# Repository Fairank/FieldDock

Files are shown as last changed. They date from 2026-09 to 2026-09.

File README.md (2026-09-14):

# FieldDock · Fairank / 年糕

面向 iPhone 17 Pro Max 的模块化无线与硬件实验工具。主板将 Sub-GHz、NFC、125 kHz RFID、红外、iButton、GPIO 和存储接口集中在 **94 × 40 mm** 的板上；手机承担未来的界面和结果处理。

**K 版全板布线与数字制造文件检查已完成。当前发布的是未制作、未上电的工程样板设计，尚未完成整机装配采购放行，也没有 Apple 认证或 Flipper 功能等效实测。**

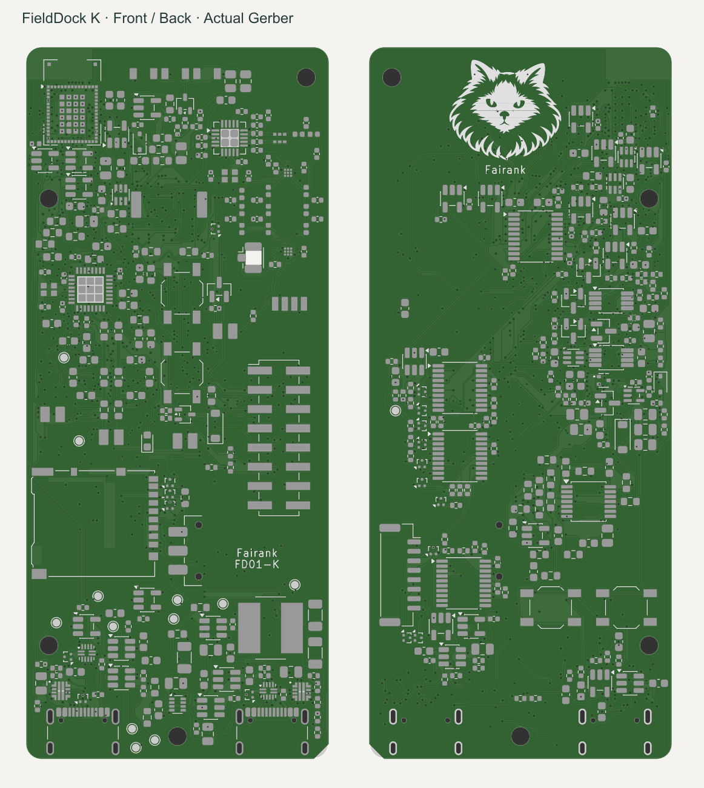
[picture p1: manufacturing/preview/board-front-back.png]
从实际 Gerber 渲染的主板正反面，带 Fairank 与年糕丝印


## 本次交付

| 内容 | 文件 | 当前状态 |
|---|---|---|
| 可编辑电路与 PCB | [KiCad 工程](cad/FD-MAIN-01.kicad_pro)、[主板](cad/FD-MAIN-01.kicad_pcb)、[22 页原理图 PDF](schematic/FieldDock-schematic-K.pdf) | 全板布线；KiCad 10.0.6 ERC/DRC 通过 |
| 制造资料 | [Gerber / 钻孔 ZIP](manufacturing/FieldDock-PCB-K-fabrication.zip)、[加工要求](manufacturing/PROCESS-K.md)、[文件说明](manufacturing/README.md) | 已导出并独立核对几何；供应商 CAM 接单确认待完成 |
| 元件与贴装 | [BOM 复核表](manufacturing/BOM-review.csv)、[395 件贴装坐标](manufacturing/FD-MAIN-01-populated-pos.csv) | 位置已核对；部分采购料号、替代料和底面角度约定待厂家确认 |
| 结构设计 | [STEP / STL 模型包](mechanical/FieldDock-mechanical-K.zip)、[参数与生成脚本](mechanical/) | 16 个零件及组件包络；安装孔对应一致，未做实物公差验证 |
| 基础驱动 | [C 驱动与主机测试](firmware/) | CC1101 识别读取、电源预算策略、GPIO 映射；没有完整可烧录固件 |
| 可审阅证据 | [发布状态](release-status.json)、[检查记录](checks/)、[验证说明](VALIDATION.md) | 对应本次文件哈希 |

## 检查结果

- PCB DRC：**0 未连接、0 错误、0 警告**；原理图 ERC：**0 违规**。启用范围与五项默认忽略规则保留在原始报告中，不表示所有可选规则都已执行。
- 原理图、最终 PCB 和布线模型：**1,260 个已分配引脚连接一致**；57 个明确标记的未使用引脚单独核对。
- 独立 Gerber/Excellon 解析：核对 **11,385 段走线、899 个贯穿过孔、907 个金属化钻孔/槽、10 个非金属化孔**，八层铜、外形和装配坐标一致。
- 机械包络检查：50 对检查对象，无非预期交叠；4 处自攻螺钉与底孔材料交叠为设计预期。它不包含尺寸公差、插拔力和线束弯曲验证。
- 基础驱动通过主机测试与 Cortex-M4 freestanding 对象编译；尚未链接整机镜像或上板测试。

```sh
python tools/verify_artifacts.py
python tools/verify_artifacts.py --release
```

第二条命令核验本版**裸 PCB 工程样板文件**的数字检查条件，不代表供应商已接单、整机可量产或硬件功能已通过。脚本不会自动运行 KiCad。

## 硬件范围

主控为 STM32WB5MMG，射频采用 CC1101 与 ST25R3916，并设 LF RFID、红外、iButton、隔离 GPIO、microSD 及反馈控制电路。Sub-GHz、NFC 和 LF 的完整协议、读写能力与距离需要固件和样板分别验证。

两个 USB-C 分别用于手机数据/低功率输入与 AUX 固定 5 V 辅助输入，包含电源选择、限流和反向电流保护设计。**本版不含电池；两个端口的电流预算不能相加。** USB 为全速 12 Mbit/s，iPhone App 的有线数据通道尚未完成。没有增加所谓“iPhone 芯片”。

CSI、雷达、UWB、宽带 SDR、热成像和镜头检查作为外部探头方向保留；本次主板发布不等于这些探头及其算法已全部实现。Flipper 官方功能是参考目标，并未复制其固件或宣称兼容替代。仓库不包含无线网络干扰功能。

八层、1.6 mm、沉金、所有贯穿过孔树脂填孔盖帽；使用 0.30/0.15 mm 和 0.35/0.20 mm 过孔。**0.15 mm 机械钻孔是非常规加价工艺**，须按 [加工规格](manufacturing/PROCESS-K.md) 单独确认，不能按普通双层板下单。主板下单前须让厂家确认最终 CAM、叠层、填孔和阻抗条件。

## 外壳与安装

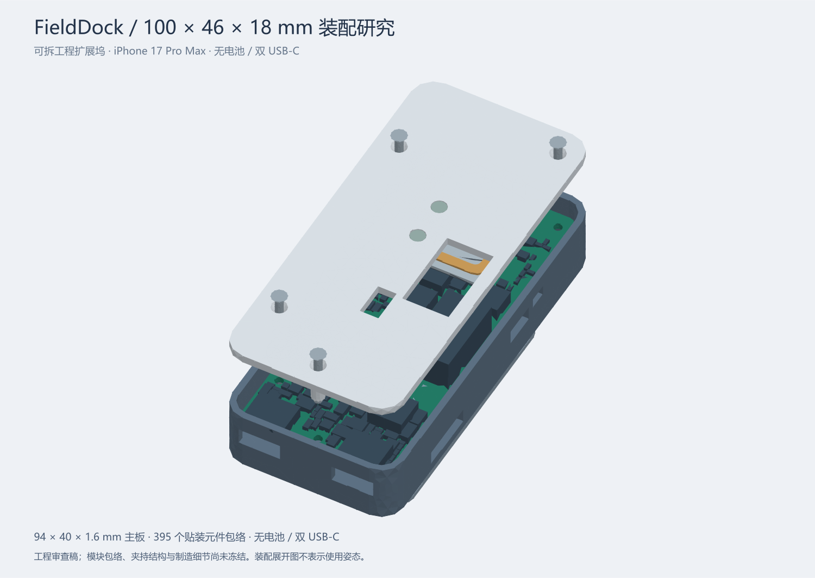
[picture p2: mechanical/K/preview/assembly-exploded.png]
机械组件与内部安装包络


外壳目标 100 × 46 × 18 mm，安装背板另占约 1.6 mm。提供参数化源码、装配 STEP 以及各零件 STEP/STL；内部电子元件使用保守包络，并非全部来自原厂的精确三维模型。接口插拔、手机摄像头避让、固定强度、天线线圈与装壳后的射频表现仍需试装。

## 预算与后续验证

[工程预算](manufacturing/BUDGET-K.md)：单套核心样机约 **¥1,534–3,820**；两套合计约 **¥2,049–4,941**。这些是估算，**均未包含尚未报价的 0.15 mm 钻孔附加费**，也不含手机、外部探头、射频调试和返版，不是最终价格上限。没有下单或取得厂家正式报价。

下一步是供应商 CAM 与料号确认、限流上电、电源切换/倒灌测试、射频与线圈调谐、手机通信以及外壳试装。详见 [验证顺序](VALIDATION.md)。原生图纸保留设计过程的标题栏版本；本次发布以 `release-status.json` 和文件校验清单确定对应关系。

## 署名和使用

Copyright © 2026 fairank，限其依法可保护并有权许可的原创贡献。年糕图标为本项目品牌。

原创贡献以 [FieldDock 非商业许可](LICENSE) 提供源码，个人可委托收费代工制作自用样机；对许可材料的商业使用需另行获得书面许可。这是 **noncommercial source-available** 项目，不使用 OSI 开源标识。KiCad 库及其衍生部分保留上游许可，见 [第三方说明](THIRD_PARTY_NOTICES.md) 和 [逐文件来源清单](licensing/library-inventory.csv)。不主张对通用电路方法、技术事实或独立实现的排他权。

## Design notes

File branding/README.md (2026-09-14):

# 共用年糕标志

唯一母版：niangao-master-v1.png。SHA256: 187738542cc2ea14bfb01165dacbc974479dd0d5b0aa6698a0179235dfb1e737。使用用户在关联设计任务明确选定、并授权两个任务同步的同一版本。

母版由内置 image_gen 参考年糕照片生成；共享 SVG / contours.json 为该母版的等比矢量化，未另画猫脸。本项目的早期小尺寸重绘试稿已停用。

当前 PCB：背面原图宽 14.8 mm，下方 Fairank；正面 Fairank 和 FD01-H。背面保留区域 16×16 mm。为 KiCad 分解的无孔多边形与母版轮廓总面积一致，原生绘图只落在丝印层。

细毛边缘和小空隙受实际丝印能力限制，仍需工艺样张确认；不能把软件几何检查当作印刷精度实测。电路、封装与铜层位置没有改变。

不随公开包提供用户照片或附件绝对路径。品牌资产本身的 AI 辅助来源须保留，不保证所有图像元素均有排他版权。

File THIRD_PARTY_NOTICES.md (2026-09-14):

# 第三方来源与发布范围

2026-09-09。本清单与 licensing/FILE-REVIEW.md、licensing/library-inventory.csv 共同记录本次文件审查范围，不把“网上公开”视为可任意再授权。

| 材料 | 已查明条件 | 本项目处理 |
|---|---|---|
| KiCad 官方符号、封装库及本地库集合 | CC BY-SA 4.0，电子设计适用库例外；重新分发库集合仍须保留其许可 | 保留 cad/licenses/KiCad-libraries-LICENSE.md；库集合不附加禁止商用限制；混合符号库中的两个 MOSFET 派生符号保留上游许可，其余项目自制符号按文件审查表区分 |
| Flipper 官方固件 | GPL-3.0，允许商业使用 | 当前新建基础驱动不复制该固件；未来若引入或构成衍生程序，须按其许可处理，不能统一改成 NC |
| Flipper 官方 3D 模型 | 官方仓库 LICENSE 为 GPL-3.0 | 不将其模型放入我们的 NC 模型包；当前外壳来自本项目参数化构造及元件包络，具体源文件边界见文件审查表 |
| Flipper 官方 iOS App | MIT | 尚未复制；若复用保留版权和许可证，不声称独占第三方实现 |
| Flipper 官方电路图 | 文档页写明 educational purposes only；未从该页面查得全套可再授权条款 | 当前 NFC/LF 电路参考过其拓扑，RF 参考过功能分区；本次逐项记录见 licensing/FILE-REVIEW.md；不分发官方电路图、固件、CAD 坐标或模型，不对参考功能、事实或上游作品附加本项目 NC 限制；不因重绘就宣称清除权利问题 |
| 元件厂商数据手册与参考电路 | 条款随厂商和具体资源不同 | 发布自行撰写的参数/接线解释和来源链接；工作目录中的 PDF、截图不自动打包 |
| KiCad、Freerouting、Java、Python、Zig 等工具 | 各有独立许可证 | 只用于生成和验证，不随项目源码包分发可执行文件和缓存；使用工具不等于复制其程序代码 |

依据：[KiCad 库许可](https://www.kicad.org/libraries/license/)、[Flipper 固件许可](https://github.com/flipperdevices/flipperzero-firmware/blob/dev/LICENSE)、[Flipper 模型许可](https://github.com/flipperdevices/flipperzero-3d-models/blob/master/LICENSE)、[Flipper iOS 许可](https://github.com/flipperdevices/Flipper-iOS-App/blob/dev/LICENSE)、[官方电路图说明](https://docs.flipper.net/zero/development/hardware/schematic)。

目录隔离只是工程整理方法，不能自动使本来构成衍生作品或组合程序的材料摆脱上游许可。

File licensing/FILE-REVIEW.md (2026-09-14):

# 发布文件的来源核查

2026-09-09。核查范围为当前项目源文件、生成方法及拟发布清单；本记录不承诺诉讼结果或排他技术权利。

- **电路描述和生成程序**：`radio_circuit.py`、`nfc_circuit.py`、`lf_circuit.py` 及其余电路文件是本项目编写的引脚表、连接表和生成代码。NFC/LF 的功能拓扑参考过 Flipper 公布的电路资料，RF 的功能分区亦有参考，必须保留这个来源说明。没有将 Flipper 的原 PDF、页面截图、原 CAD、丝印图或图纸坐标文件纳入发布。不能据此主张对相同功能、电气方法或元件数值的排他权；项目许可只覆盖可保护且由 fairank 有权许可的新增代码、文字和设计表达。
- **原生主板和原理图**：本项目的元件位置、线网命名、分页、布线、安装孔和品牌图形由本地设计过程产生。嵌入的 KiCad 符号与封装保持第三方来源，电子设计适用 KiCad 的库例外。禁止把独立库集合统一改成 NC。
- **标准 KiCad 库子集**：`cad/symbols/` 中除下述原创符号外的符号，以及 `cad/footprints/` 中标准库目录，适用 CC BY-SA 4.0 及 KiCad 库例外。作者为 KiCad 库贡献者；本项目执行了子集抽取、部分封装设置整理和引脚号调整。逐文件哈希及分类见 `library-inventory.csv`，原许可在 `cad/licenses/`。
- **混合符号库 `FieldDock.kicad_sym`**：`Q_PMOS_GSD_FD` 和 `Q_NMOS_GSD_FD` 是 KiCad MOSFET 符号的改名和引脚映射修改，继续适用 CC BY-SA 4.0 及库例外。本文件其余以矩形引脚表绘制的器件符号由项目编写，原创表达适用 FieldDock NC；库文件作为集合分发时必须保留两种许可及此逐符号说明，不得用 NC 限制其中的 KiCad 部分。
- **原创封装**：`FieldDock.pretty/` 的九个封装及 `MountingHole.pretty/MountingHole_2.4mm_M2.kicad_mod` 按器件尺寸和安装要求构造。其可保护的原创表达适用 NC；封装尺寸和通用焊盘规则是技术事实。
- **机械模型**：由本项目参数化盒体、孔、柱、盖、支架、线圈和保守器件包络构造。未导入 Flipper STEP/STL 文件。模型的尺寸与可制造性仍由机械检查和实物验证记录分别说明。
- **基础驱动**：CC1101 寄存器识别与电源许可状态逻辑为新写的 C 代码，未复制 Flipper GPL 固件。将来若引入 GPL 程序或构成其衍生实现，需另行按 GPL 处理，不能沿用 NC 覆盖上游代码。
- **品牌**：Fairank 署名及用户选定的 Niangao v1 母版。图形有 AI 辅助过程，不承诺所有部分自动取得著作权；不公开用户提供的猫照片、私人聊天或账号信息。
- **不随项目分发**：KiCad/Java/Freerouting/Zig/Python/Gmsh 可执行文件、插件、依赖缓存、厂商整份 PDF、网页截图、账户凭据和本地故障日志。

功能参考：[Flipper 官方电路资料](https://docs.flipper.net/zero/development/hardware/schematic)。库条件：[KiCad 官方许可说明](https://www.kicad.org/libraries/license/)。这些引用不代表上游授权 FieldDock 使用其商标、原始图纸或整个项目，也不代表任何上游认可本设计。

C712 uses `C_0402_1005Metric_FieldDock_NoSilk`, derived from the KiCad standard footprint with only its outline silk removed. Its land and courtyard geometry is unchanged. This derivative remains CC BY-SA 4.0 with the KiCad library exception, and is listed in the file inventory.

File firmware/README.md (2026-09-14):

# FieldDock 基础 C 驱动

Copyright (c) 2026 fairank。原创文件适用 LicenseRef-FieldDock-NC-1.0。未复制 Flipper 固件或 ST HAL 实现。

当前包含：CC1101 的 SPI PARTNUM/VERSION 读取、共享总线锁定及错误清理；双口供电预算纯函数；从当前原理图资源表生成的 60 个 GPIO 映射。来源是本项目接线表及 [TI CC1101 数据手册](https://www.ti.com/lit/ds/symlink/cc1101.pdf) 的协议事实。状态寄存器必须逐字节读取，每次头字节设置读和 burst 位，不能误用连续自增读取。

`fd_power_evaluate()` 只计算许可输出；实际电压检测、TUSB320LAI 寄存器读取、热点切换处理、上电等待、GPIO 顺序、USB 枚举、RTOS/中断和 STM32WB 启动链接均未实现。它不能独立控制硬件，也不能被称为可烧录整机固件。MCU 复位到主循环前的上拉/下拉和最低启动电流需硬件验证。

对缺失、过期或无效电源报告保持低额度；AUX 有电但额度不足时，不错误借用手机额度。核心电流预算不能把两个端口相加；外部探头只允许 AUX 3 A 广告条件，且仍受板上支路上限限制。预算常量来自当前阻值计算，样板实测后仍需复核。

编译：使用 C99 编译器把 `src/fd_cc1101.c`、`src/fd_power.c`、`tests/test_core.c` 一起编译，头文件路径设为 `include`，然后运行生成的主机测试程序。`tools/verify.py` 接受 Zig 可执行文件路径，将主机测试和 Cortex-M4 freestanding 对象编译结果保存到 build/。对象编译不是完整镜像链接、烧录或上板验证。

NFC、LF RFID、红外、iButton、microSD 和探头协议实现待后续添加；不会用空函数伪装成已支持功能。

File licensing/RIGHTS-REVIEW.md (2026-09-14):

# fairank 的非商业发布安排

目标：原创成果免费供非商业学习、修改和自用，商业使用另行取得书面许可。使用“源码公开 / source available”，不宣传为符合 OSI 定义的开源。OSI 定义不允许禁止商业领域使用。[OSI 定义第 6 条](https://opensource.org/osd)

当前采用项目专用 NC 条款，并为个人样机委托收费代工明确例外。否则“一律禁止盈利”会与我们需要找厂商加工相冲突。该条款只覆盖可由 fairank 许可的原创部分，不能覆盖第三方许可或不受著作权保护的技术思想。

工程图、模型和软件可能属于著作权保护对象，但需满足独创性等条件；署名和公开仓库不是胜诉保证。特别是 AI 辅助生成部分，应保存人的需求选择、设计修改、评审和实测记录，不宣称所有输出自动取得排他版权。[国家版权局公布的著作权法，第 3、11、12 条](https://www.ncac.gov.cn/xxfb/flfg/flfg_532/202103/t20210309_50530.html)

GPL 本身允许商业分发，不能给 GPL 衍生程序附加禁止商业用途的限制。需要独立实现、得到相关权利人的其他授权，或按上游许可发布相应作品；仅拆目录不足以解决衍生关系。[GNU GPL FAQ](https://www.gnu.org/licenses/gpl-faq.en.html)

本次具体文件的来源与许可边界记录在 FILE-REVIEW.md、library-inventory.csv 和 provenance.csv；任何后续引入的第三方材料均需更新此记录。项目专用授权是工程草案，不是诉讼结果保证；若商业排他和维权是关键目的，正式公开前适合由熟悉软件/硬件许可的律师审阅。不要上传完整聊天、账号邮箱、缓存、访问令牌或不必要的本机路径。

版权保护作品表达，并不当然垄断功能和技术方案；硬件制造、外观及技术方案还可能涉及专利、外观设计等不同权利。公开前需要决定是否另行评估这些权利，不能把 NC 文本当作已有专利。

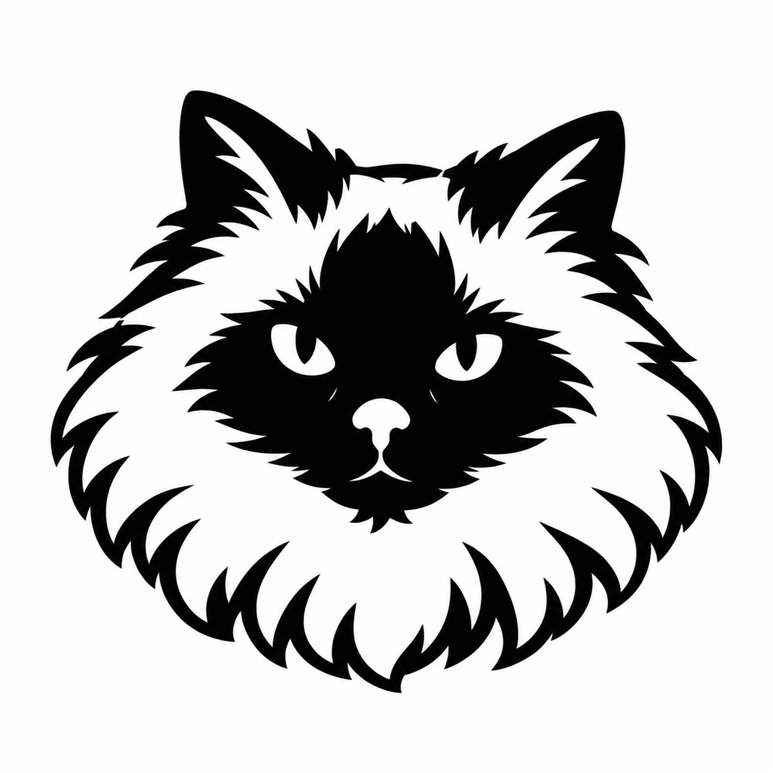
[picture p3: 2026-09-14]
branding/niangao-master-v1.png

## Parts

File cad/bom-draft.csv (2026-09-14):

Reference | Value | Footprint | Section | Status
U1 | STM32WB5MMGH6TR | RF_Module:ST-SiP-LGA-86-11x7.3mm | mcu | Engineering revision C
U2 | SN74LVC1G08DBVR | Package_TO_SOT_SMD:SOT-23-5 | controls | Engineering revision C
R1 | 0R analog feed | Resistor_SMD:R_0603_1608Metric | mcu | Engineering revision C
R2 | 10k BOOT pulldown | Resistor_SMD:R_0603_1608Metric | mcu | Engineering revision C
R3 | 10k | Resistor_SMD:R_0603_1608Metric | controls | Engineering revision C
R4 | 10k | Resistor_SMD:R_0603_1608Metric | controls | Engineering revision C
R5 | 100k | Resistor_SMD:R_0603_1608Metric | controls | Engineering revision C
R6 | 100k | Resistor_SMD:R_0603_1608Metric | controls | Engineering revision C
R7 | 100k | Resistor_SMD:R_0603_1608Metric | controls | Engineering revision C
R8 | 4.7k | Resistor_SMD:R_0603_1608Metric | mcu | Engineering revision C
R9 | 4.7k | Resistor_SMD:R_0603_1608Metric | mcu | Engineering revision C
R10 | 47k | Resistor_SMD:R_0603_1608Metric | mcu | Engineering revision C
R11 | 47k | Resistor_SMD:R_0603_1608Metric | mcu | Engineering revision C
R12 | 47k | Resistor_SMD:R_0603_1608Metric | mcu | Engineering revision C
R13 | 47k | Resistor_SMD:R_0603_1608Metric | mcu | Engineering revision C
R14 | 10k | Resistor_SMD:R_0603_1608Metric | mcu | Engineering revision C
R15 | 1k BOOT series | Resistor_SMD:R_0603_1608Metric | controls | Engineering revision C
R16 | 1k LED | Resistor_SMD:R_0603_1608Metric | controls | Engineering revision C
C1 | 4.7u 10V X7R | Capacitor_SMD:C_0805_2012Metric | mcu | Engineering revision C
C2 | 100n 10V X7R | Capacitor_SMD:C_0603_1608Metric | mcu | Engineering revision C
C3 | 1u 10V X7R | Capacitor_SMD:C_0603_1608Metric | mcu | Engineering revision C
C4 | 10n 10V X7R | Capacitor_SMD:C_0603_1608Metric | mcu | Engineering revision C
C5 | 100n RESET | Capacitor_SMD:C_0603_1608Metric | mcu | Engineering revision C
C6 | 100n USB supply | Capacitor_SMD:C_0603_1608Metric | mcu | Engineering revision C
C7 | 100n gate supply | Capacitor_SMD:C_0603_1608Metric | controls | Engineering revision C
C8 | 10u 10V X7R | Capacitor_SMD:C_0805_2012Metric | mcu | Engineering revision C
SW1 | RESET | Button_Switch_SMD:SW_SPST_TL3342 | controls | Engineering revision C
SW2 | CONFIRM | Button_Switch_SMD:SW_SPST_TL3342 | controls | Engineering revision C
SW3 | STOP_REQUEST | Button_Switch_SMD:SW_SPST_TL3342 | controls | Engineering revision C
SW4 | HARD_DISABLE / ALLOW | Button_Switch_SMD:SW_SPDT_CK_JS102011SAQN | controls | Engineering revision C
SW5 | BOOT_HOLD | Button_Switch_SMD:SW_SPST_TL3342 | controls | Engineering revision C
D1 | STATUS_LED | LED_SMD:LED_0603_1608Metric | controls | Engineering revision C
U201 | TPS2116DRLR | Package_TO_SOT_SMD:SOT-583-8 | core_power | Engineering revision C
R201 | 330k 1% | Resistor_SMD:R_0603_1608Metric | core_power | Engineering revision C
R202 | 100k 1% | Resistor_SMD:R_0603_1608Metric | core_power | Engineering revision C
R203 | 10k 1% | Resistor_SMD:R_0603_1608Metric | core_power | Engineering revision C
C201 | 4.7u 10V X7R | Capacitor_SMD:C_0805_2012Metric | core_power | Engineering revision C
C202 | 4.7u 10V X7R | Capacitor_SMD:C_0805_2012Metric | core_power | Engineering revision C
C203 | 22u 10V X7R | Capacitor_SMD:C_1206_3216Metric | core_power | Engineering revision C
U202 | AP63203WU-7 | Package_TO_SOT_SMD:TSOT-23-6 | core_power | Engineering revision C
L201 | 4.7uH SRN8040TA-4R7M | Inductor_SMD:L_Bourns_SRN8040TA | core_power | Engineering revision C
C204 | 100n 25V X7R | Capacitor_SMD:C_0402_1005Metric | core_power | Engineering revision C
C205 | 10u 10V X7R | Capacitor_SMD:C_0805_2012Metric | core_power | Engineering revision C
C206 | 22u 10V X7R | Capacitor_SMD:C_1206_3216Metric | core_power | Engineering revision C
C207 | 22u 10V X7R | Capacitor_SMD:C_1206_3216Metric | core_power | Engineering revision C
R204 | 0R FB sense | Resistor_SMD:R_0603_1608Metric | core_power | Engineering revision C
J101 | GCT USB4105-GF-A / PHONE USB2 FS + 5V | Connector_USB:USB_C_Receptacle_GCT_USB4105-xx-A_16P_TopMnt_Horizontal | phone_input | Engineering revision C
J102 | GCT USB4105-GF-A / AUX 5V input only | Connector_USB:USB_C_Receptacle_GCT_USB4105-xx-A_16P_TopMnt_Horizontal | aux_input | Engineering revision C
D101 | TPD2EUSB30DRTR | Package_TO_SOT_SMD:Texas_DRT-3 | phone_input | Engineering revision C
U301 | TPS22919DCKR | Package_TO_SOT_SMD:SOT-363_SC-70-6 | storage | Engineering revision C
U302 | 74LVC125APW,118 Nexperia | Package_SO:TSSOP-14_4.4x5mm_P0.65mm | storage | Engineering revision C
U303 | SN74LVC1G32DBVR | Package_TO_SOT_SMD:SOT-23-5 | storage | Engineering revision C
J301 | DM3AT-SF-PEJM5 | Connector_Card:microSD_HC_Hirose_DM3AT-SF-PEJM5 | storage | Engineering revision C
D301 | TPD2EUSB30DRTR | Package_TO_SOT_SMD:Texas_DRT-3 | storage | Engineering revision C
D302 | TPD2EUSB30DRTR | Package_TO_SOT_SMD:Texas_DRT-3 | storage | Engineering revision C
D303 | TPD2EUSB30DRTR | Package_TO_SOT_SMD:Texas_DRT-3 | storage | Engineering revision C
R301 | 100R QOD | Resistor_SMD:R_0603_1608Metric | storage | Engineering revision C
R302 | 100k | Resistor_SMD:R_0603_1608Metric | storage | Engineering revision C
R303 | 22R clock damping | Resistor_SMD:R_0603_1608Metric | storage | Engineering revision C
R304 | 22R command damping | Resistor_SMD:R_0603_1608Metric | storage | Engineering revision C
R305 | 22R MISO damping | Resistor_SMD:R_0603_1608Metric | storage | Engineering revision C
R306 | 10k default isolated | Resistor_SMD:R_0603_1608Metric | storage | Engineering revision C
R307 | 47k | Resistor_SMD:R_0603_1608Metric | storage | Engineering revision C
R308 | 47k | Resistor_SMD:R_0603_1608Metric | storage | Engineering revision C
R309 | 47k | Resistor_SMD:R_0603_1608Metric | storage | Engineering revision C
R310 | 47k | Resistor_SMD:R_0603_1608Metric | storage | Engineering revision C
R311 | 47k | Resistor_SMD:R_0603_1608Metric | storage | Engineering revision C
R312 | 47k | Resistor_SMD:R_0603_1608Metric | storage | Engineering revision C
R313 | 1k detect series | Resistor_SMD:R_0603_1608Metric | storage | Engineering revision C
R314 | 100k | Resistor_SMD:R_0603_1608Metric | storage | Engineering revision C
R315 | 100k | Resistor_SMD:R_0603_1608Metric | storage | Engineering revision C
R316 | 10k | Resistor_SMD:R_0603_1608Metric | storage | Engineering revision C
C301 | 1u 10V X7R | Capacitor_SMD:C_0603_1608Metric | storage | Engineering revision C
C302 | 10u 10V X7R | Capacitor_SMD:C_0805_2012Metric | storage | Engineering revision C
C303 | 100n 10V X7R | Capacitor_SMD:C_0603_1608Metric | storage | Engineering revision C
C304 | 100n 10V X7R | Capacitor_SMD:C_0603_1608Metric | storage | Engineering revision C
C305 | 100n 10V X7R | Capacitor_SMD:C_0603_1608Metric | storage | Engineering revision C
C306 | 10n detect filter | Capacitor_SMD:C_0603_1608Metric | storage | Engineering revision C
U110 | TUSB320LAIRWBR | Package_DFN_QFN:Texas_X2QFN-12_1.6x1.6mm_P0.4mm | phone_input | Engineering revision C
R110 | 887k 1% | Resistor_SMD:R_0402_1005Metric | phone_input | Engineering revision C
C110 | 100n 10V X7R | Capacitor_SMD:C_0603_1608Metric | phone_input | Engineering revision C
D110 | TPD2EUSB30DRTR | Package_TO_SOT_SMD:Texas_DRT-3 | phone_input | Engineering revision C
U111 | TPS259470LRPWR | FieldDock:Texas_RPW0010A | phone_input | Engineering revision C
R112 | 470k 1% | Resistor_SMD:R_0402_1005Metric | phone_input | Engineering revision C
R113 | 34.8k 0.1% | Resistor_SMD:R_0402_1005Metric | phone_input | Engineering revision C
R114 | 10.0k 0.1% | Resistor_SMD:R_0402_1005Metric | phone_input | Engineering revision C
R115 | 6.65k 1% | Resistor_SMD:R_0402_1005Metric | phone_input | Engineering revision C
C111 | 1u 50V X7R | Capacitor_SMD:C_0805_2012Metric | phone_input | Engineering revision C
C112 | 10n 50V X7R | Capacitor_SMD:C_0603_1608Metric | phone_input | Engineering revision C
C113 | 1u 10V X7R | Capacitor_SMD:C_0603_1608Metric | phone_input | Engineering revision C
U112 | TPS2553DBVR | Package_TO_SOT_SMD:SOT-23-6 | phone_input | Engineering revision C
U113 | TS5A3159ADBVR | Package_TO_SOT_SMD:SOT-23-6 | phone_input | Engineering revision C
R116 | 64.9k 1% | Resistor_SMD:R_0402_1005Metric | phone_input | Engineering revision C
U114 | SN74LVC1G08DBVR | Package_TO_SOT_SMD:SOT-23-5 | phone_input | Engineering revision C
R117 | 100k 1% | Resistor_SMD:R_0402_1005Metric | phone_input | Engineering revision C
R118 | 100k 1% | Resistor_SMD:R_0402_1005Metric | phone_input | Engineering revision C
C114 | 100n 10V X7R | Capacitor_SMD:C_0603_1608Metric | phone_input | Engineering revision C
C115 | 100n 10V X7R | Capacitor_SMD:C_0603_1608Metric | phone_input | Engineering revision C
R119 | 100k 1% | Resistor_SMD:R_0402_1005Metric | phone_input | Engineering revision C
R120 | 100k 1% | Resistor_SMD:R_0402_1005Metric | phone_input | Engineering revision C
U150 | TUSB320LAIRWBR | Package_DFN_QFN:Texas_X2QFN-12_1.6x1.6mm_P0.4mm | aux_input | Engineering revision C
R150 | 887k 1% | Resistor_SMD:R_0402_1005Metric | aux_input | Engineering revision C
C150 | 100n 10V X7R | Capacitor_SMD:C_0603_1608Metric | aux_input | Engineering revision C
R151 | 4.7k 1% | Resistor_SMD:R_0402_1005Metric | aux_input | Engineering revision C
D150 | TPD2EUSB30DRTR | Package_TO_SOT_SMD:Texas_DRT-3 | aux_input | Engineering revision C
U151 | TPS259470LRPWR | FieldDock:Texas_RPW0010A | aux_input | Engineering revision C
R152 | 470k 1% | Resistor_SMD:R_0402_1005Metric | aux_input | Engineering revision C
R153 | 34.8k 0.1% | Resistor_SMD:R_0402_1005Metric | aux_input | Engineering revision C
R154 | 10.0k 0.1% | Resistor_SMD:R_0402_1005Metric | aux_input | Engineering revision C
R155 | 1.65k 1% | Resistor_SMD:R_0402_1005Metric | aux_input | Engineering revision C
C151 | 1u 50V X7R | Capacitor_SMD:C_0805_2012Metric | aux_input | Engineering revision C
C152 | 10n 50V X7R | Capacitor_SMD:C_0603_1608Metric | aux_input | Engineering revision C
C153 | 1u 10V X7R | Capacitor_SMD:C_0603_1608Metric | aux_input | Engineering revision C
U152 | TPS2553DBVR | Package_TO_SOT_SMD:SOT-23-6 | aux_input | Engineering revision C
U153 | TS5A3159ADBVR | Package_TO_SOT_SMD:SOT-23-6 | aux_input | Engineering revision C
R156 | 34.0k 1% | Resistor_SMD:R_0402_1005Metric | aux_input | Engineering revision C
U154 | SN74LVC1G08DBVR | Package_TO_SOT_SMD:SOT-23-5 | aux_input | Engineering revision C
R157 | 100k 1% | Resistor_SMD:R_0402_1005Metric | aux_input | Engineering revision C
R158 | 100k 1% | Resistor_SMD:R_0402_1005Metric | aux_input | Engineering revision C
C154 | 100n 10V X7R | Capacitor_SMD:C_0603_1608Metric | aux_input | Engineering revision C
C155 | 100n 10V X7R | Capacitor_SMD:C_0603_1608Metric | aux_input | Engineering revision C
R159 | 100k 1% | Resistor_SMD:R_0402_1005Metric | aux_input | Engineering revision C
R160 | 100k 1% | Resistor_SMD:R_0402_1005Metric | aux_input | Engineering revision C
U190 | TPS3700DDCR | Package_TO_SOT_SMD:SOT-23-6 | power_control | Engineering revision C
R190 | 324k 1% | Resistor_SMD:R_0402_1005Metric | power_control | Engineering revision C
R191 | 33.2k 1% | Resistor_SMD:R_0402_1005Metric | power_control | Engineering revision C
C190 | 1n 50V C0G | Capacitor_SMD:C_0603_1608Metric | power_control | Engineering revision C
R194 | 324k 1% | Resistor_SMD:R_0402_1005Metric | power_control | Engineering revision C
R195 | 33.2k 1% | Resistor_SMD:R_0402_1005Metric | power_control | Engineering revision C
C194 | 1n 50V C0G | Capacitor_SMD:C_0603_1608Metric | power_control | Engineering revision C
R192 | 10k 1% | Resistor_SMD:R_0402_1005Metric | power_control | Engineering revision C
R193 | 10k 1% | Resistor_SMD:R_0402_1005Metric | power_control | Engineering revision C
U191 | SN74LVC1G04DBVR | Package_TO_SOT_SMD:SOT-23-5 | power_control | Engineering revision C
C191 | 100n 10V X7R | Capacitor_SMD:C_0603_1608Metric | power_control | Engineering revision C
C192 | 100n 10V X7R | Capacitor_SMD:C_0603_1608Metric | power_control | Engineering revision C
R196 | 10k 1% | Resistor_SMD:R_0402_1005Metric | power_control | Engineering revision C
U192 | SN74LVC1G08DBVR | Package_TO_SOT_SMD:SOT-23-5 | power_control | Engineering revision C
U193 | SN74LVC1G08DBVR | Package_TO_SOT_SMD:SOT-23-5 | power_control | Engineering revision C
U194 | SN74LVC1G08DBVR | Package_TO_SOT_SMD:SOT-23-5 | power_control | Engineering revision C
R197 | 100k 1% | Resistor_SMD:R_0402_1005Metric | power_control | Engineering revision C
R198 | 100k 1% | Resistor_SMD:R_0402_1005Metric | power_control | Engineering revision C
R199 | 100k 1% | Resistor_SMD:R_0402_1005Metric | power_control | Engineering revision C
C195 | 100n 10V X7R | Capacitor_SMD:C_0603_1608Metric | power_control | Engineering revision C
C196 | 100n 10V X7R | Capacitor_SMD:C_0603_1608Metric | power_control | Engineering revision C
C197 | 100n 10V X7R | Capacitor_SMD:C_0603_1608Metric | power_control | Engineering revision C
U195 | TPS2553DBVR | Package_TO_SOT_SMD:SOT-23-6 | power_control | Engineering revision C
R180 | 34.0k 1% | Resistor_SMD:R_0402_1005Metric | power_control | Engineering revision C
R181 | 100k 1% | Resistor_SMD:R_0402_1005Metric | power_control | Engineering revision C
C180 | 1u 10V X7R | Capacitor_SMD:C_0603_1608Metric | power_control | Engineering revision C
C181 | 10u 10V X7R | Capacitor_SMD:C_0805_2012Metric | power_control | Engineering revision C
R182 | 1k 1% | Resistor_SMD:R_0402_1005Metric | power_control | Engineering revision C
U400 | TPS22919DCKR | Package_TO_SOT_SMD:SOT-363_SC-70-6 | rf_power_isolation | Engineering revision C
R400 | 100R | Resistor_SMD:R_0402_1005Metric | rf_power_isolation | Engineering revision C
C400 | 1u 10V X7R | Capacitor_SMD:C_0603_1608Metric | rf_power_isolation | Engineering revision C
C401 | 4.7u 10V X7R | Capacitor_SMD:C_0603_1608Metric | rf_power_isolation | Engineering revision C
U401 | SN74LVC1G08DBVR | Package_TO_SOT_SMD:SOT-23-5 | rf_power_isolation | Engineering revision C
U402 | SN74LVC1G04DBVR | Package_TO_SOT_SMD:SOT-23-5 | rf_power_isolation | Engineering revision C
R401 | 100k | Resistor_SMD:R_0402_1005Metric | rf_power_isolation | Engineering revision C
R402 | 10k | Resistor_SMD:R_0402_1005Metric | rf_power_isolation | Engineering revision C
R403 | 100k | Resistor_SMD:R_0402_1005Metric | rf_power_isolation | Engineering revision C
C402 | 100n 10V X7R | Capacitor_SMD:C_0402_1005Metric | rf_power_isolation | Engineering revision C
C403 | 100n 10V X7R | Capacitor_SMD:C_0402_1005Metric | rf_power_isolation | Engineering revision C
C404 | 100n 10V X7R | Capacitor_SMD:C_0402_1005Metric | rf_power_isolation | Engineering revision C
U403 | SN74CB3T3245PWR | Package_SO:TSSOP-20_4.4x6.5mm_P0.65mm | rf_power_isolation | Engineering revision C
R404 | 47k | Resistor_SMD:R_0402_1005Metric | rf_power_isolation | Engineering revision C
R405 | 47k | Resistor_SMD:R_0402_1005Metric | rf_power_isolation | Engineering revision C
R406 | 100k | Resistor_SMD:R_0402_1005Metric | rf_power_isolation | Engineering revision C
R407 | 100k | Resistor_SMD:R_0402_1005Metric | rf_power_isolation | Engineering revision C
R408 | 100k | Resistor_SMD:R_0402_1005Metric | rf_power_isolation | Engineering revision C
R409 | 100k | Resistor_SMD:R_0402_1005Metric | rf_power_isolation | Engineering revision C
R410 | 100k | Resistor_SMD:R_0402_1005Metric | rf_power_isolation | Engineering revision C
U430 | CC1101RGPT | Package_DFN_QFN:Texas_RGP0020H_VQFN-20-1EP_4x4mm_P0.5mm_EP2.4x2.4mm | subghz | Engineering revision C
Y430 | XRCGB26M000F3M00R0 26MHz CL6pF | FieldDock:Murata_XRCGB_2016 | subghz | Engineering revision C
C430 | 9p C0G 50V initial CL trim | Capacitor_SMD:C_0402_1005Metric | subghz | Engineering revision C
C431 | 9p C0G 50V initial CL trim | Capacitor_SMD:C_0402_1005Metric | subghz | Engineering revision C
R430 | 56k 1% | Resistor_SMD:R_0402_1005Metric | subghz | Engineering revision C
C432 | 100n 10V X7R | Capacitor_SMD:C_0402_1005Metric | subghz | Engineering revision C
C433 | 100n 10V X7R | Capacitor_SMD:C_0402_1005Metric | subghz | Engineering revision C
C434 | 100n 10V X7R | Capacitor_SMD:C_0402_1005Metric | subghz | Engineering revision C
C435 | 100n 10V X7R | Capacitor_SMD:C_0402_1005Metric | subghz | Engineering revision C
C436 | 100n 10V X7R | Capacitor_SMD:C_0402_1005Metric | subghz | Engineering revision C
C437 | 100n 10V X7R | Capacitor_SMD:C_0402_1005Metric | subghz | Engineering revision C
C438 | 100n 10V X7R | Capacitor_SMD:C_0402_1005Metric | subghz | Engineering revision C
C439 | 2.2u 10V X7R | Capacitor_SMD:C_0603_1608Metric | subghz | Engineering revision C
C440 | 100p C0G 50V | Capacitor_SMD:C_0402_1005Metric | subghz | Engineering revision C
C441 | 100p C0G 50V | Capacitor_SMD:C_0402_1005Metric | subghz | Engineering revision C
T430 | B0310J50100AHF | FieldDock:TTM_B0310J50100AHF | subghz | Engineering revision C
L430 | 3.3nH 0.2nH RF | Inductor_SMD:L_0402_1005Metric | subghz | Engineering revision C
L431 | 6.8nH 0.2nH RF | Inductor_SMD:L_0402_1005Metric | subghz | Engineering revision C
C442 | 1.2p C0G 0.1p 50V | Capacitor_SMD:C_0402_1005Metric | subghz | Engineering revision C
C443 | DNP C0G matching trim | Capacitor_SMD:C_0402_1005Metric | subghz | Engineering revision C
C444 | DNP C0G matching trim | Capacitor_SMD:C_0402_1005Metric | subghz | Engineering revision C
C445 | DNP C0G matching trim | Capacitor_SMD:C_0402_1005Metric | subghz | Engineering revision C
U431 | BGS13S4N9E6327XTSA1 | FieldDock:Infineon_TSNP9_1.1x1.1_P0.4 | subghz | Engineering revision C
U432 | BGS13S4N9E6327XTSA1 | FieldDock:Infineon_TSNP9_1.1x1.1_P0.4 | subghz | Engineering revision C
C446 | 10n 10V X7R | Capacitor_SMD:C_0402_1005Metric | subghz | Engineering revision C
C447 | 10n 10V X7R | Capacitor_SMD:C_0402_1005Metric | subghz | Engineering revision C
R431 | 100k | Resistor_SMD:R_0402_1005Metric | subghz | Engineering revision C
L440 | 12nH 5% RF | Inductor_SMD:L_0402_1005Metric | subghz | Engineering revision C
L441 | 39nH 5% RF | Inductor_SMD:L_0402_1005Metric | subghz | Engineering revision C
L442 | 12nH 5% RF | Inductor_SMD:L_0402_1005Metric | subghz | Engineering revision C
C450 | 12p C0G 2% 50V | Capacitor_SMD:C_0402_1005Metric | subghz | Engineering revision C
C451 | 12p C0G 2% 50V | Capacitor_SMD:C_0402_1005Metric | subghz | Engineering revision C
L443 | 8.2nH 5% RF | Inductor_SMD:L_0402_1005Metric | subghz | Engineering revision C
L444 | 27nH 5% RF | Inductor_SMD:L_0402_1005Metric | subghz | Engineering revision C
L445 | 8.2nH 5% RF | Inductor_SMD:L_0402_1005Metric | subghz | Engineering revision C
C452 | 8.2p C0G 2% 50V | Capacitor_SMD:C_0402_1005Metric | subghz | Engineering revision C
C453 | 8.2p C0G 2% 50V | Capacitor_SMD:C_0402_1005Metric | subghz | Engineering revision C
L446 | 4.3nH 5% RF | Inductor_SMD:L_0402_1005Metric | subghz | Engineering revision C
L447 | 13nH 5% RF | Inductor_SMD:L_0402_1005Metric | subghz | Engineering revision C
L448 | 4.3nH 5% RF | Inductor_SMD:L_0402_1005Metric | subghz | Engineering revision C
C454 | 4.3p C0G 2% 50V | Capacitor_SMD:C_0402_1005Metric | subghz | Engineering revision C
C455 | 4.3p C0G 2% 50V | Capacitor_SMD:C_0402_1005Metric | subghz | Engineering revision C
R432 | 0R antenna matching link | Resistor_SMD:R_0402_1005Metric | subghz | Engineering revision C
J430 | U.FL-R-SMT-1(10) / 50R antenna | Connector_Coaxial:U.FL_Hirose_U.FL-R-SMT-1_Vertical | subghz | Engineering revision C
U500 | ST25R3916-AQWT | FieldDock:ST_VFQFPN32_5x5_EP3.5 | nfc | Engineering revision C
Y500 | XRCGB27M120F3M00R0 27.12MHz CL6pF | FieldDock:Murata_XRCGB_2016 | nfc | Engineering revision C
C500 | 6p C0G 50V | Capacitor_SMD:C_0402_1005Metric | nfc | Engineering revision C
C501 | 6p C0G 50V | Capacitor_SMD:C_0402_1005Metric | nfc | Engineering revision C
C502 | 10n 10V X7R | Capacitor_SMD:C_0402_1005Metric | nfc | Engineering revision C
C503 | 2.2u 10V X7R | Capacitor_SMD:C_0603_1608Metric | nfc | Engineering revision C
C504 | 10n 10V X7R | Capacitor_SMD:C_0402_1005Metric | nfc | Engineering revision C
C505 | 2.2u 10V X7R | Capacitor_SMD:C_0603_1608Metric | nfc | Engineering revision C
C506 | 10n 10V X7R | Capacitor_SMD:C_0402_1005Metric | nfc | Engineering revision C
C507 | 2.2u 10V X7R | Capacitor_SMD:C_0603_1608Metric | nfc | Engineering revision C
C508 | 10n 10V X7R | Capacitor_SMD:C_0402_1005Metric | nfc | Engineering revision C
C509 | 2.2u 10V X7R | Capacitor_SMD:C_0603_1608Metric | nfc | Engineering revision C
C510 | 10n 10V X7R | Capacitor_SMD:C_0402_1005Metric | nfc | Engineering revision C
C511 | 2.2u 10V X7R | Capacitor_SMD:C_0603_1608Metric | nfc | Engineering revision C
C512 | 1u 10V X7R | Capacitor_SMD:C_0603_1608Metric | nfc | Engineering revision C
C513 | 10n 10V X7R | Capacitor_SMD:C_0402_1005Metric | nfc | Engineering revision C
L500 | 270nH 5% RF wirewound | Inductor_SMD:L_0603_1608Metric | nfc | Engineering revision C
C520 | 680p C0G 50V | Capacitor_SMD:C_0603_1608Metric | nfc | Engineering revision C
C521 | 100p C0G 100V | Capacitor_SMD:C_0603_1608Metric | nfc | Engineering revision C
C522 | 62p C0G 100V | Capacitor_SMD:C_0603_1608Metric | nfc | Engineering revision C
C523 | 10p C0G 100V | Capacitor_SMD:C_0603_1608Metric | nfc | Engineering revision C
C524 | 100p C0G 50V | Capacitor_SMD:C_0603_1608Metric | nfc | Engineering revision C
R500 | 0R antenna tuning link | Resistor_SMD:R_0603_1608Metric | nfc | Engineering revision C
C530 | DNP C0G trim | Capacitor_SMD:C_0603_1608Metric | nfc | Engineering revision C
L501 | 270nH 5% RF wirewound | Inductor_SMD:L_0603_1608Metric | nfc | Engineering revision C
C525 | 680p C0G 50V | Capacitor_SMD:C_0603_1608Metric | nfc | Engineering revision C
C526 | 100p C0G 100V | Capacitor_SMD:C_0603_1608Metric | nfc | Engineering revision C
C527 | 62p C0G 100V | Capacitor_SMD:C_0603_1608Metric | nfc | Engineering revision C
C528 | 10p C0G 100V | Capacitor_SMD:C_0603_1608Metric | nfc | Engineering revision C
C529 | 100p C0G 50V | Capacitor_SMD:C_0603_1608Metric | nfc | Engineering revision C
R501 | 0R antenna tuning link | Resistor_SMD:R_0603_1608Metric | nfc | Engineering revision C
C531 | DNP C0G trim | Capacitor_SMD:C_0603_1608Metric | nfc | Engineering revision C
J500 | NFC antenna 1.37uH nominal / soldered twisted pair | FieldDock:Antenna_2Pad_2mm | nfc | Engineering revision C
U600 | SN74LVC1G08DBVR | Package_TO_SOT_SMD:SOT-23-5 | lf_rfid | Engineering revision C
U601 | SN74LVC1G08DBVR | Package_TO_SOT_SMD:SOT-23-5 | lf_rfid | Engineering revision C
U602 | TPS22919DCKR | Package_TO_SOT_SMD:SOT-363_SC-70-6 | lf_rfid | Engineering revision C
R600 | 100R | Resistor_SMD:R_0402_1005Metric | lf_rfid | Engineering revision C
C600 | 1u 10V X7R | Capacitor_SMD:C_0603_1608Metric | lf_rfid | Engineering revision C
C601 | 4.7u 10V X7R | Capacitor_SMD:C_0603_1608Metric | lf_rfid | Engineering revision C
C602 | 100n 10V X7R | Capacitor_SMD:C_0402_1005Metric | lf_rfid | Engineering revision C
C603 | 100n 10V X7R | Capacitor_SMD:C_0402_1005Metric | lf_rfid | Engineering revision C
R601 | 100k | Resistor_SMD:R_0402_1005Metric | lf_rfid | Engineering revision C
R602 | 100k | Resistor_SMD:R_0402_1005Metric | lf_rfid | Engineering revision C
Q600 | DMP2004K-7 | Package_TO_SOT_SMD:SOT-23 | lf_rfid | Engineering revision C
Q601 | DMN2004K-7 | Package_TO_SOT_SMD:SOT-23 | lf_rfid | Engineering revision C
Q602 | DMN2004K-7 | Package_TO_SOT_SMD:SOT-23 | lf_rfid | Engineering revision C
R603 | 4.7R 1% 0.25W | Resistor_SMD:R_0805_2012Metric | lf_rfid | Engineering revision C
R604 | 4.7R 1% 0.25W | Resistor_SMD:R_0805_2012Metric | lf_rfid | Engineering revision C
R605 | 510R 1% | Resistor_SMD:R_0402_1005Metric | lf_rfid | Engineering revision C
R606 | 51R | Resistor_SMD:R_0402_1005Metric | lf_rfid | Engineering revision C
R607 | 10k | Resistor_SMD:R_0402_1005Metric | lf_rfid | Engineering revision C
C604 | 3.3n C0G 100V | Capacitor_SMD:C_0805_2012Metric | lf_rfid | Engineering revision C
C605 | DNP C0G 100V trim | Capacitor_SMD:C_0805_2012Metric | lf_rfid | Engineering revision C
J600 | LF coil ~500uH / soldered twisted pair | FieldDock:Antenna_2Pad_2mm | lf_rfid | Engineering revision C
D600 | 1N4148W-7-F | Diode_SMD:D_SOD-123 | lf_rfid | Engineering revision C
D601 | MM3Z33VT1G 33V | Diode_SMD:D_SOD-323 | lf_rfid | Engineering revision C
R608 | 330k 1% | Resistor_SMD:R_0402_1005Metric | lf_rfid | Engineering revision C
C606 | 10n X7R 100V | Capacitor_SMD:C_0603_1608Metric | lf_rfid | Engineering revision C
R609 | 5.1k | Resistor_SMD:R_0402_1005Metric | lf_rfid | Engineering revision C
C607 | 1n C0G 100V | Capacitor_SMD:C_0603_1608Metric | lf_rfid | Engineering revision C
C608 | 220n X7R 100V | Capacitor_SMD:C_0805_2012Metric | lf_rfid | Engineering revision C
U603 | SN74LVC1G08DBVR | Package_TO_SOT_SMD:SOT-23-5 | lf_rfid | Engineering revision C
C609 | 100n 10V X7R | Capacitor_SMD:C_0402_1005Metric | lf_rfid | Engineering revision C
Q603 | DMN5L06TK-7 | Package_TO_SOT_SMD:SOT-523 | lf_rfid | Engineering revision C
R610 | 440R | Resistor_SMD:R_0402_1005Metric | lf_rfid | Engineering revision C
R611 | 100k | Resistor_SMD:R_0402_1005Metric | lf_rfid | Engineering revision C
R612 | 330R 0.25W | Resistor_SMD:R_0805_2012Metric | lf_rfid | Engineering revision C
R613 | 10R | Resistor_SMD:R_0402_1005Metric | lf_rfid | Engineering revision C
C610 | 1u 10V X7R | Capacitor_SMD:C_0603_1608Metric | lf_rfid | Engineering revision C
U604 | LMV358AIDGKR | Package_SO:VSSOP-8_3x3mm_P0.65mm | lf_rfid | Engineering revision C
R614 | 33k 1% | Resistor_SMD:R_0402_1005Metric | lf_rfid | Engineering revision C
R615 | 33k 1% | Resistor_SMD:R_0402_1005Metric | lf_rfid | Engineering revision C
C611 | 1u 10V X7R | Capacitor_SMD:C_0603_1608Metric | lf_rfid | Engineering revision C
R616 | 1M 1% | Resistor_SMD:R_0402_1005Metric | lf_rfid | Engineering revision C
R617 | 1k 1% | Resistor_SMD:R_0402_1005Metric | lf_rfid | Engineering revision C
R618 | 4.7k 1% | Resistor_SMD:R_0402_1005Metric | lf_rfid | Engineering revision C
C612 | 100n 10V X7R | Capacitor_SMD:C_0402_1005Metric | lf_rfid | Engineering revision C
U605 | LMV358AIDGKR | Package_SO:VSSOP-8_3x3mm_P0.65mm | lf_rfid | Engineering revision C
C613 | 100n 10V X7R | Capacitor_SMD:C_0402_1005Metric | lf_rfid | Engineering revision C
R620 | 1k 1% | Resistor_SMD:R_0402_1005Metric | lf_rfid | Engineering revision C
R621 | 1k 1% | Resistor_SMD:R_0402_1005Metric | lf_rfid | Engineering revision C
R622 | 10k 1% | Resistor_SMD:R_0402_1005Metric | lf_rfid | Engineering revision C
C620 | 4.7n C0G 50V | Capacitor_SMD:C_0402_1005Metric | lf_rfid | Engineering revision C
C621 | 100p C0G 50V | Capacitor_SMD:C_0402_1005Metric | lf_rfid | Engineering revision C
R623 | 1k 1% | Resistor_SMD:R_0402_1005Metric | lf_rfid | Engineering revision C
R624 | 1k 1% | Resistor_SMD:R_0402_1005Metric | lf_rfid | Engineering revision C
R625 | 10k 1% | Resistor_SMD:R_0402_1005Metric | lf_rfid | Engineering revision C
C622 | 4.7n C0G 50V | Capacitor_SMD:C_0402_1005Metric | lf_rfid | Engineering revision C
C623 | 100p C0G 50V | Capacitor_SMD:C_0402_1005Metric | lf_rfid | Engineering revision C
R626 | 33k 1% | Resistor_SMD:R_0402_1005Metric | lf_rfid | Engineering revision C
R627 | 20k 1% | Resistor_SMD:R_0402_1005Metric | lf_rfid | Engineering revision C
C624 | 100p C0G 50V | Capacitor_SMD:C_0402_1005Metric | lf_rfid | Engineering revision C
U606 | LMV331IDCKR | Package_TO_SOT_SMD:SOT-353_SC-70-5 | lf_rfid | Engineering revision C
R628 | 330k 1% | Resistor_SMD:R_0402_1005Metric | lf_rfid | Engineering revision C
R629 | 10k | Resistor_SMD:R_0402_1005Metric | lf_rfid | Engineering revision C
C625 | 100n 10V X7R | Capacitor_SMD:C_0402_1005Metric | lf_rfid | Engineering revision C
D602 | BAT54S,215 | Package_TO_SOT_SMD:SOT-23 | lf_rfid | Engineering revision C
D603 | BAT54S,215 | Package_TO_SOT_SMD:SOT-23 | lf_rfid | Engineering revision C
U700 | SN74CB3T3245PWR | Package_SO:TSSOP-20_4.4x6.5mm_P0.65mm | gpio_tools | Engineering revision C
C700 | 100n 10V X7R | Capacitor_SMD:C_0402_1005Metric | gpio_tools | Engineering revision C
U701 | SN74CB3T3245PWR | Package_SO:TSSOP-20_4.4x6.5mm_P0.65mm | gpio_tools | Engineering revision C
C701 | 100n 10V X7R | Capacitor_SMD:C_0402_1005Metric | gpio_tools | Engineering revision C
R700 | 51R | Resistor_SMD:R_0402_1005Metric | gpio_tools | Engineering revision C
R701 | 51R | Resistor_SMD:R_0402_1005Metric | gpio_tools | Engineering revision C
R702 | 51R | Resistor_SMD:R_0402_1005Metric | gpio_tools | Engineering revision C
R703 | 51R | Resistor_SMD:R_0402_1005Metric | gpio_tools | Engineering revision C
R704 | 51R | Resistor_SMD:R_0402_1005Metric | gpio_tools | Engineering revision C
R705 | 51R | Resistor_SMD:R_0402_1005Metric | gpio_tools | Engineering revision C
R706 | 51R | Resistor_SMD:R_0402_1005Metric | gpio_tools | Engineering revision C
R707 | 51R | Resistor_SMD:R_0402_1005Metric | gpio_tools | Engineering revision C
R708 | 51R | Resistor_SMD:R_0402_1005Metric | gpio_tools | Engineering revision C
R709 | 51R | Resistor_SMD:R_0402_1005Metric | gpio_tools | Engineering revision C
R710 | 51R | Resistor_SMD:R_0402_1005Metric | gpio_tools | Engineering revision C
R711 | 51R | Resistor_SMD:R_0402_1005Metric | gpio_tools | Engineering revision C
R712 | 51R | Resistor_SMD:R_0402_1005Metric | gpio_tools | Engineering revision C
D700 | TPD2EUSB30DRTR | Package_TO_SOT_SMD:Texas_DRT-3 | gpio_tools | Engineering revision C
D701 | TPD2EUSB30DRTR | Package_TO_SOT_SMD:Texas_DRT-3 | gpio_tools | Engineering revision C
D702 | TPD2EUSB30DRTR | Package_TO_SOT_SMD:Texas_DRT-3 | gpio_tools | Engineering revision C
D703 | TPD2EUSB30DRTR | Package_TO_SOT_SMD:Texas_DRT-3 | gpio_tools | Engineering revision C
D704 | TPD2EUSB30DRTR | Package_TO_SOT_SMD:Texas_DRT-3 | gpio_tools | Engineering revision C
D705 | TPD2EUSB30DRTR | Package_TO_SOT_SMD:Texas_DRT-3 | gpio_tools | Engineering revision C
D706 | TPD2EUSB30DRTR | Package_TO_SOT_SMD:Texas_DRT-3 | gpio_tools | Engineering revision C
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

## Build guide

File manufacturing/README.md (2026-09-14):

# K 版制造文件说明

本目录包含经过数字检查的**裸 PCB 工程样板文件**，不是已通过实物验证的整机量产包。完整装配仍需采购料号冻结、厂商 CAM 和贴装方向复核。

- `fabrication-K/`：八层铜、双面阻焊/钢网/丝印、Edge.Cuts、Gerber Job、分开的 PTH/NPTH Excellon 钻孔，以及钻孔图和报告。只选择一份 PTH 和一份 NPTH 钻孔文件；钻孔图不是额外钻孔程序。
- `FD-MAIN-01-populated-pos.csv`：395 个 POPULATE 器件的 KiCad 原生贴装坐标。`FD-MAIN-01-all-pos.csv` 保留原生全部导出记录，不能把其中 DNP/辅助项全部焊上。
- `BOM-review.csv`：420 个设计位号，395 装配、8 DNP、17 PCB_ONLY。四个额外光学定位标记不计为采购器件。
- `PROCESS-K.md`：叠层、填孔、阻抗、加工和装配要求；`BUDGET-K.md` 为未报价项明确列出的预算。
- `preview/`：实际制造 Gerber 的正反面和八层铜预览，并非概念效果图。

## 实际导出核对

`checks/manufacturing-export-K.json` 使用 Gerbonara 1.6.3 独立解析导出结果，核对了 11,385 段走线、全部 899 个过孔在八层上的环形焊盘、外层贴片焊盘中心、钻孔/槽以及 395 个装配坐标。

PTH 为 907 项：722 个 0.20 mm 过孔、177 个 0.15 mm 过孔、8 个金属化槽。NPTH 为 10 项，其中四个安装孔为 2.40 mm，与机械模型一致。所有贯穿过孔要求树脂填孔、盖帽及整平；不能按普通阻焊盖油替代。

板边中心线外形为 **40 × 94 mm、R2 圆角**。Gerber Job 显示的 40.05 × 94.05 mm 包围盒包含 0.05 mm 外形绘图笔宽，不能按该包围盒扩大实物外形。

Gerber 坐标分辨率 0.000001 mm；Excellon 钻孔输出为 0.001 mm。核对按其导出舍入精度分别使用 0.000002 mm 和单轴 0.00051 mm 比较阈值，不是放宽制造间距规则。解析器识别出 KiCad 的头后 G90 写法，并在圆角矩形绘图宏渲染时提示多余未使用参数；文件正常解析并完成上述核对。这些语法提示与 PCB DRC 违规不是同一回事。

## 厂家交接

使用文件中的绝对板坐标；坐标表 X 为板 X，Y 为板 Y 的负值，单位 mm。`Side` 为 top/bottom，`Rot` 保留 KiCad 原生角度。双面贴装旋转和零件中心约定由贴片厂核对，不能直接套用另一厂商的底面旋转规则。零件体积包络不代替焊盘 1、极性和贴装方向复核。

先确认同时支持八层指定叠层、0.15 mm 机械钻孔、填孔盖帽、最小环宽及阻抗条件，再由厂商检查 CAM 并报价。原始工程和数字检查结果都随包提供；任何叠层、孔径、封装、布线或采购替代改变后，需要重新检查并更新文件哈希。

当前 DRC 包含 error 和 warning，结果为零；报告保留 missing_courtyard、track_not_centered_on_via、tuning_profile_track_geometries、footprint_filters_mismatch、footprint_type_mismatch 五项默认忽略检查。不要把本报告当作独立贴装可达性、全部封装采购正确性、阻抗测量、射频/电源性能或供应商接单证明。

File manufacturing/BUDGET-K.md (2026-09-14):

# K 版打样预算

八层主板，395 个装配器件/板，双面贴装，填孔盖帽、沉金。币种人民币。**工程估算，不是厂家报价，也未下单。下表尚未包含 0.15 mm 非常规机械钻孔附加费，不能视为最终总价上限。**

| 数量与范围 | 预算 |
|---|---:|
| 每板电子元件 | ¥342–740 |
| 两块装配主板合计 | ¥1729–4221 |
| 两套核心样机，含线圈线束、打印外壳及装配 | ¥2049–4941 |
| 只做一套核心样机的估算 | ¥1534–3820 |

少量打样的开机、钢网、上料和检验费用不能按数量简单均摊。一套价格不是两套合计的一半。八层相对之前六层，暂增加每批 ¥100–400 工艺预算；以最终 BOM、库存和制板方工程报价为准。

未包含 iPhone、外部 CSI/雷达/UWB/SDR/热成像探头、充电器、调试器、RF 测量与调谐、返版和税费调整。没有内置电池。本项目适合作品集和研发；现阶段不作为比成品 Flipper 更便宜的采购方案。

逐项计算见 ../cost/estimate-eight-layer-K.json。通用无源件仍须确认采购规格，射频件不能按同数值任意替换。

本轮布线增加了 0.30/0.15 mm 贯穿过孔，以解决局部密集引出；厂家公开能力表将 0.15 mm 钻孔列为高费用非常规工艺，公开资料没有给出本项目可用的确切附加价。该费用以最终 Gerber、钻孔表和填孔要求询价后补入，现阶段不编造厂家报价。

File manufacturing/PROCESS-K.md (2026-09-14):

# K 版八层主板工艺要求

以同一提交内 release-status.json 和 checks/ 为放行依据。本文是加工规格，不是通过检查的证明。

单板 94 × 40 mm，名义厚度 1.6 mm，双面贴装，八层；层序 F.Cu / In1.Cu（地）/ In2.Cu（信号）/ In3.Cu（信号）/ In4.Cu（信号）/ In5.Cu（信号）/ In6.Cu（地）/ B.Cu。

采用嘉立创 JLC08161H-3313。铜厚由上至下 0.035 / 0.0152 / 0.0152 / 0.0152 / 0.0152 / 0.0152 / 0.0152 / 0.035 mm；层间介质依次 0.0994 / 0.1000 / 0.3568 / 0.3000 / 0.3568 / 0.1000 / 0.0994 mm。铜和介质总厚 1.5736 mm；厂家显示成品约 1.57 mm、厚度公差 ±10%。不可擅自换叠层。

沉金、绿油、白字。所有贯穿过孔树脂填孔、电镀盖帽并整平；包含盘中孔，不能替换成开孔或仅阻焊盖油。本版没有盲孔、埋孔或激光微孔。0.15 mm 机械钻孔属于厂家标注的非常规加价工艺；询价必须明确同时满足八层、盘中孔填孔盖帽及最小钻径，不可直接套用普通板价格。内层钻孔到异网铜距离须由厂家 CAM 对最终文件确认。

最小线宽/间距 0.10/0.10 mm；贯穿过孔最小外径/钻径 0.30/0.15 mm（名义环宽 0.075 mm），普通位置保留 0.35/0.20 mm；孔边间距至少 0.25 mm。铜到板边至少 0.20 mm。制板时保留文件中的独立射频和天线禁布区。

USB 主干位于第三层 In2.Cu，参考第二层和第七层地。目标差分阻抗 90 Ω，订单控制公差目标 ±10%；主干线宽 0.142 mm、边缘间距 0.260 mm。此尺寸来自厂家对应八层叠层计算器；焊盘引出、过孔和连接器过渡仍须连同实板验证。需随板阻抗测试报告，不能用计算器数值代替实测。

射频匹配和谐振网络保留设计值与调试位置；线圈、机壳和手机会影响匹配。打样后测量才可确定量产值。射频走线不能随意换层、拉长或并入普通等宽信号线。

普通外形尺寸公差按 ±0.2 mm 预算。厂家可增设工艺边、定位孔与拼板 fiducial，须保持单板外形、安装孔和接口位置。拼板后的重心、贴装旋转与钢网应重新核对，不可直接套用其他厂家的底面角度习惯。

双面回流；LGA、QFN 与盘中孔焊接区域需要 X 光检查。连接器固定脚、线圈、外接天线、马达和线束按装配图处理。物料替代，尤其 RF L/C、晶振、保护器件及功率器件，需要先核对电气与封装。

依据：[嘉立创 PCB 工艺能力](https://www.jlc.com/portal/vtechnology.html)、[官方叠层选择](https://tools.jlc.com/jlcTools/index.html#/impedanceDefaultTemplate)、[官方阻抗计算器](https://tools.jlc.com/jlcTools/index.html#/impedanceCalculateNew)，2026-09-09 查阅。没有提交采购订单。

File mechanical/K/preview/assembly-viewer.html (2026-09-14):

# FieldDock · 紧凑装配 K

实际板框 + 元件包络 · 单位 mm · iPhone 17 Pro Max

工程审查稿 / 未发布制造

立体俯视侧视复位

拖拽旋转 · 滚轮缩放 · 右侧可隐藏外壳、展开装配

装配层次展开程度 55% 显示上下壳与窗口 显示参考几何 显示预留板和装配包络 显示探头预留（本模型无） 显示简化避让提示区域

板框、孔位和元件 XY 已与当前 PCB 对齐。元件高度为保守包络；线圈为绕线空间。外壳公差、光学窗口、按键保持与手机固定仍须验证。

## 可见零件

## 审查范围

可检查装配层次、体积和接口方向。尺寸请以 STEP 和二维图为准。预览不构成天线、载荷、散热、线缆弯折或 Apple 兼容性验证。

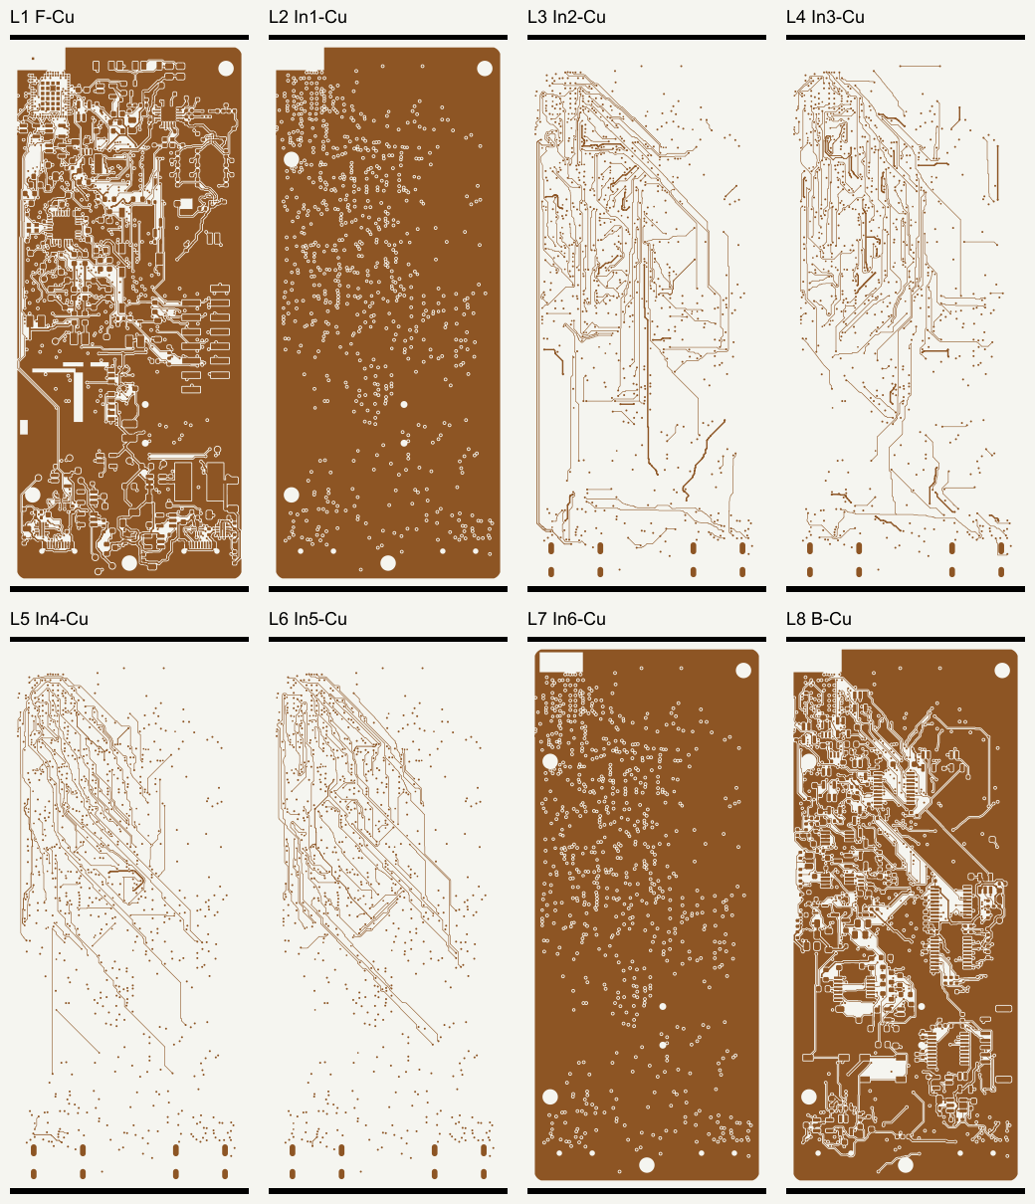
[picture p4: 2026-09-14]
manufacturing/preview/eight-copper-layers.png

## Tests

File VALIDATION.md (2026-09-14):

# 验证与打样顺序

先运行 `python tools/verify_artifacts.py`。它核对发布文件的哈希、检查报告中的数量、最终 PCB 对应关系及库文件来源，不启动 KiCad。K 版已有随包保存的原生检查结果；这个脚本负责检查证据一致性。

`python tools/verify_artifacts.py --release` 还要求 PCB 无未连接项、无 DRC 违规、原理图 ERC 通过，以及经过几何核对的制造文件存在。此处 release 仅指裸 PCB 工程样板的数字制造文件；未满足条件时必须失败。请同时阅读 `release-status.json`，不要把下载到工程文件等同于生产放行。

原生工程位于 `cad/FD-MAIN-01.kicad_pro`。建议使用对应报告记录的 KiCad 版本。重新填写地铜后做 DRC，再核对网络表、钻孔、阻焊、钢网、BOM 和贴装方向。当前电脑曾发生 KiCad CLI 访问冲突，保存的报告由单次隔离诊断产生；仓库验证脚本不会自动启动该程序。

基础驱动可按 `firmware/README.md` 编译并运行主机测试。已有 Cortex-M4 目标文件编译证据，不含完整可烧录镜像。完成 SDK、启动文件、链接脚本和外设初始化之后才可做上板调试。

实物顺序：

1. 装配前核对电源端口、保护器件方向、LGA/QFN 焊接和电源对地电阻。
2. 用限流台式电源从 AUX 口上电，确认保护阈值、各电压轨和默认关闭状态；逐个使能负载，记录电流与温升。
3. 验证两口同时接入、插拔和掉电时的电源切换及反向电流，再接 iPhone。手机和 AUX 的可用预算不能相加。
4. 完成调试器与基础固件通信后，分别验证 USB/BLE、microSD、GPIO 隔离、红外和 iButton。
5. 单独调谐 Sub-GHz、NFC 和 LF 天线/线圈，最后装壳并贴近手机复测。匹配网络的初始值不是已测得的最终值。
6. 手机端数据通道、App、RF 功能、EMC/ESD、外壳公差与固定方式须各自留实测记录。未验证项不能在作品说明中写为已实现或已认证。

整机用例须在本人设备或获得授权的测试环境中验证。仓库不包含网络干扰电路。

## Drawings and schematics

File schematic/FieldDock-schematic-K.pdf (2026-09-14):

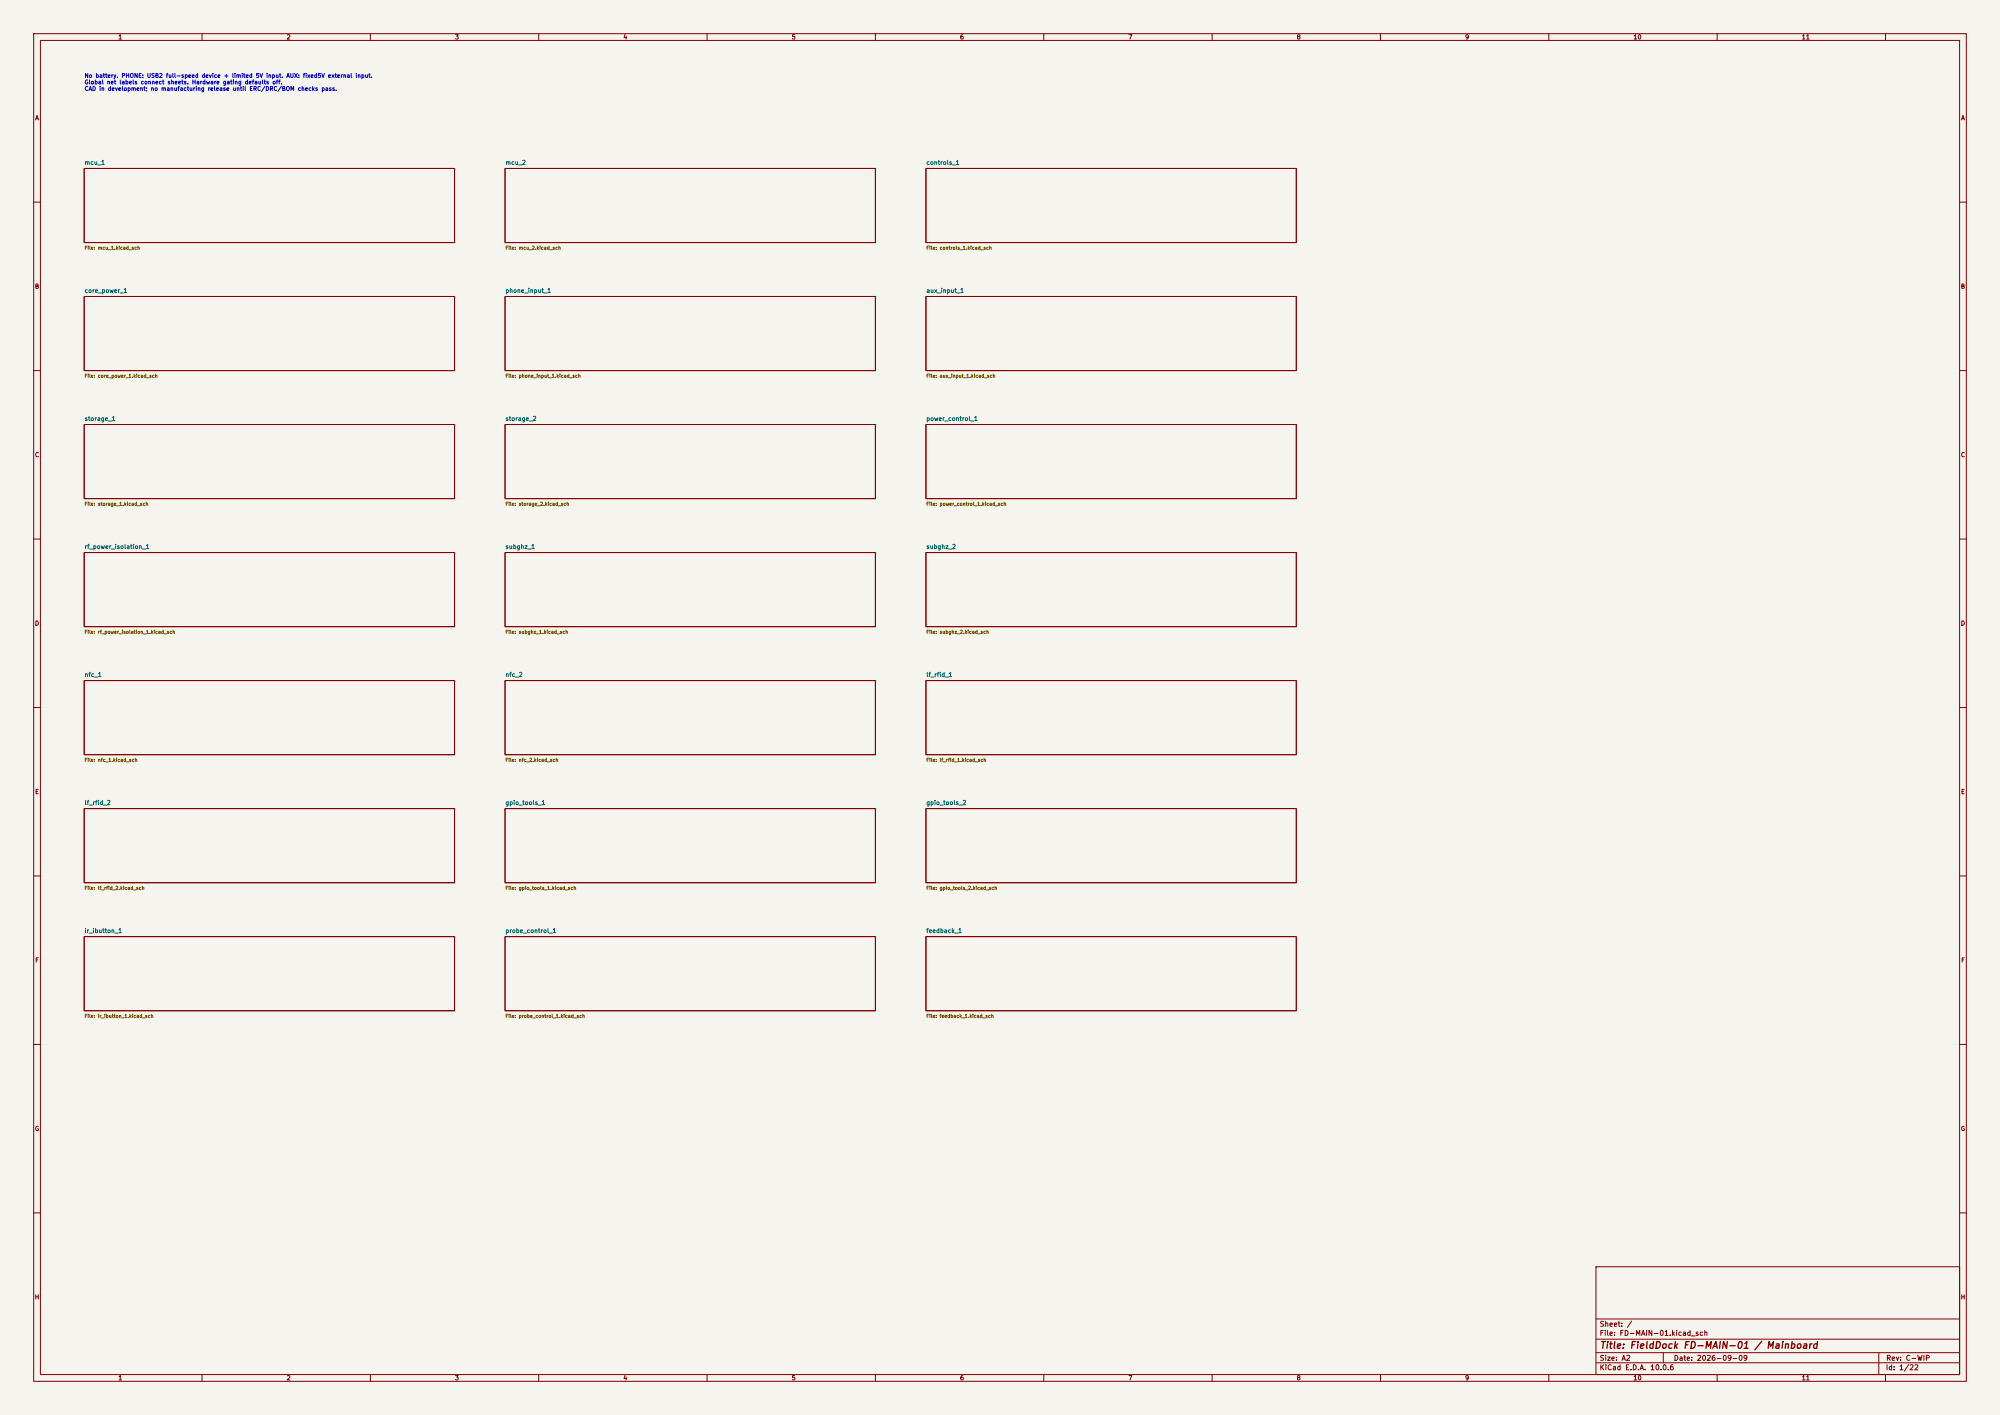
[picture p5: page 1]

No battery. PHONE: USB2 full-speed device + limited 5V input. AUX: fixed5V external input. Global net labels connect sheets. Hardware gating defaults off. CAD in development; no manufacturing release until ERC/DRC/BOM checks pass.

Sheet: /
File: FD-MAIN-01.kicad_sch
Title: FieldDock FD-MAIN-01 / Mainboard

Size: A2 | Rev: C-WIP
KiCad E.D.A. 10.0.6 | Id: 1/22

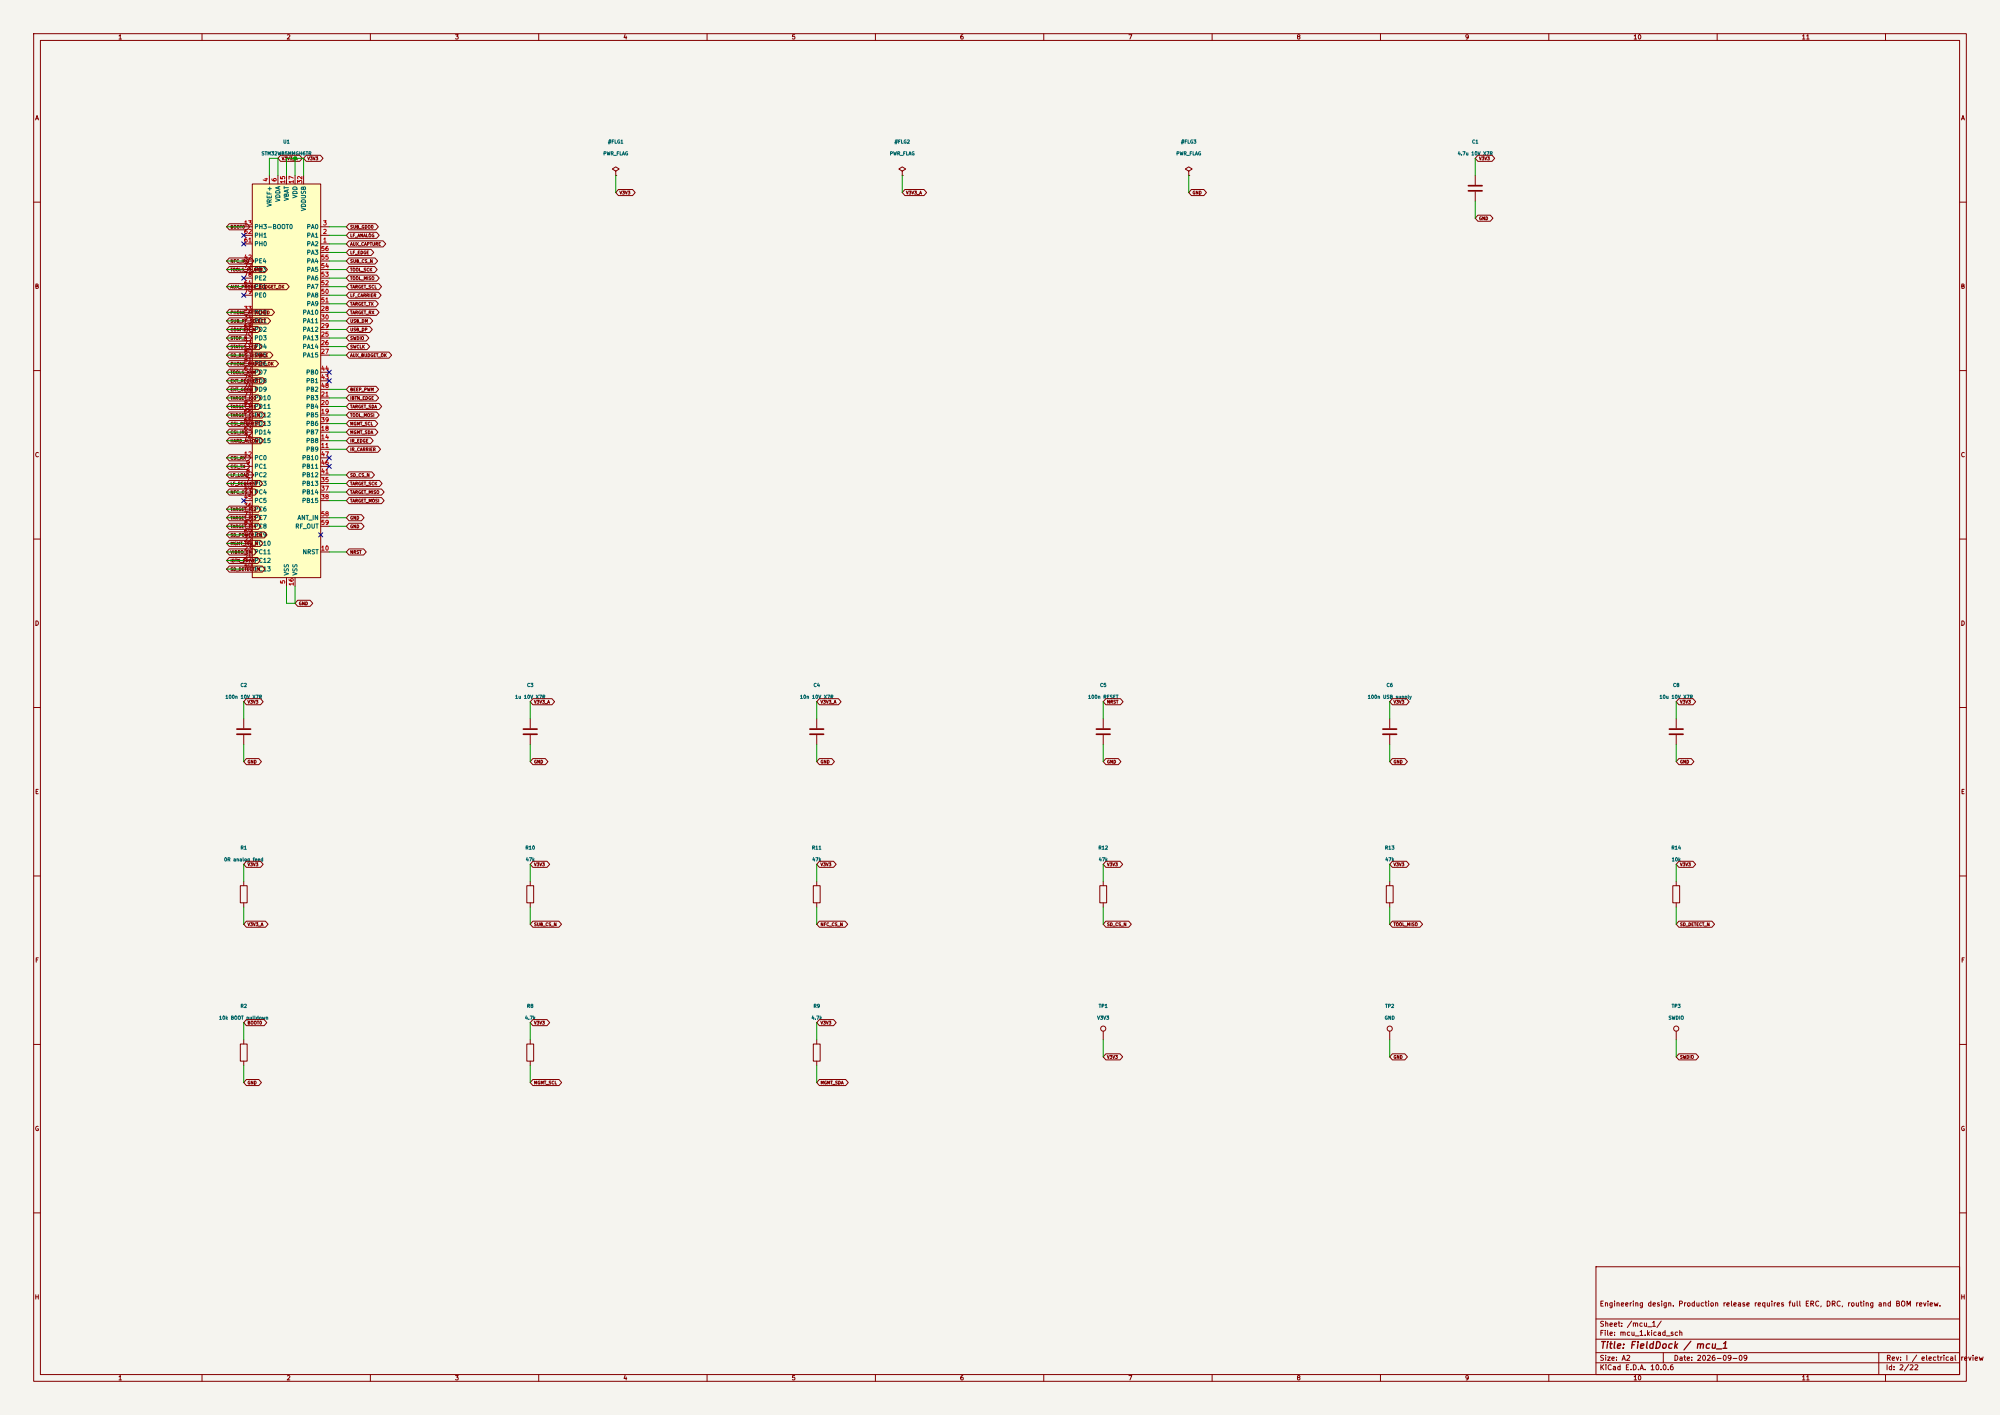
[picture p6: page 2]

5 VDDA 6 PC3 7 PC2 8 PC1 9 NRST 10 PB9 11 PC0 12 PH3-BOOT0 13 PB8 14 VBAT 15 VSS 16 VDD 17 PB7 18 PB5 19 PB4 20 PB3 21 PC10 22 PC11 23 PC12 24 PA13 25 PA14 26 PA15 27 PA10 28 PA12 29 PA11 30 VDDUSB 32 PD0 33 PD1 34 PB13 35 PC6 36 PB14 37 PB15 38 PB6 39 PC13 40 PB12 41 PE4 42 PB1 43 PB0 44 PC5 45 PB11 46 PB10 47 PB2 48 PC4 49 PA8 50 PA9 51 PA7 52 PA6 53 PA5 54 PA4 55 PA3 56

Engineering design. Production release requires full ERC, DRC, routing and BOM review.

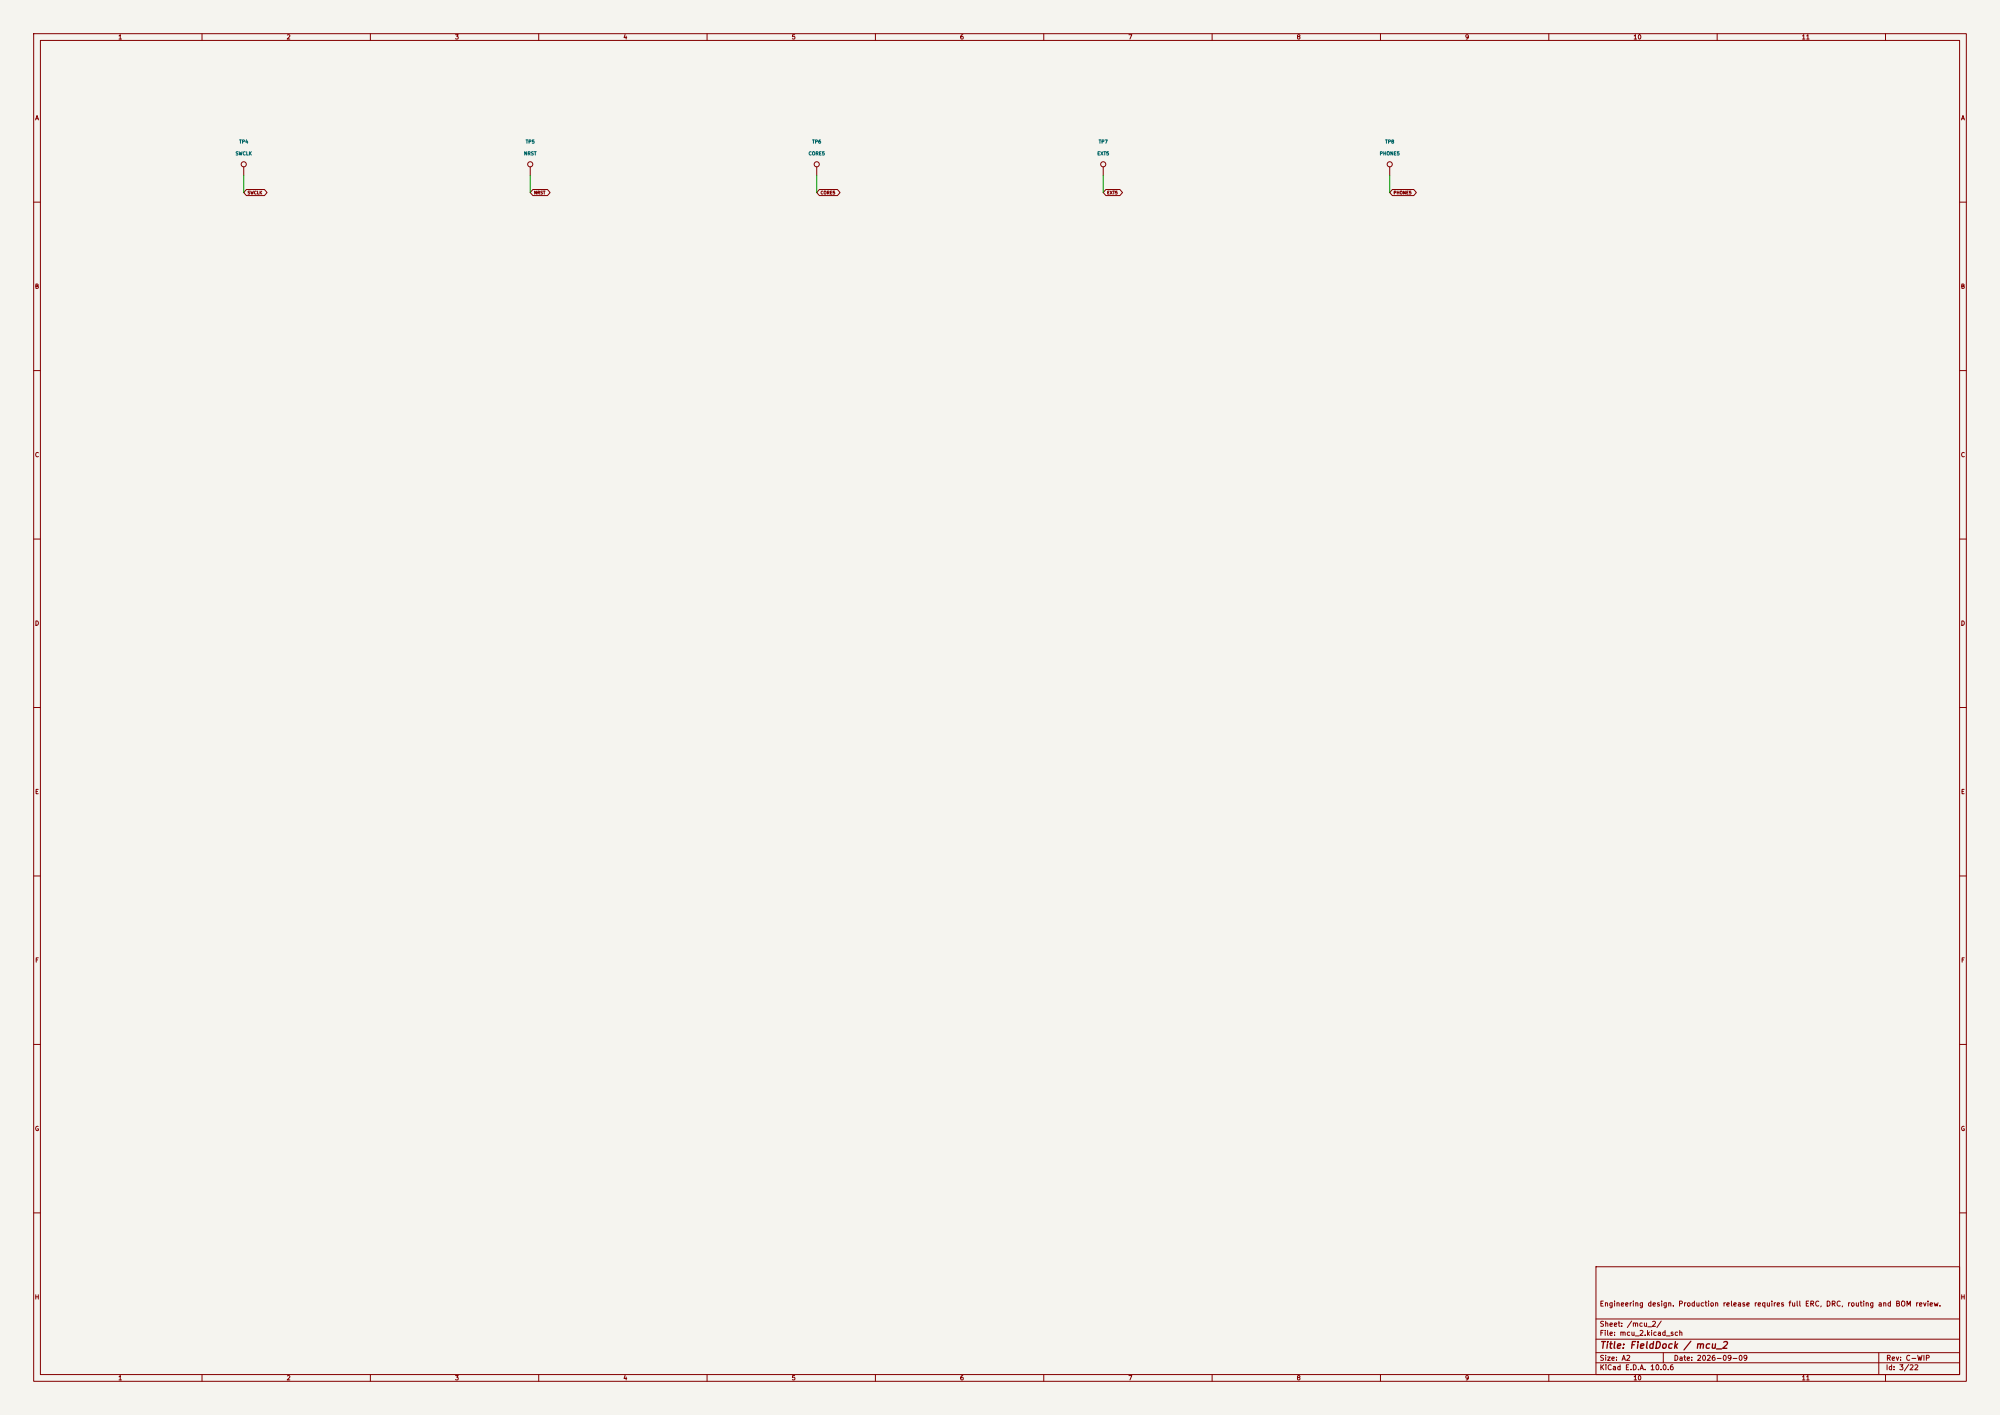
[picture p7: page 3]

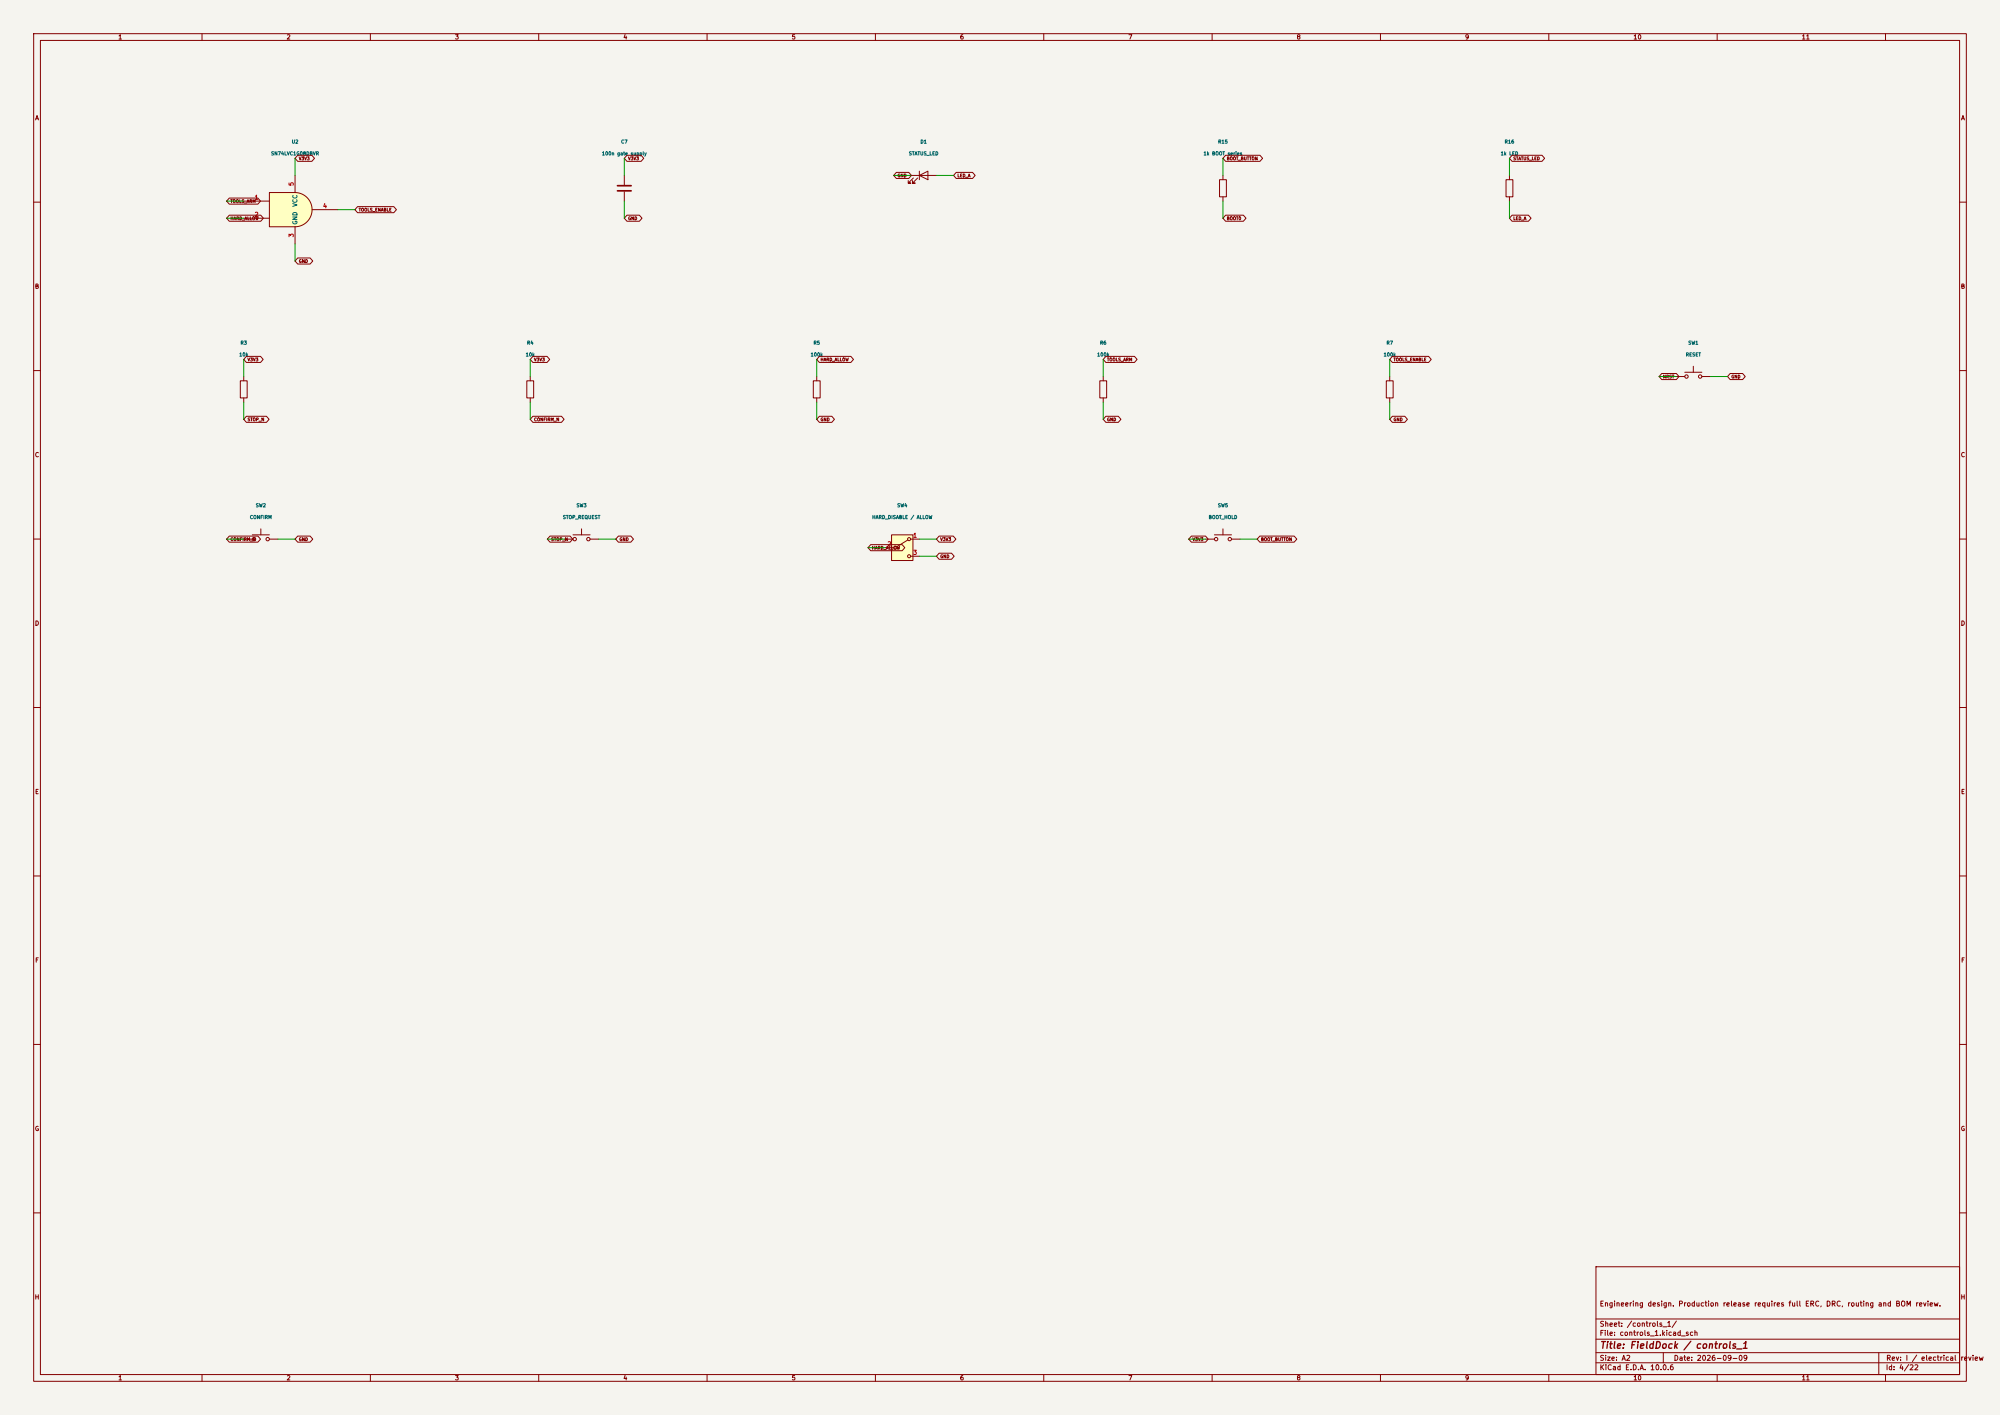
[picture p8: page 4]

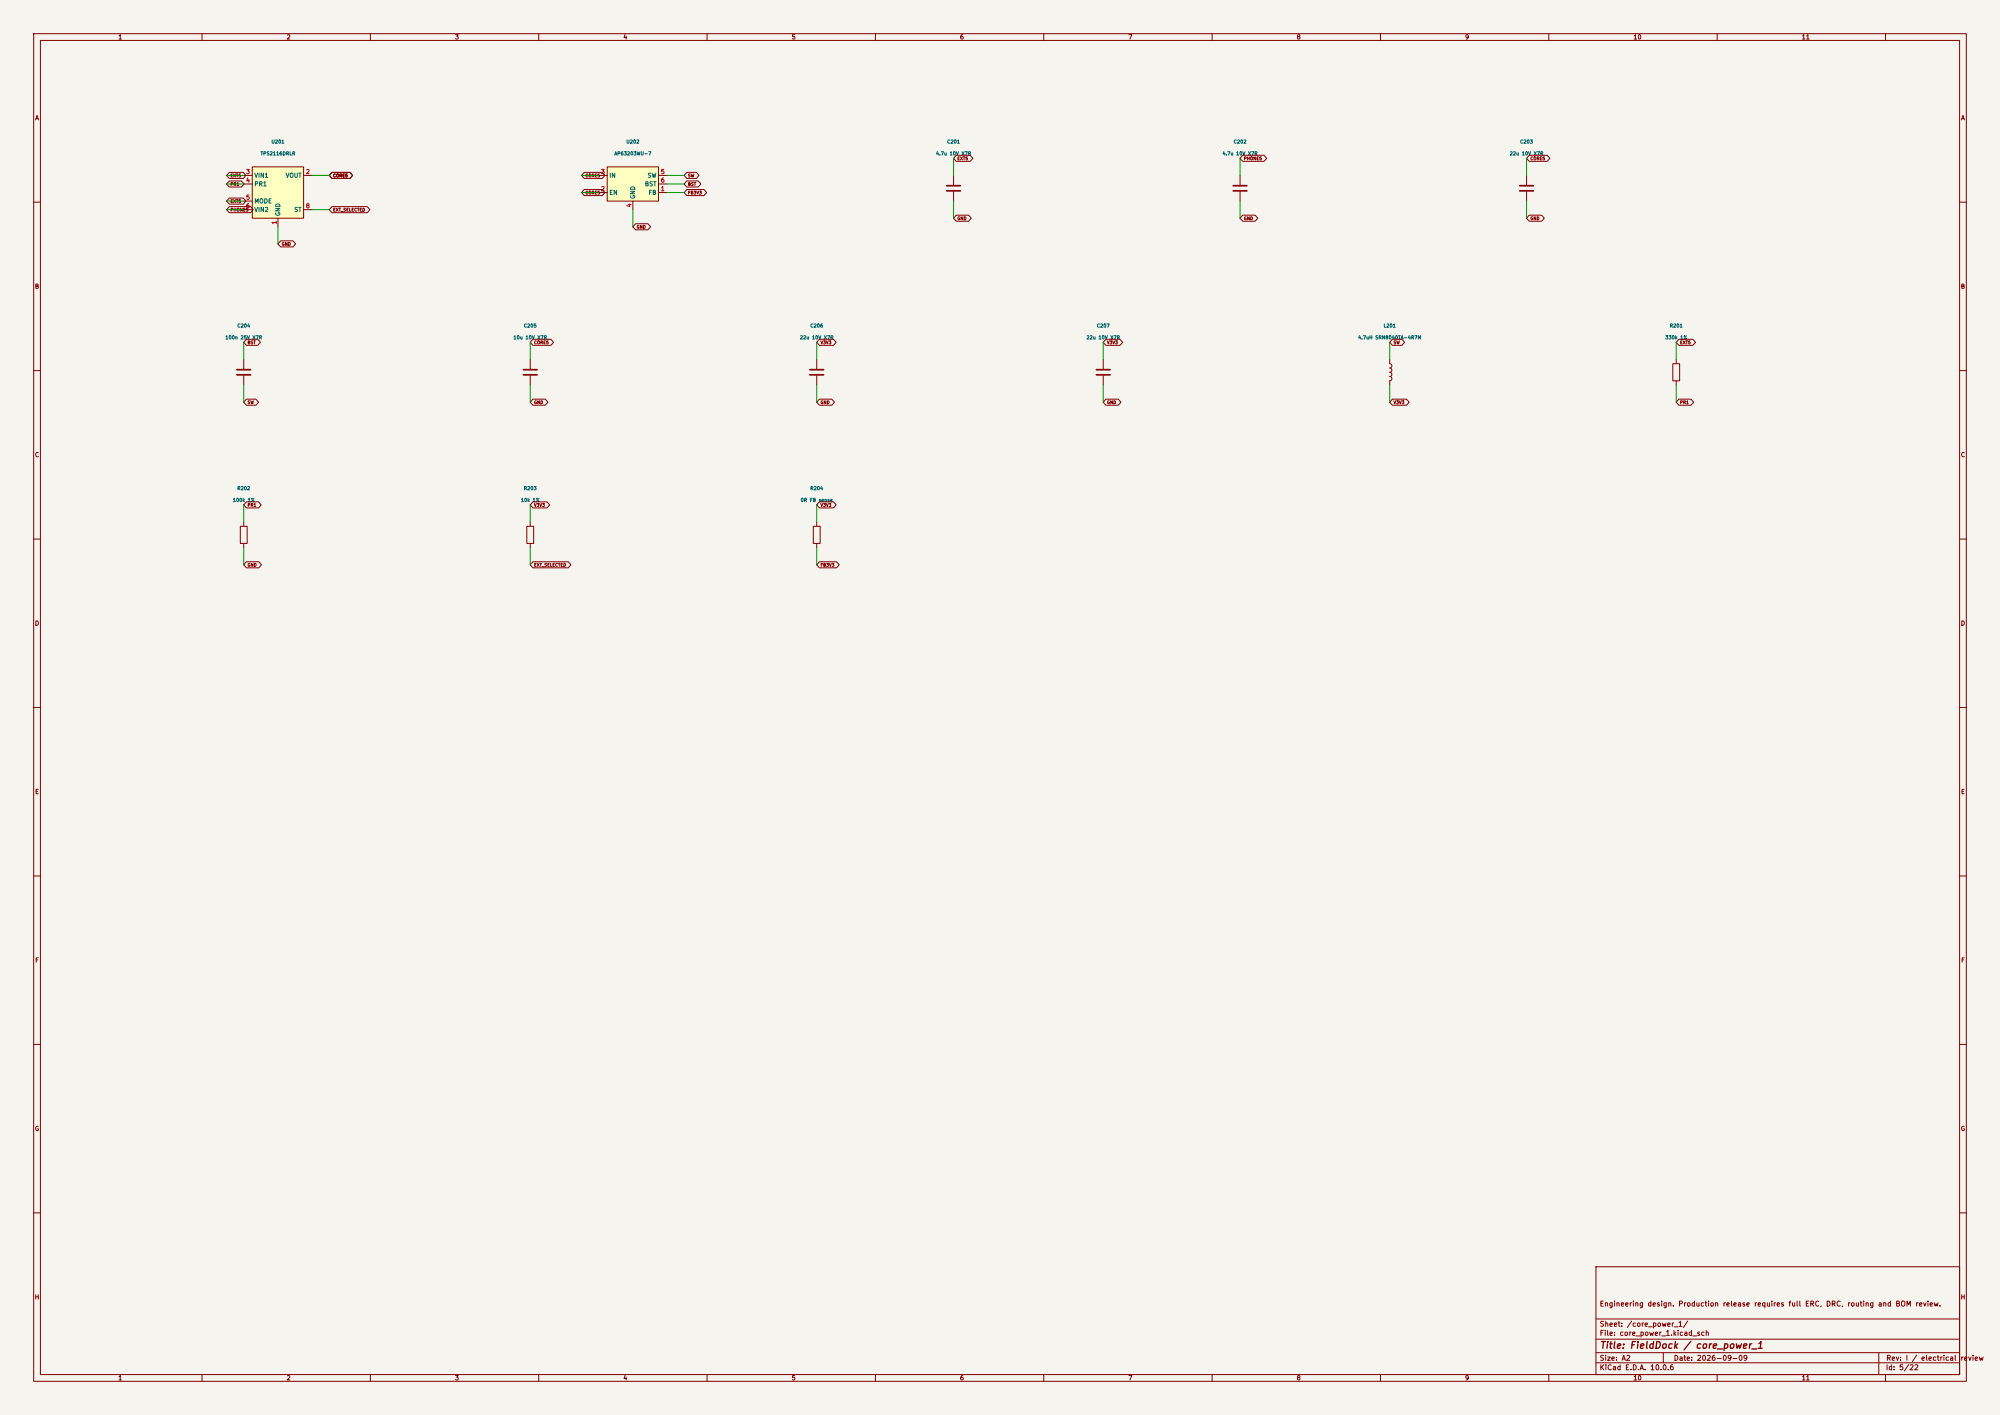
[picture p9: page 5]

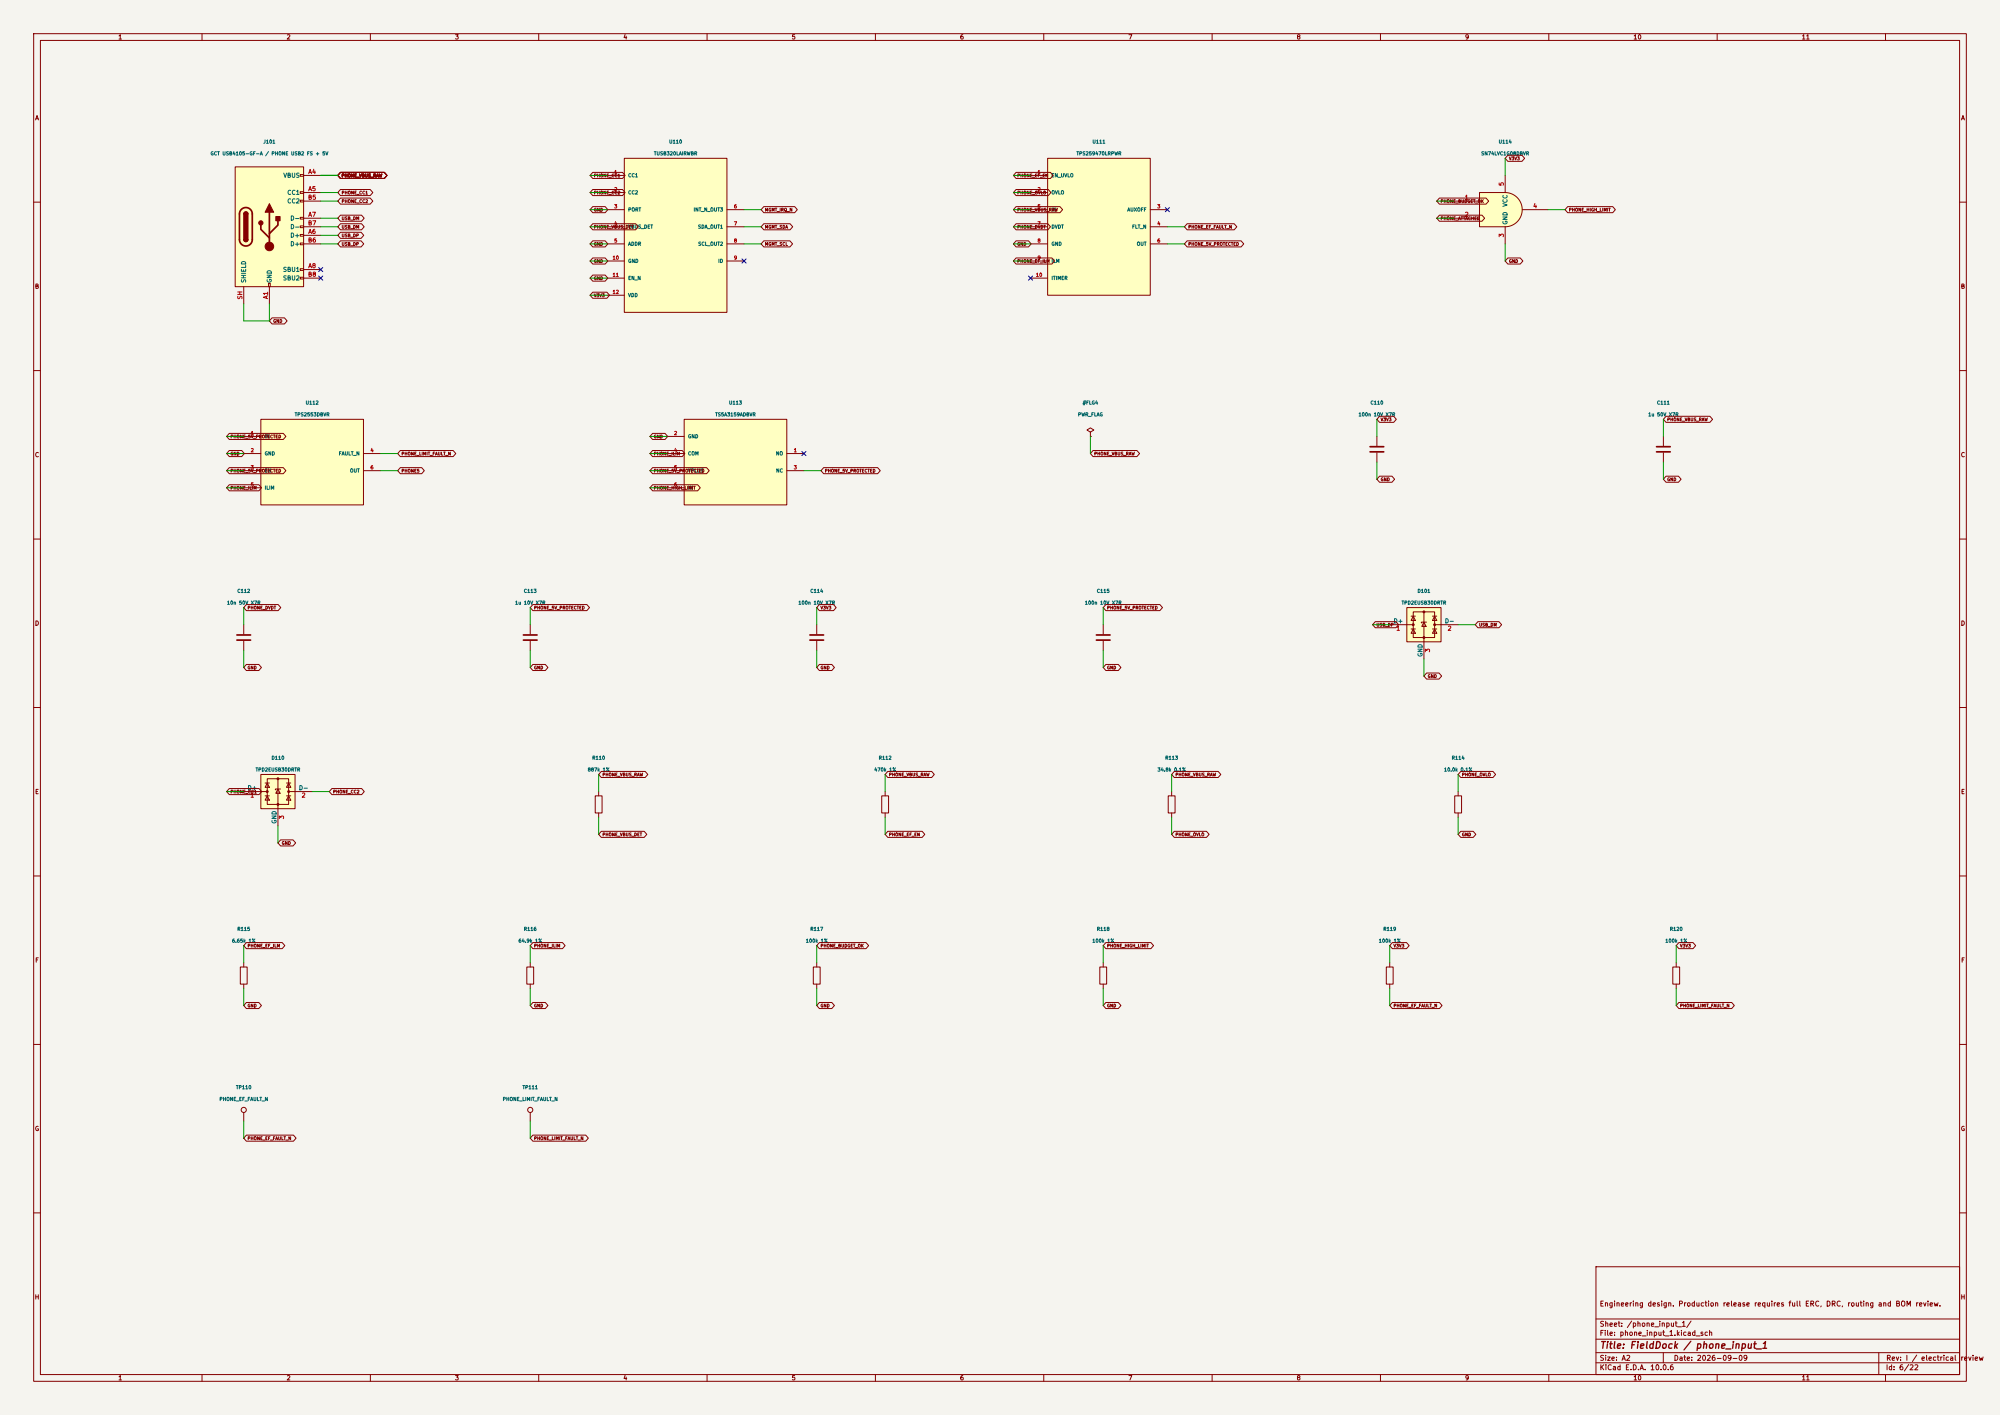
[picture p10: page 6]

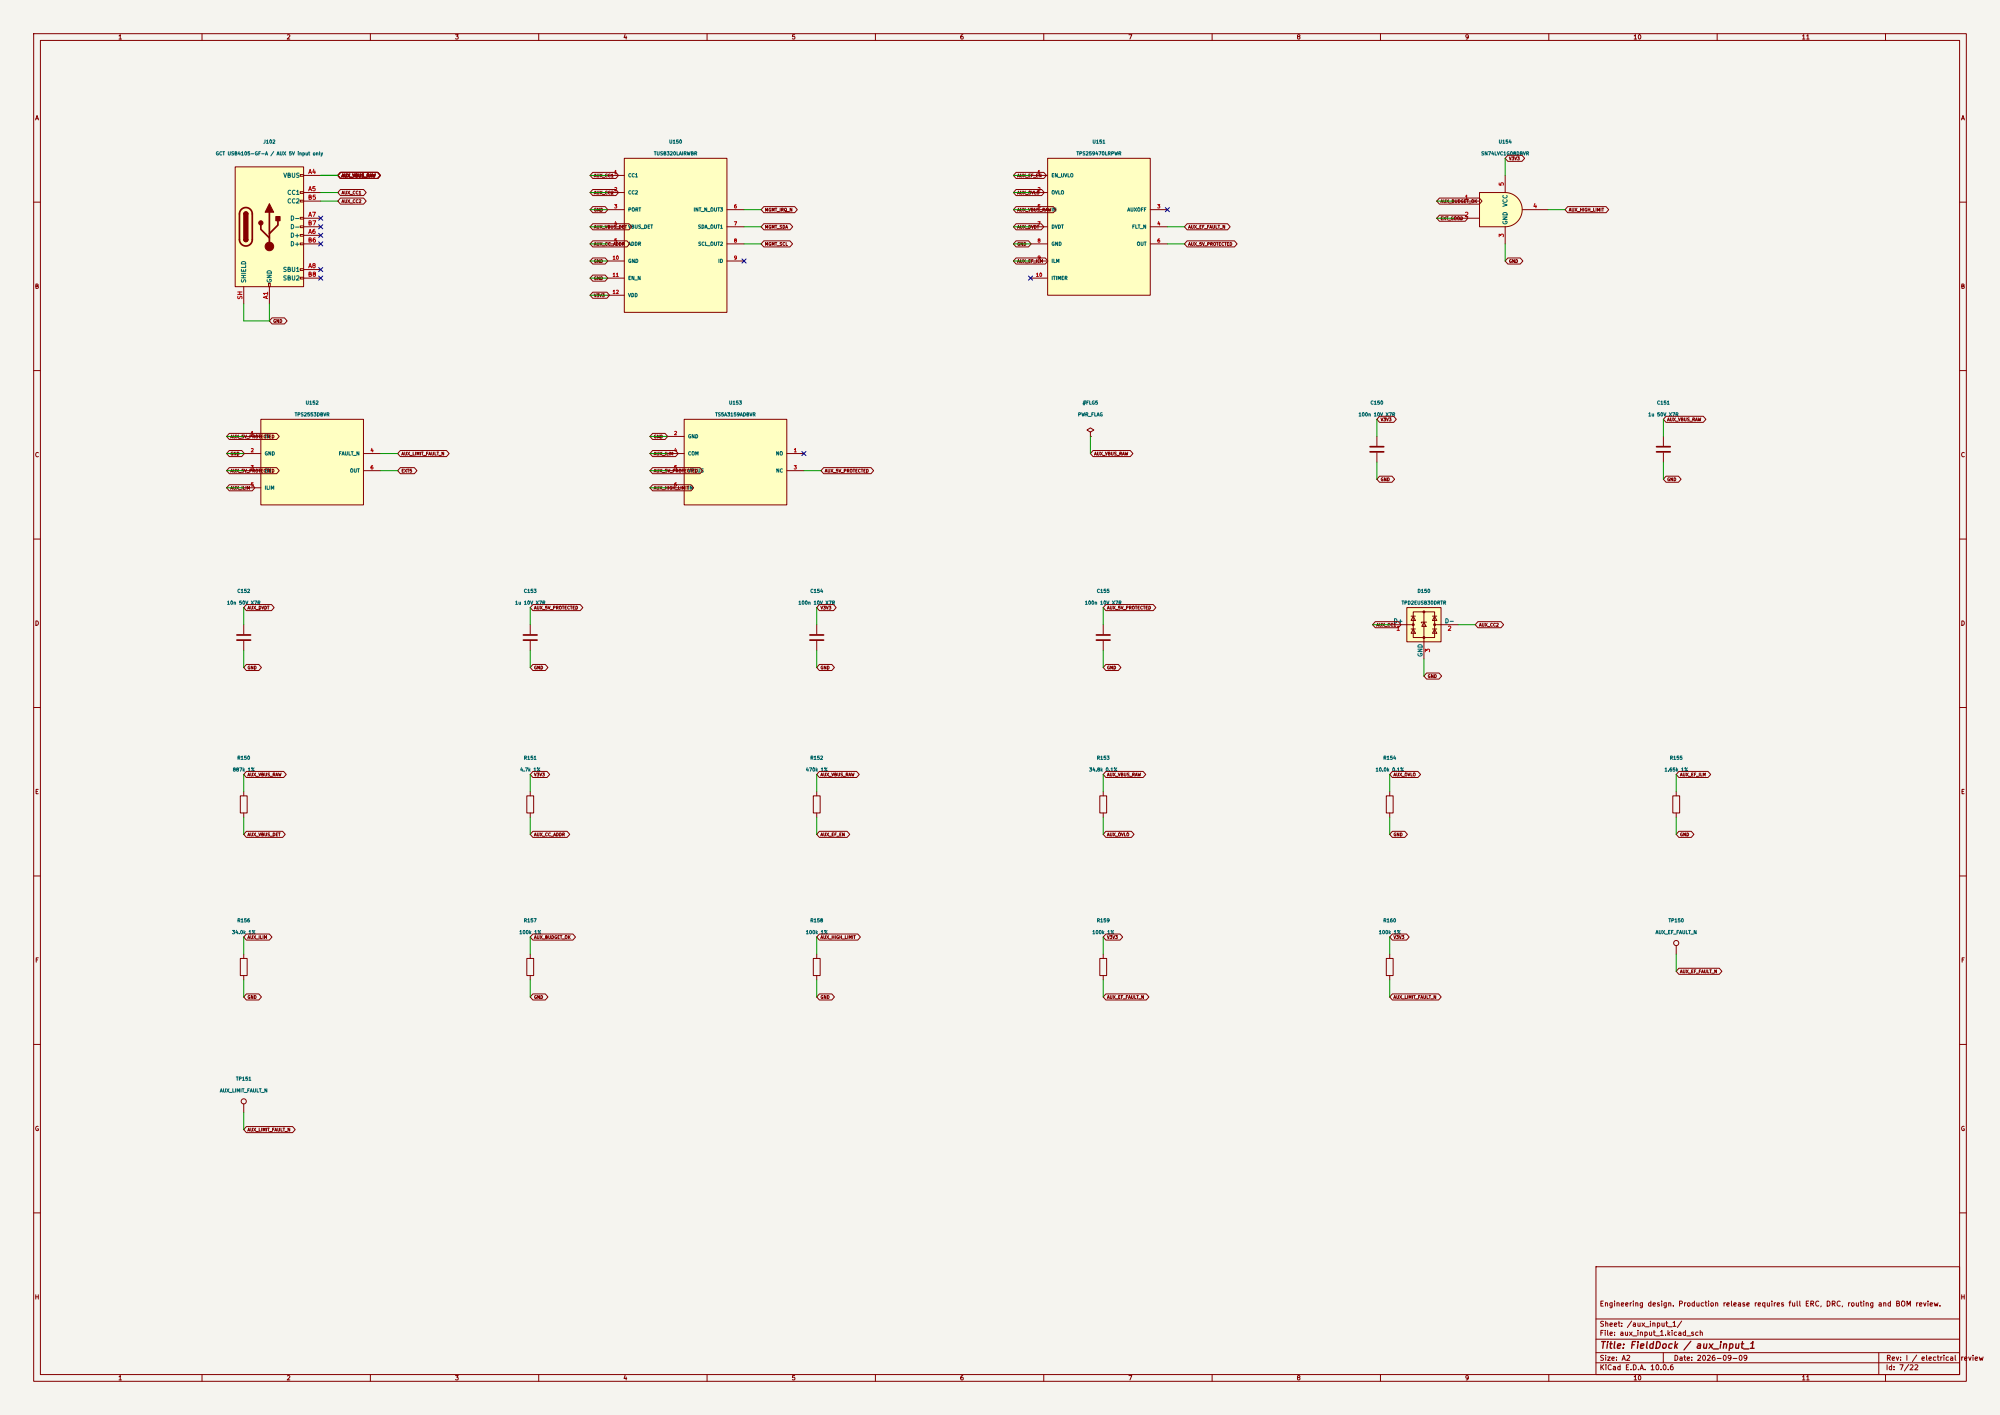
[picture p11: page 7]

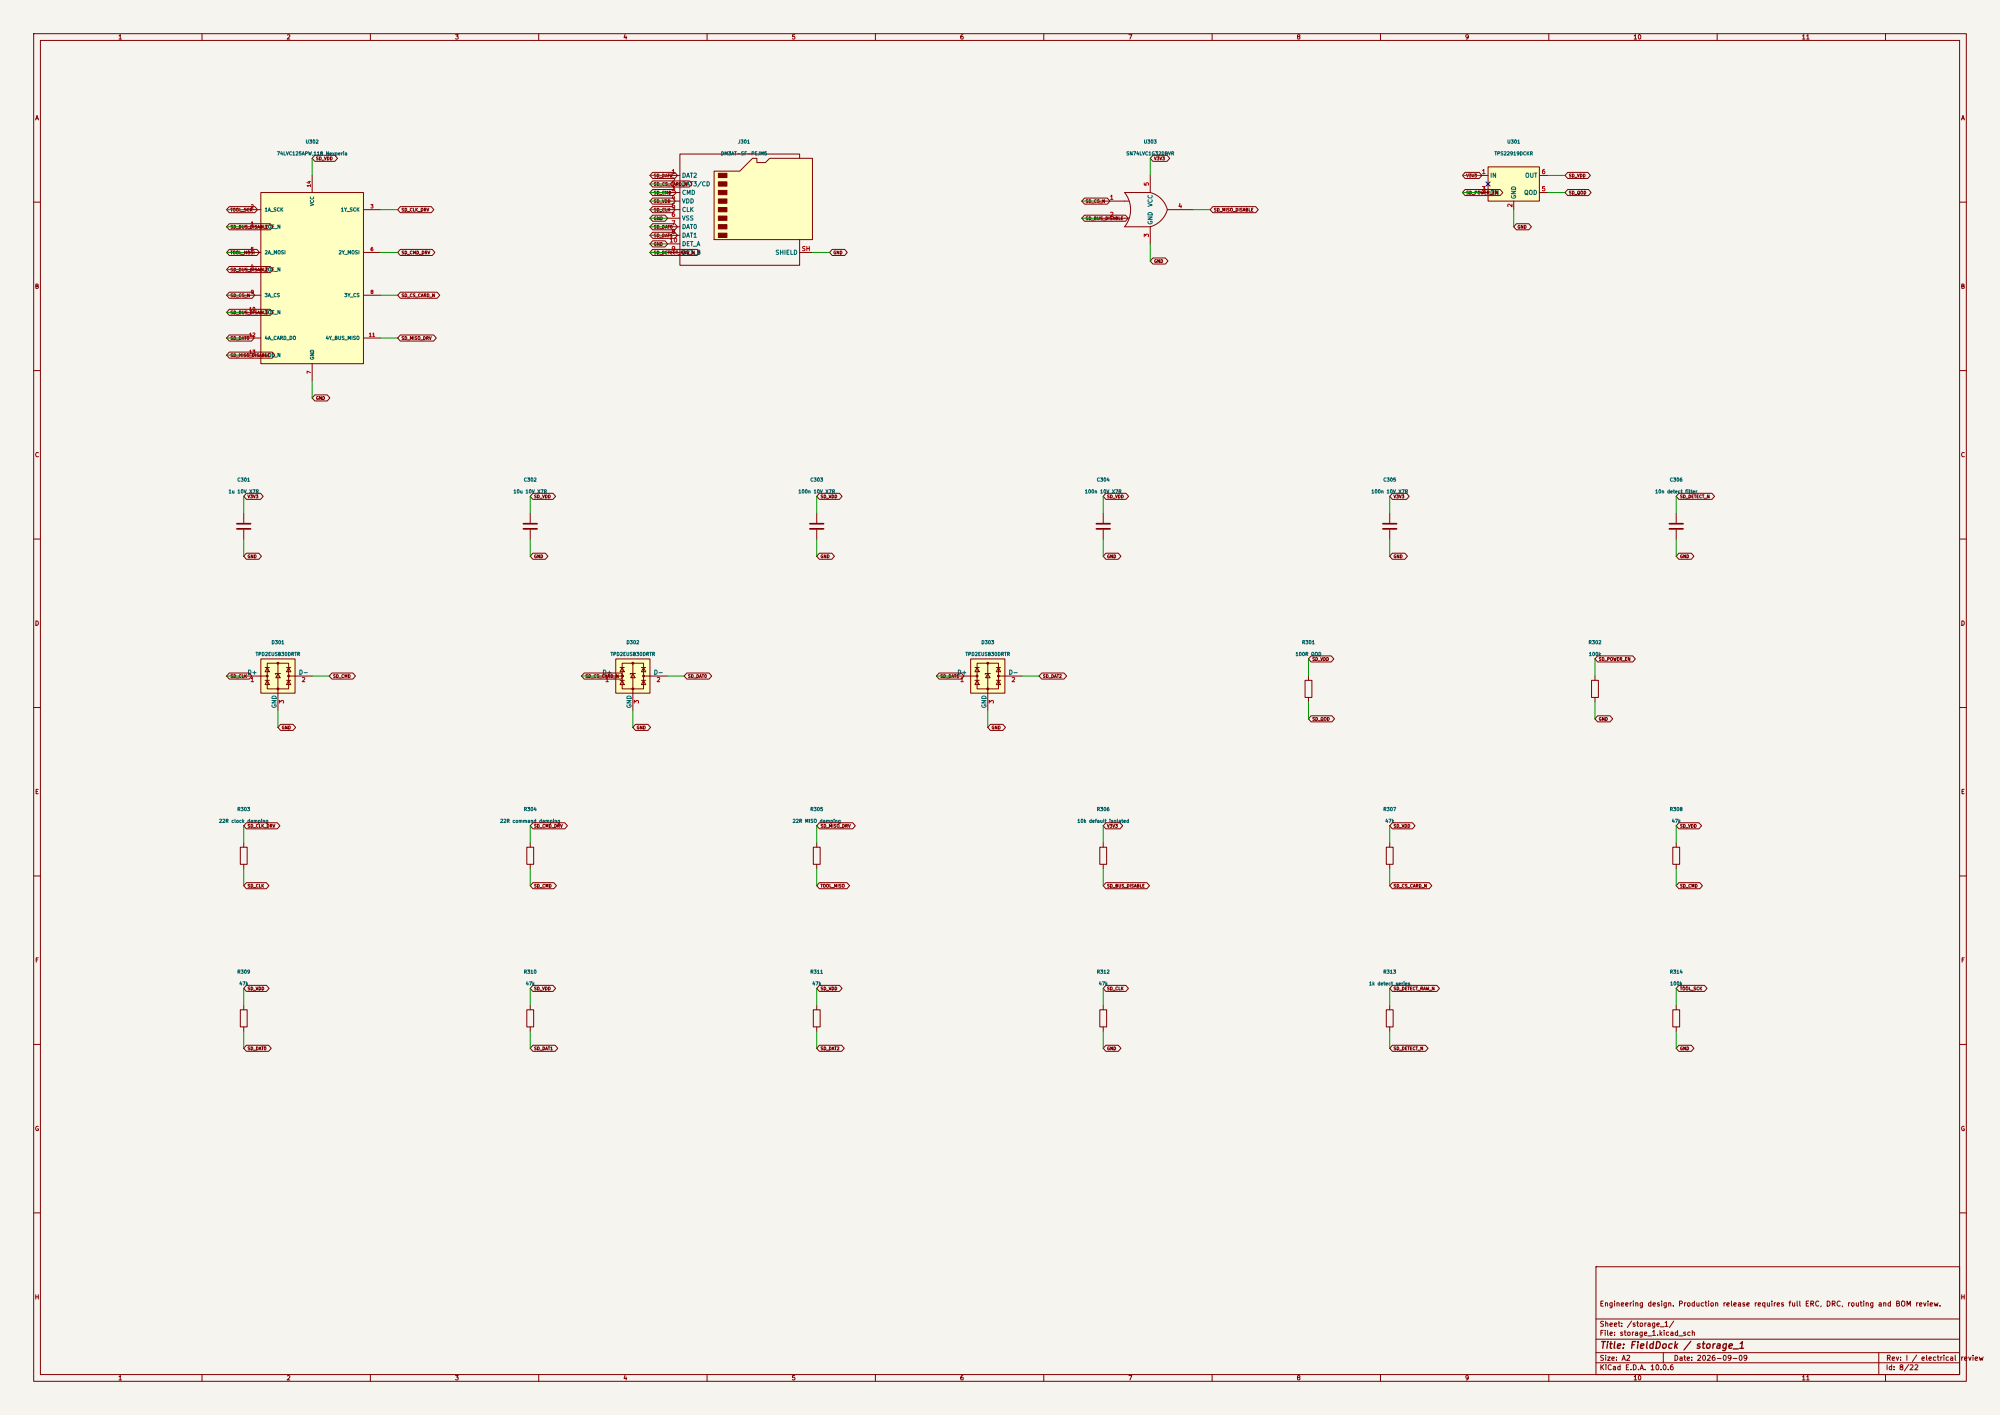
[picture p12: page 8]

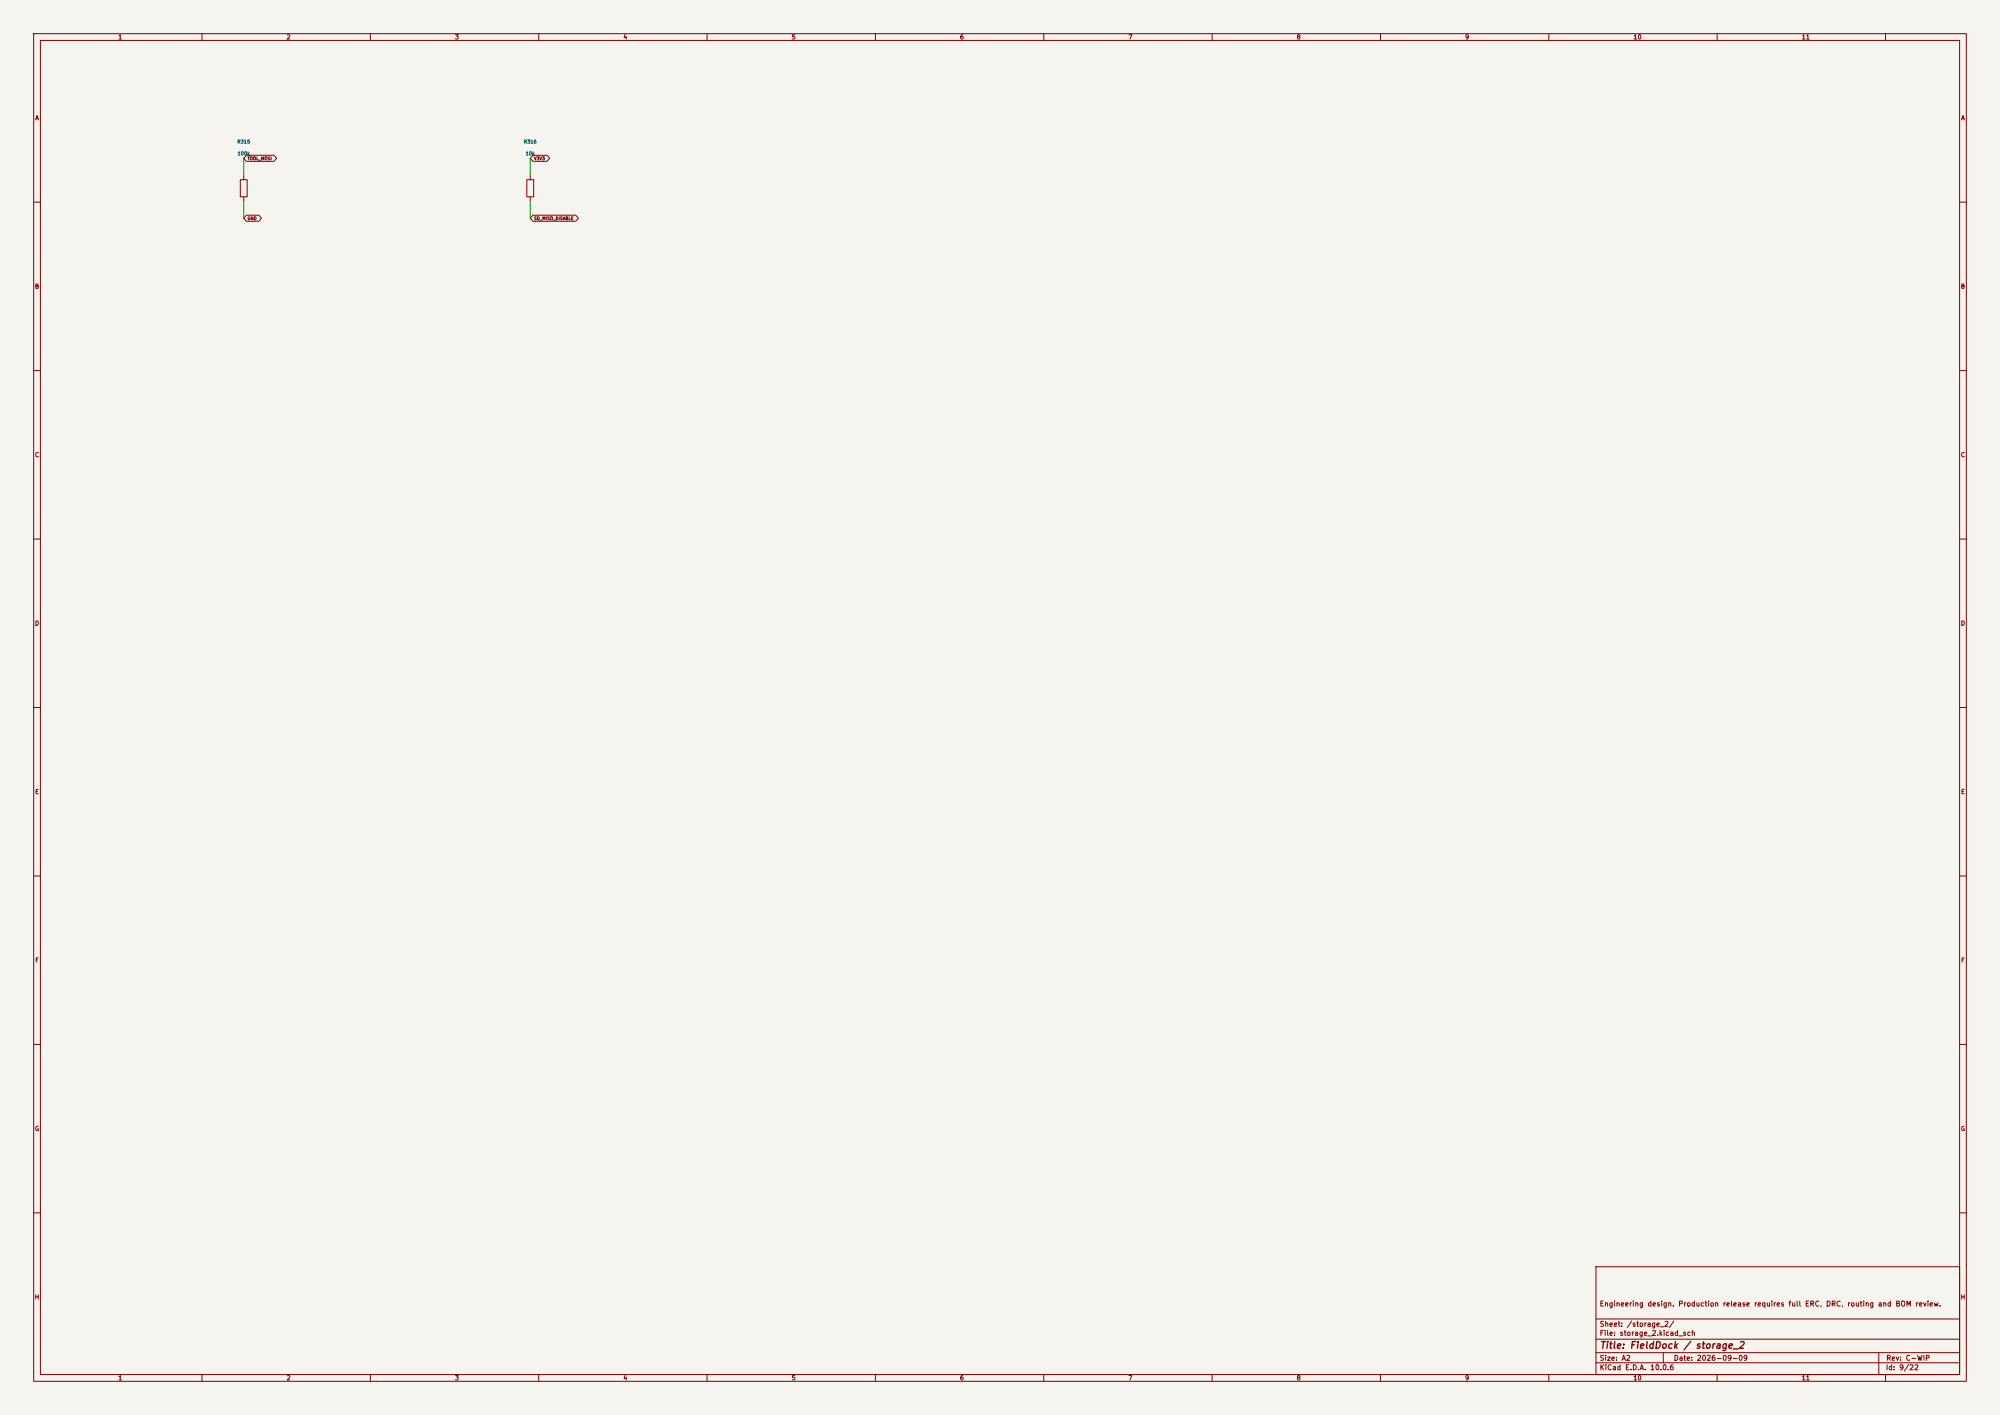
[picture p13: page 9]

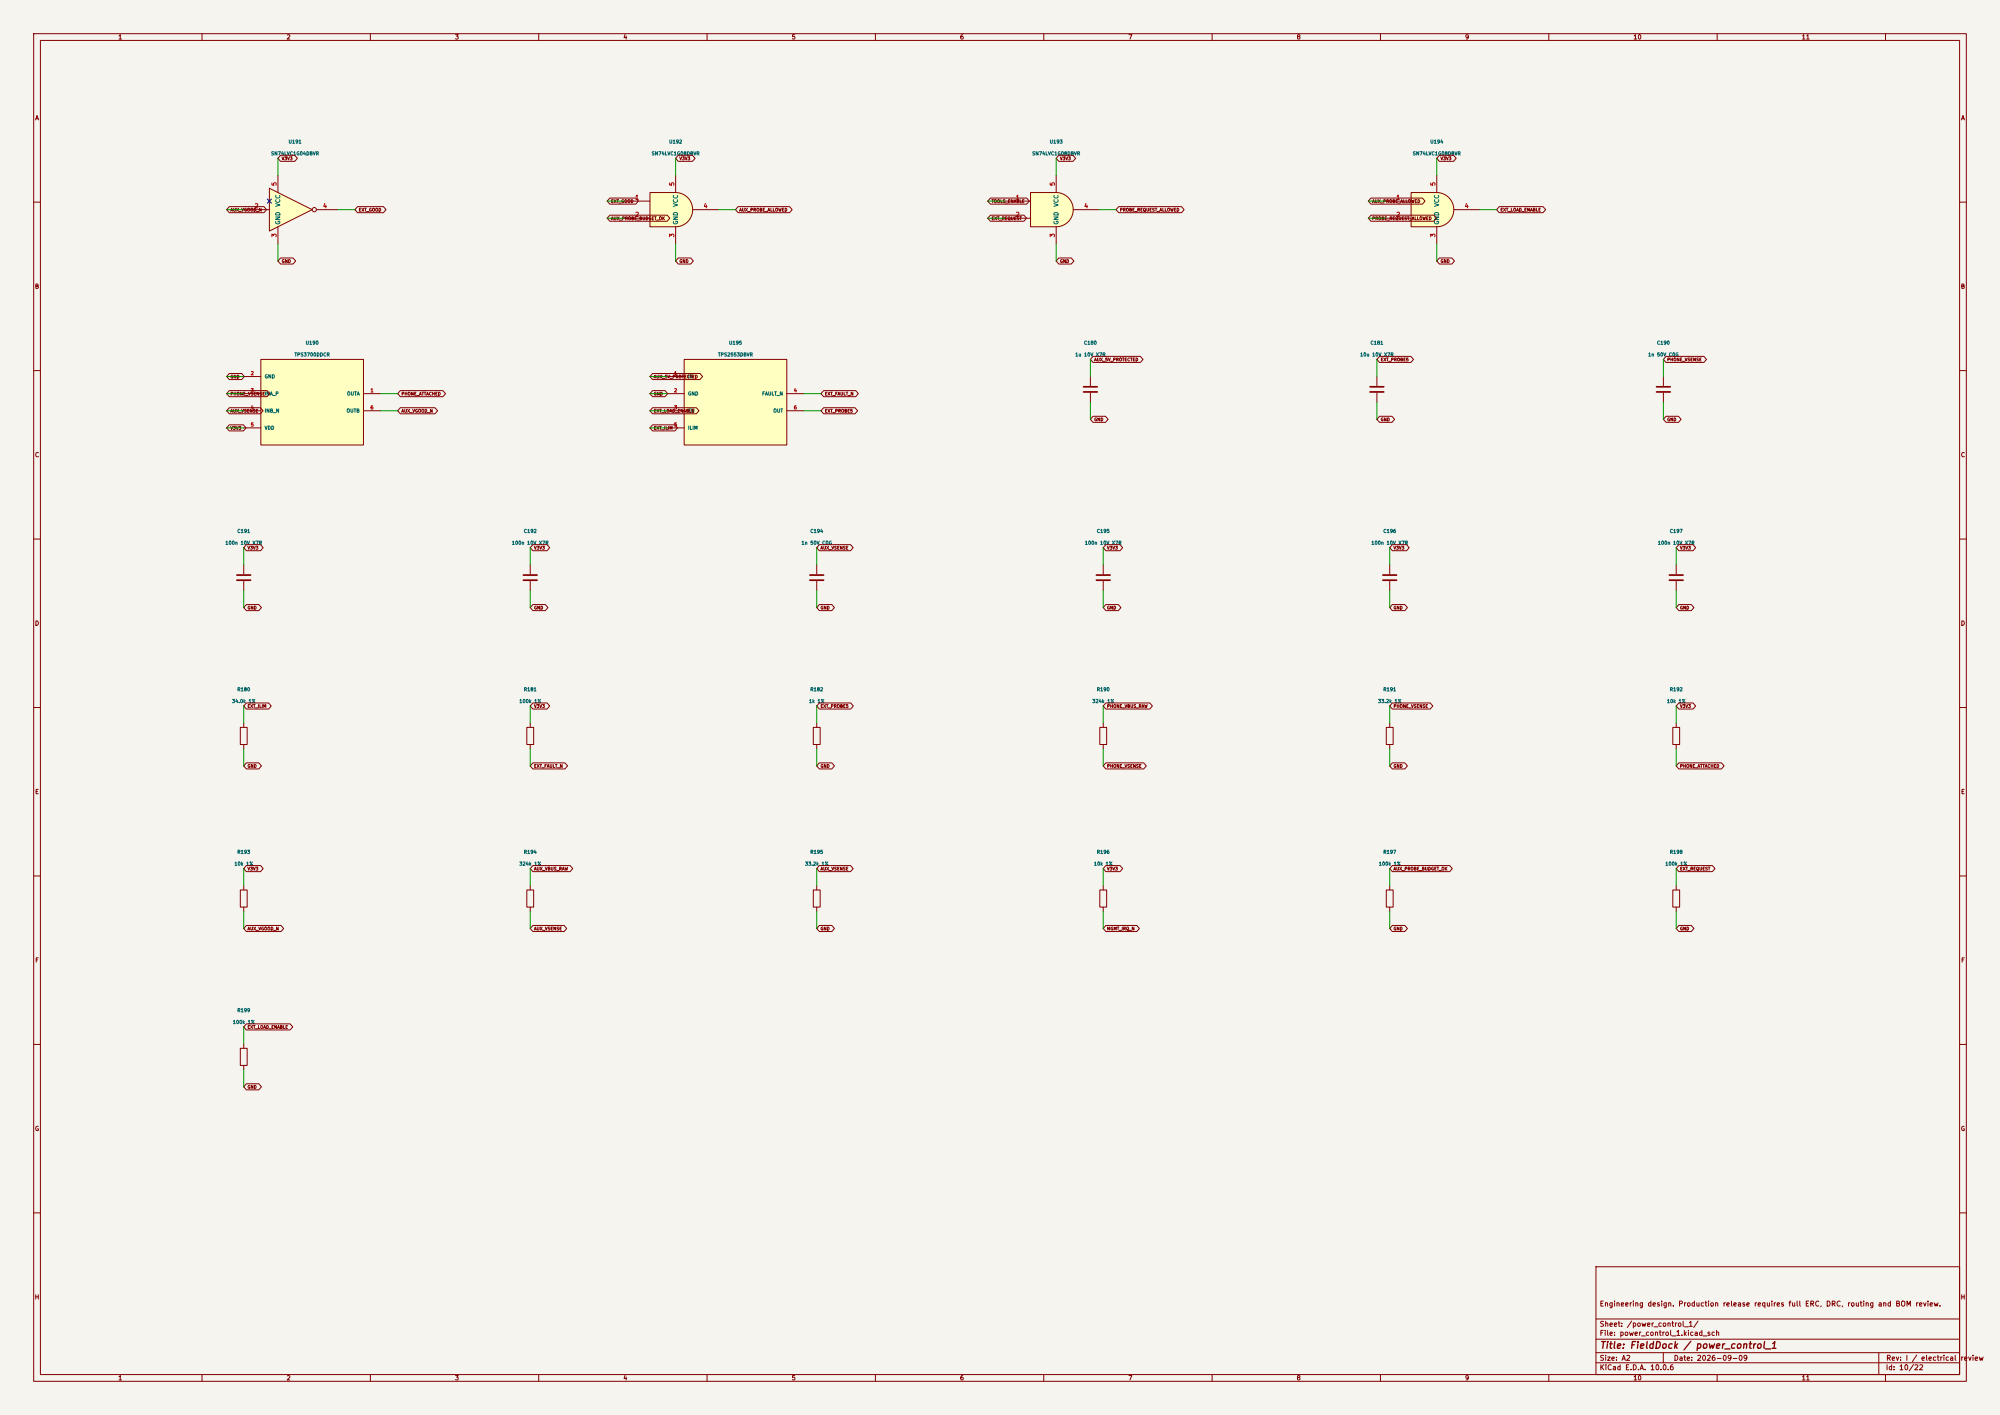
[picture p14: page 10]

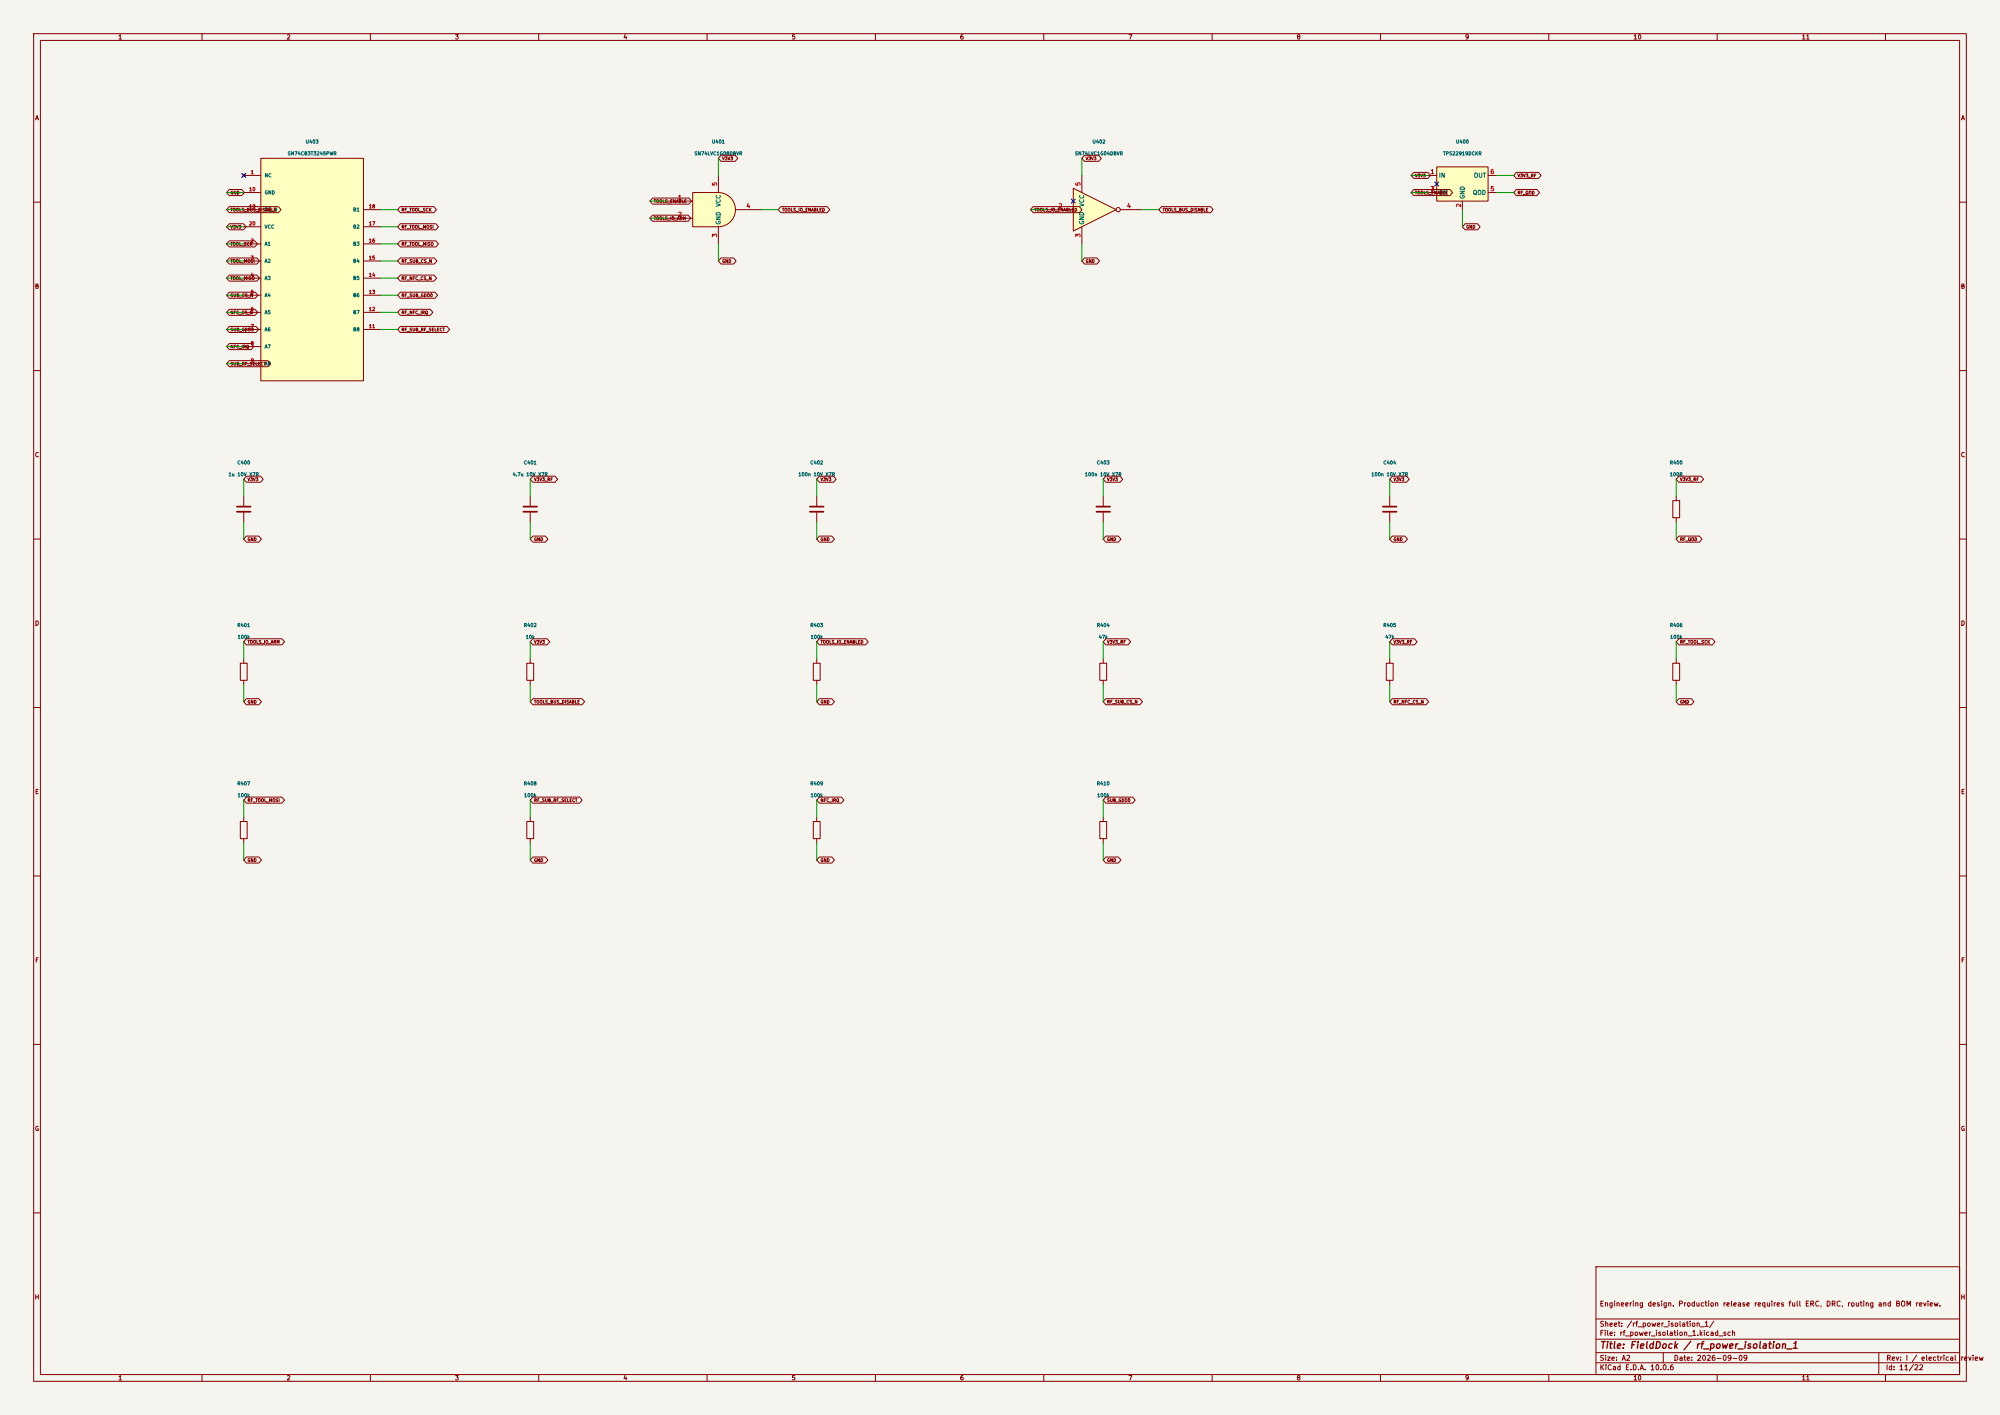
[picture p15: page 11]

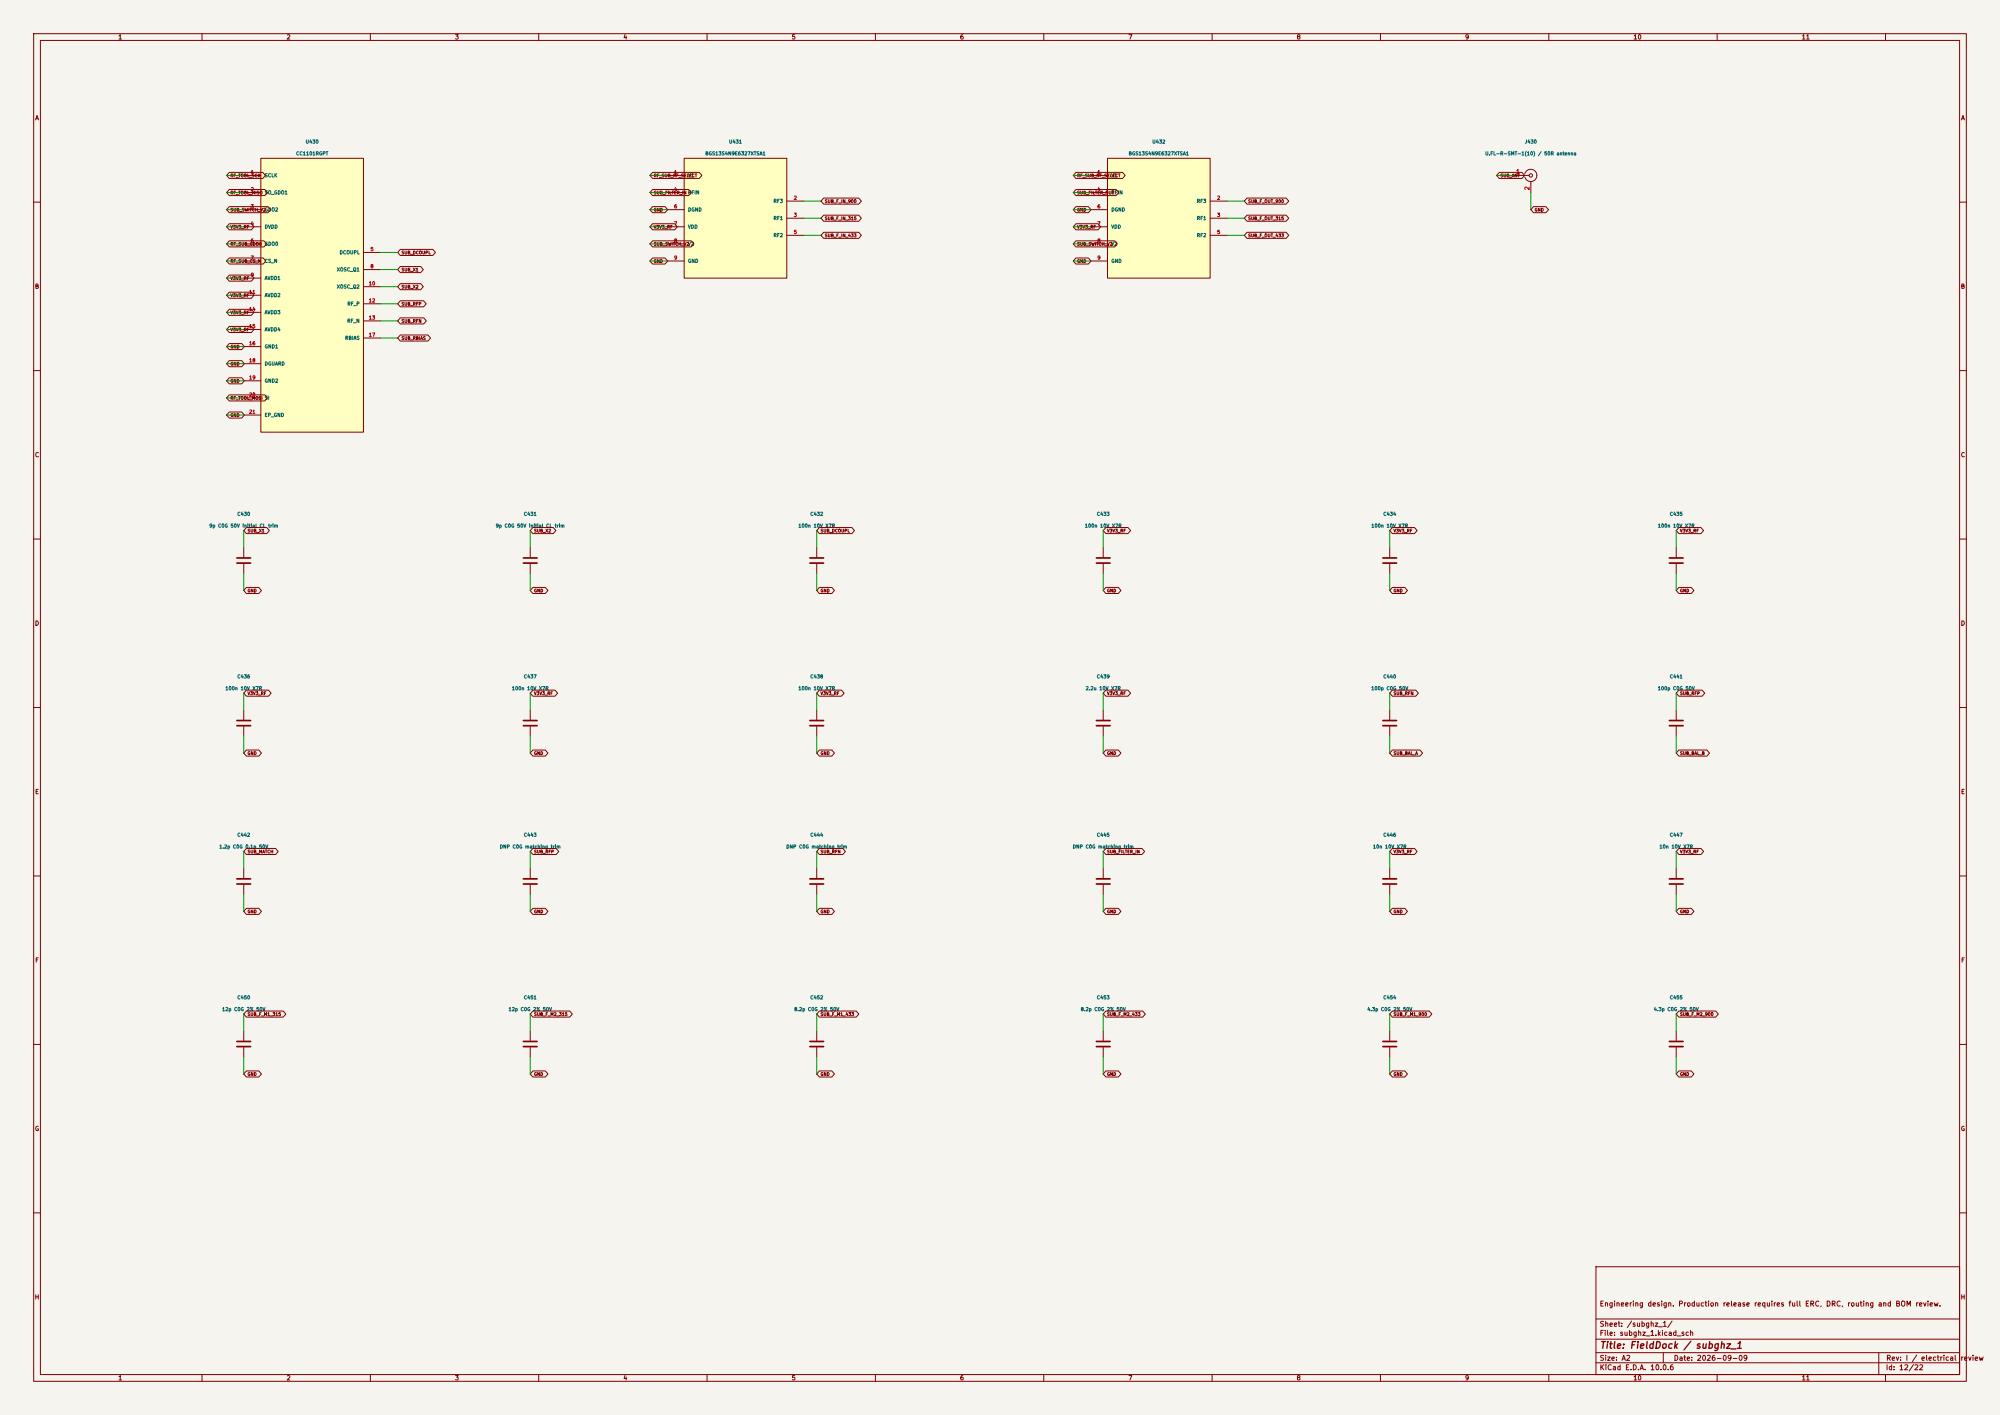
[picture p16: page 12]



J500 NFC antenna 1.37uH nominal / soldered twisted pair





2x8 2.54mm GPIO 3.3V / 5V-tolerant inputs NC 1



iButton contact probe / DATA GND



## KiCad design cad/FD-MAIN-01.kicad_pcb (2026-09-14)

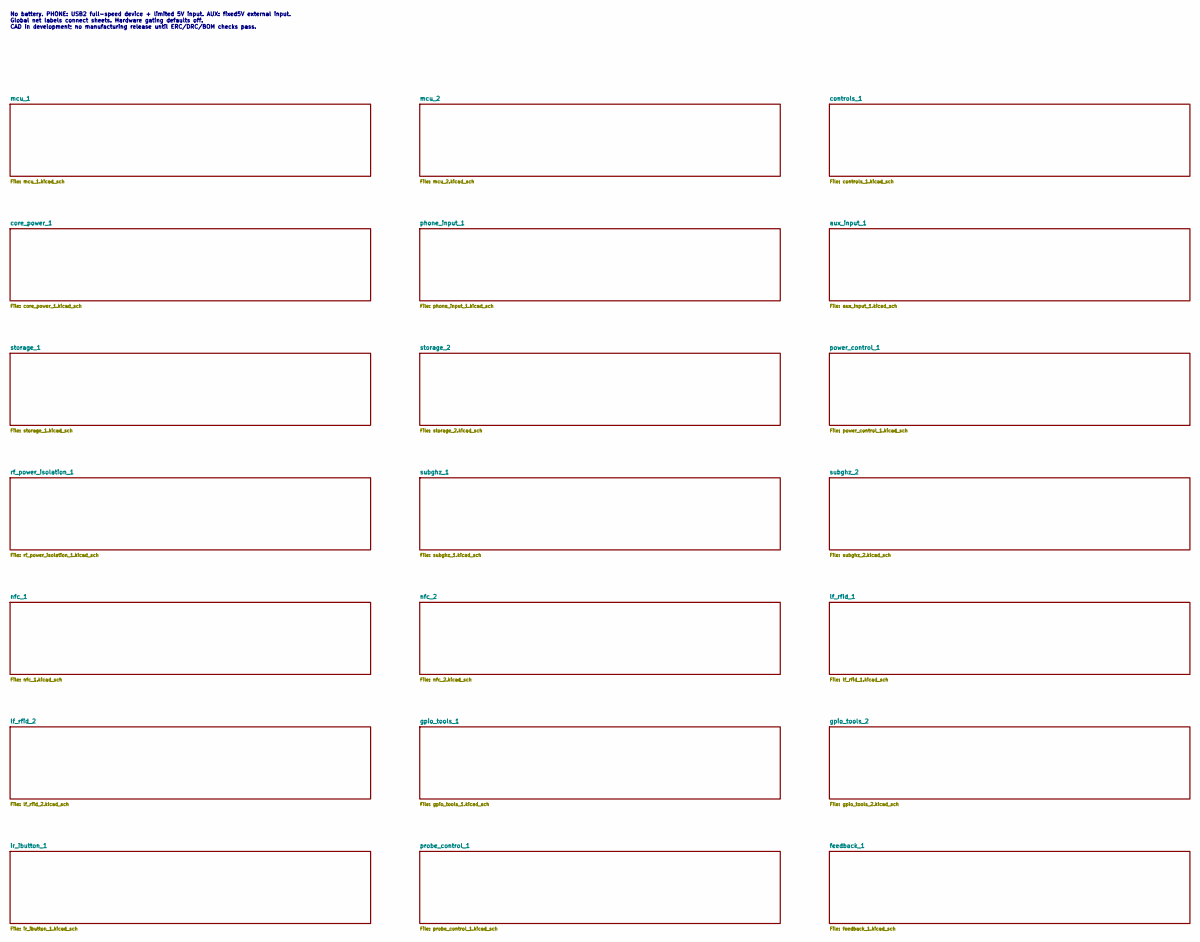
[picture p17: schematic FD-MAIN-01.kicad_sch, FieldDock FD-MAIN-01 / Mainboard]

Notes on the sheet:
No battery. PHONE: USB2 full-speed device + limited 5V input. AUX: fixed5V external input. Global net labels connect sheets. Hardware gating defaults off. CAD in development; no manufacturing release until ERC/DRC/BOM checks pass.

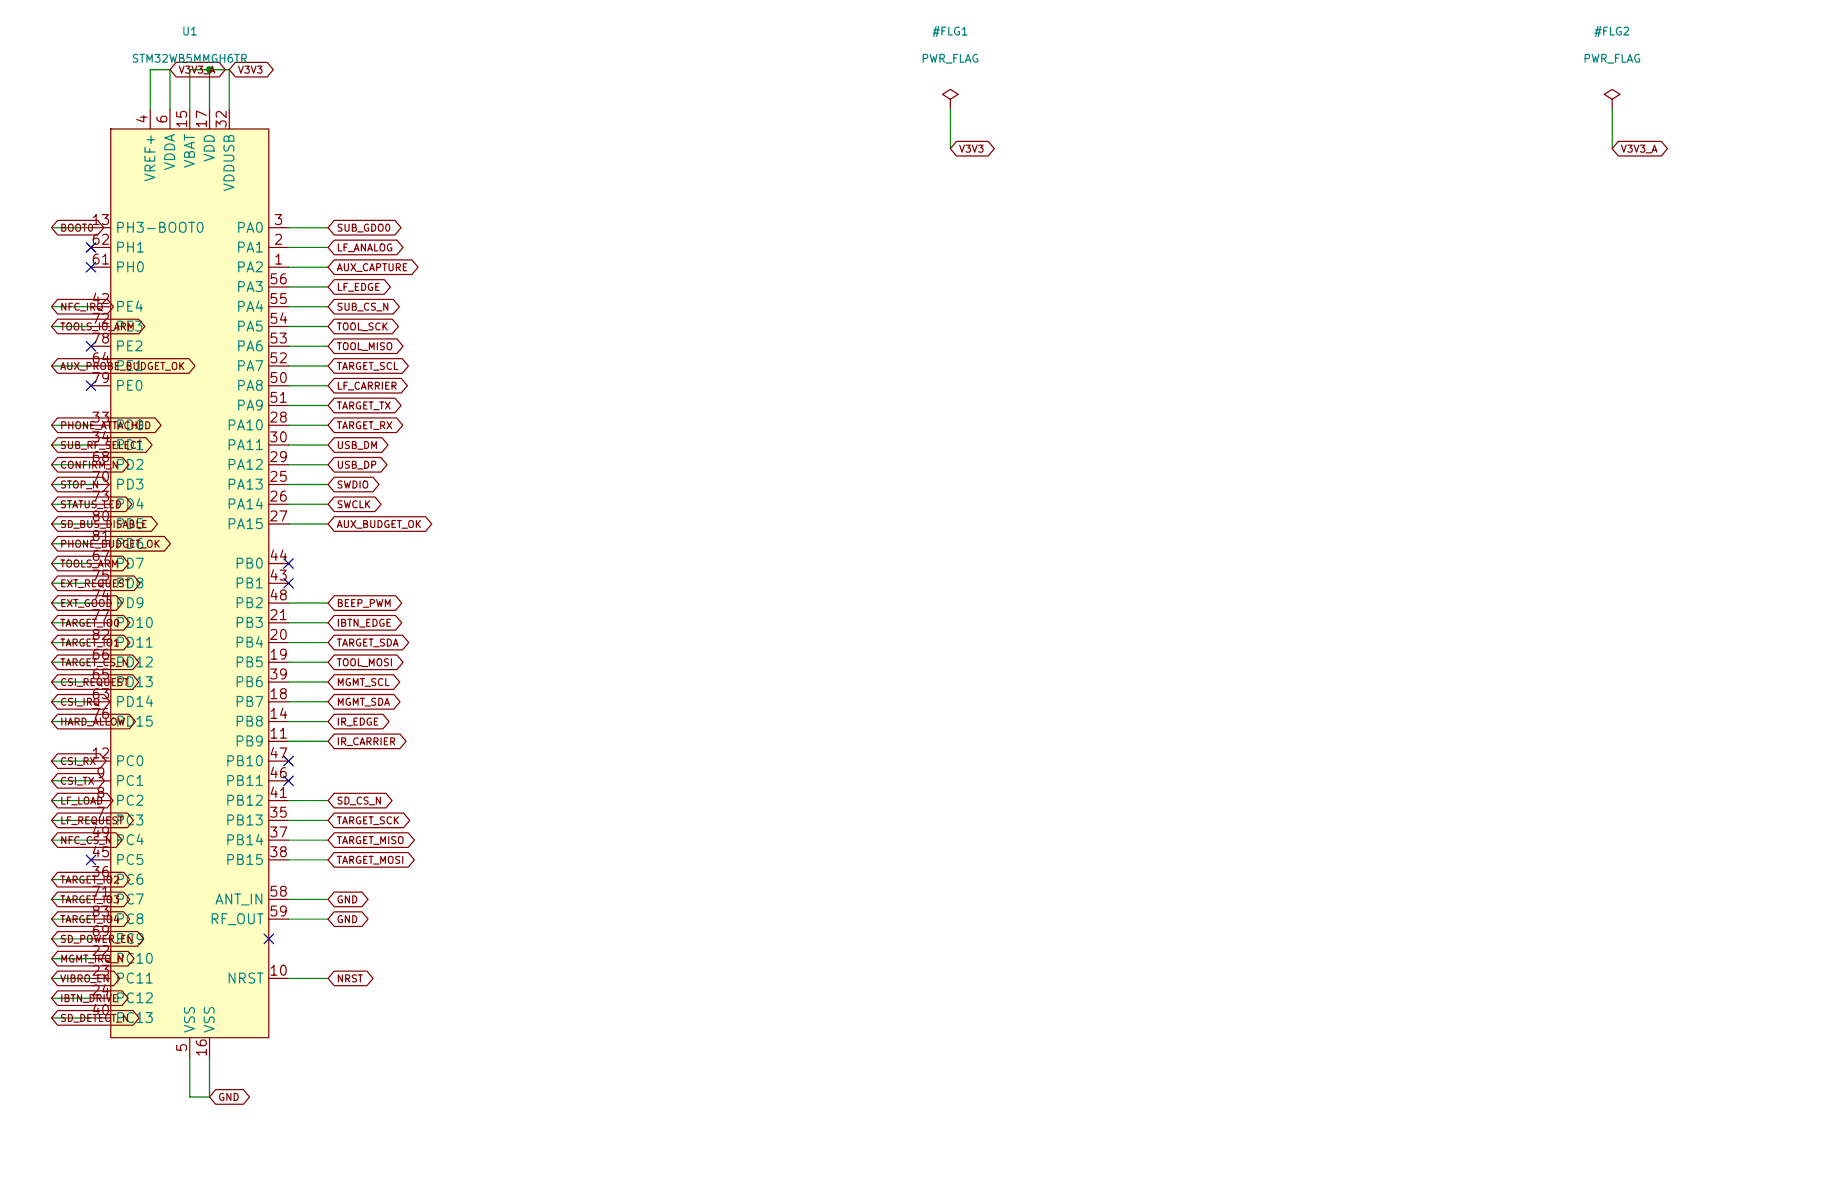
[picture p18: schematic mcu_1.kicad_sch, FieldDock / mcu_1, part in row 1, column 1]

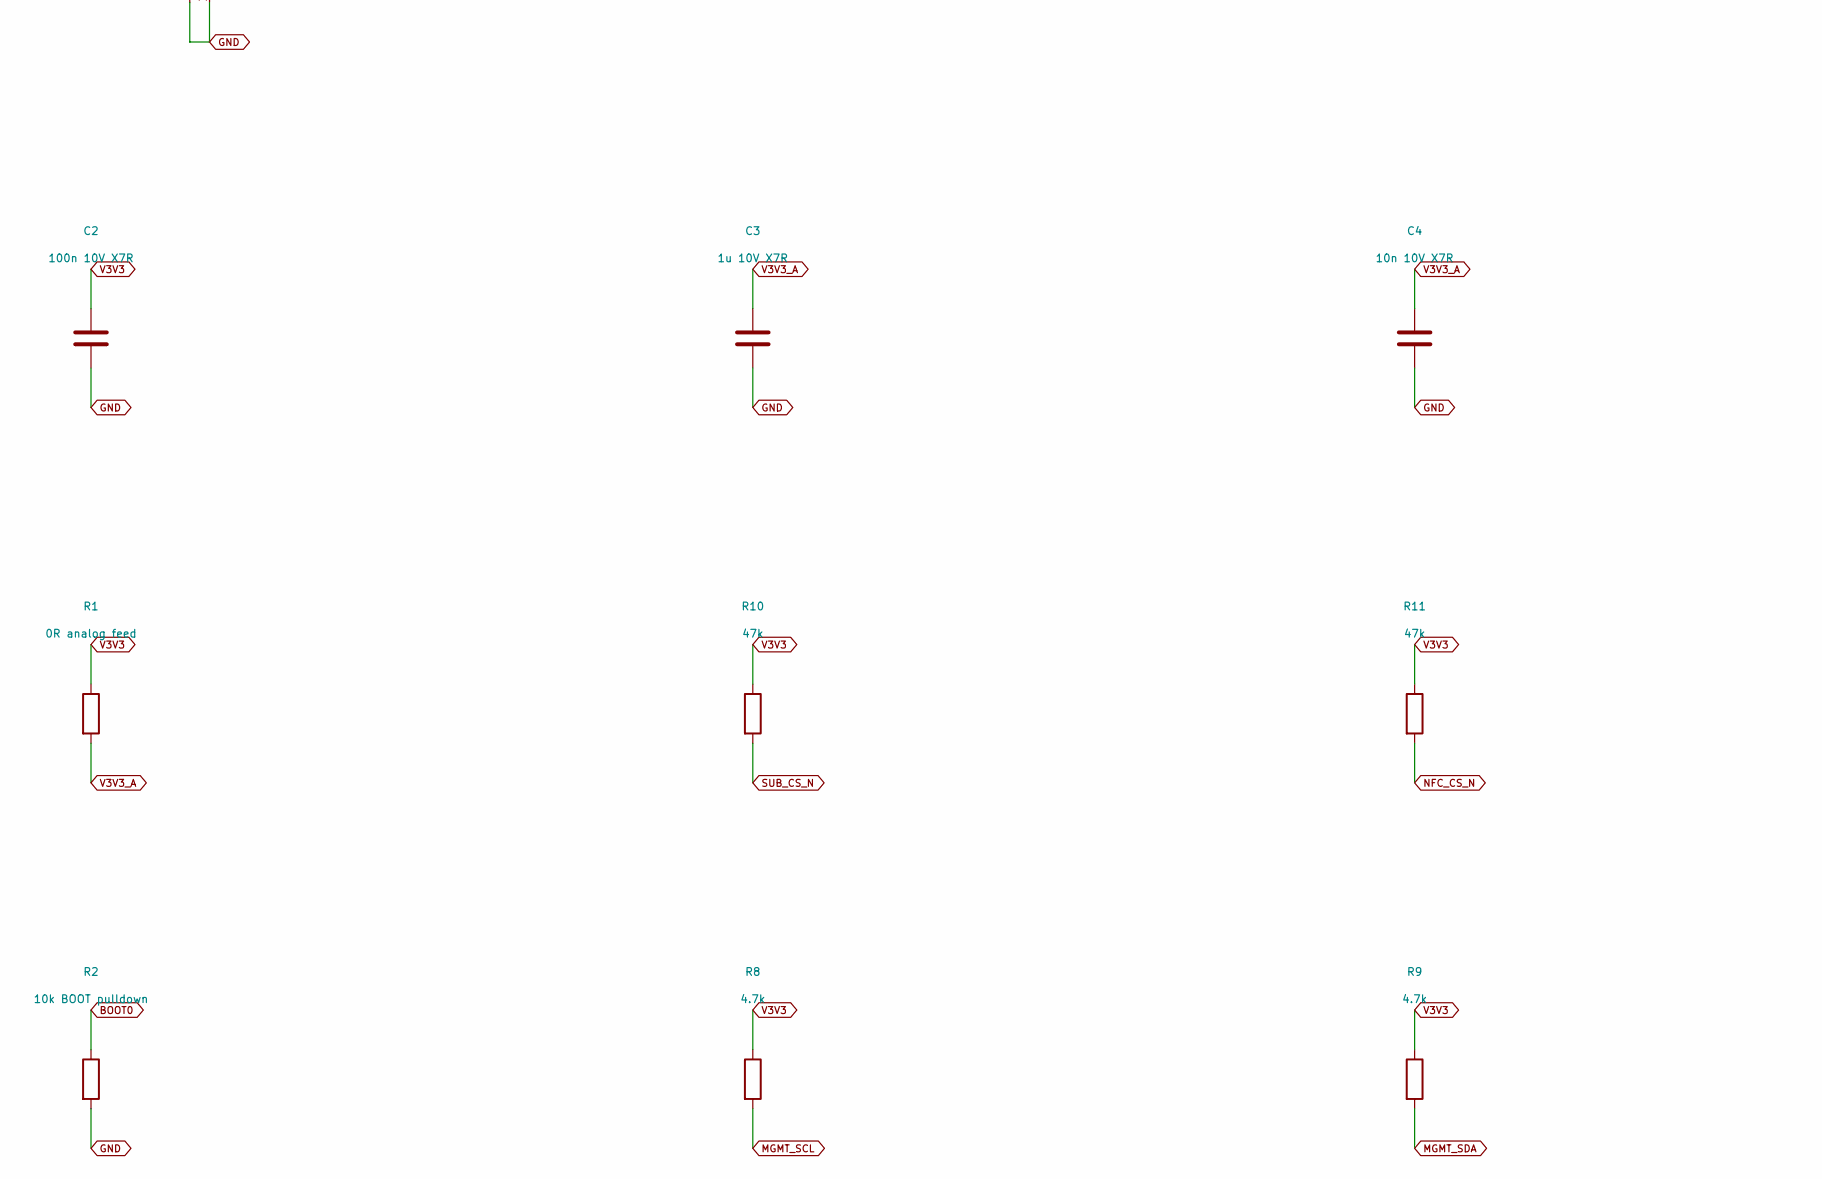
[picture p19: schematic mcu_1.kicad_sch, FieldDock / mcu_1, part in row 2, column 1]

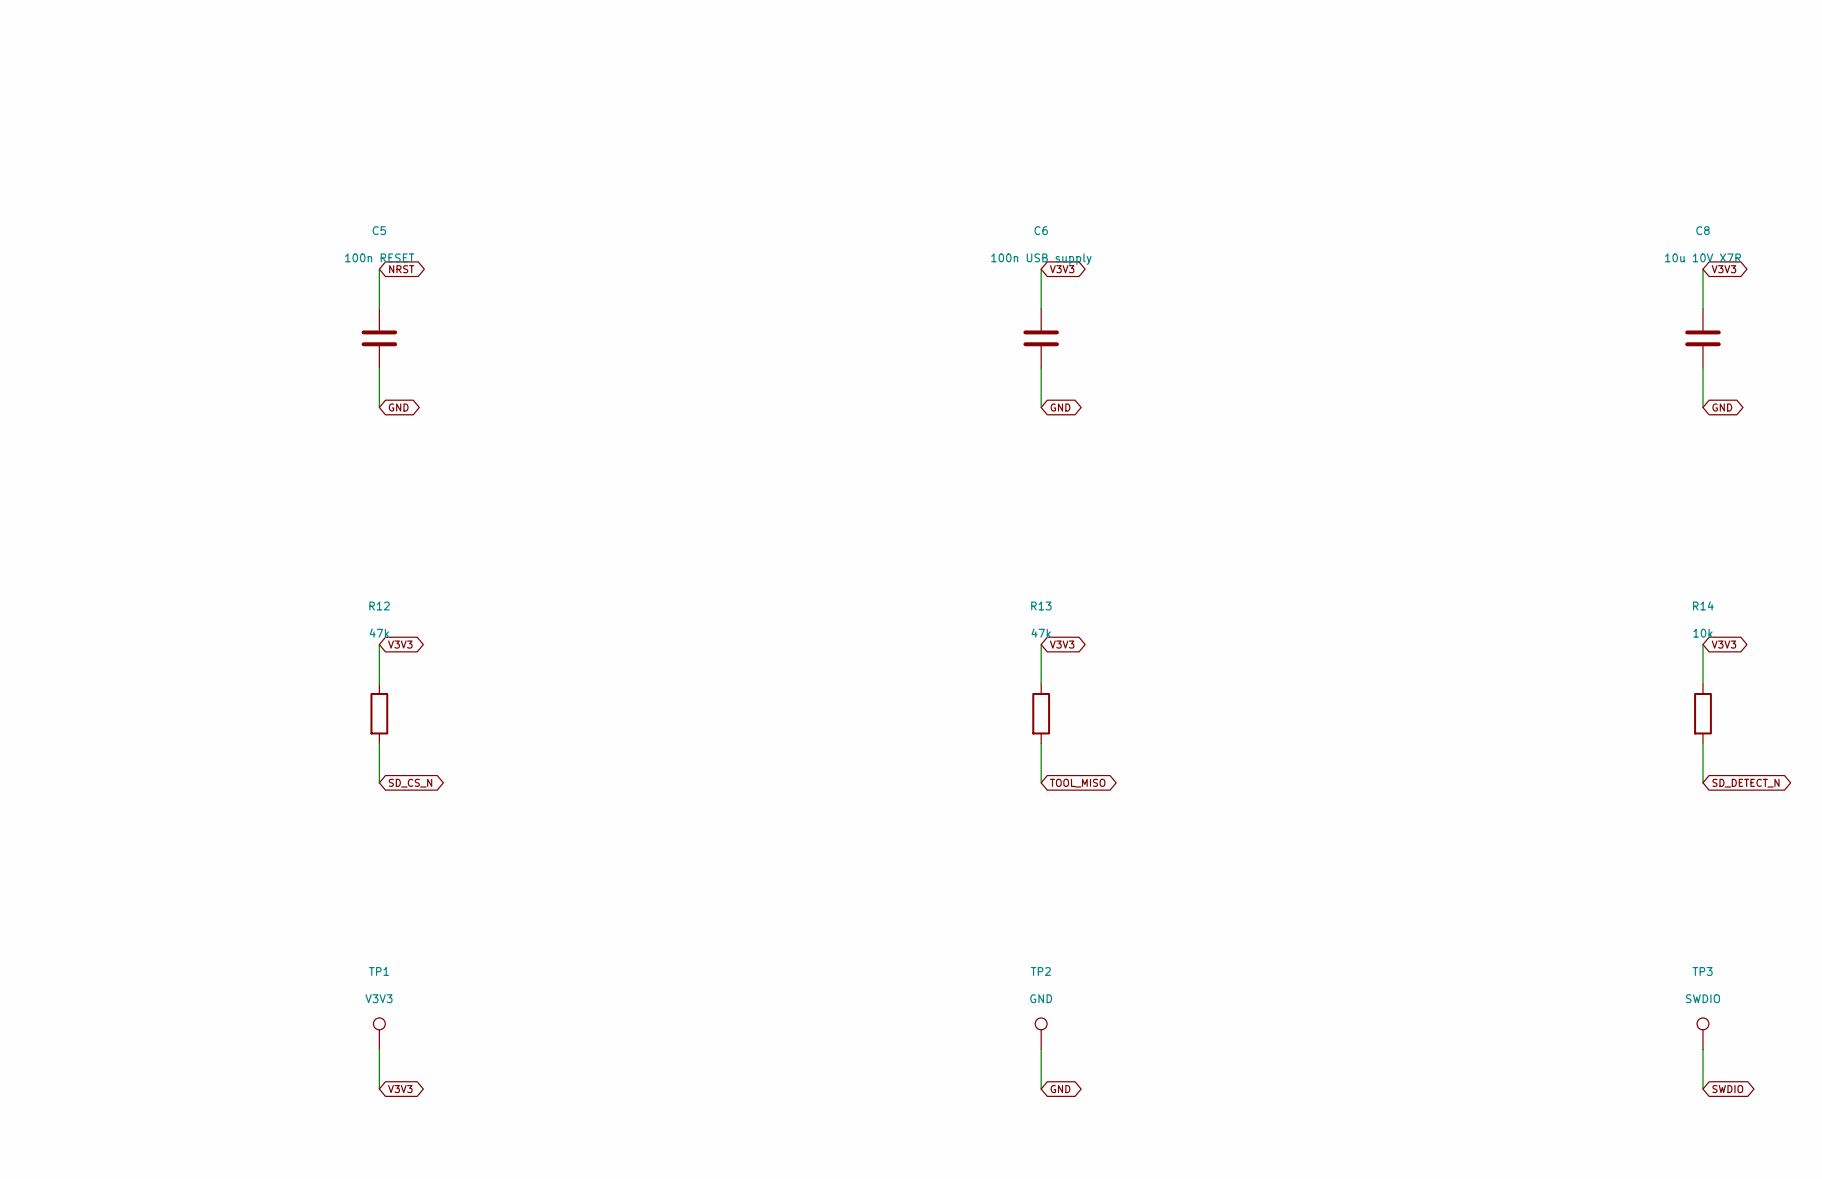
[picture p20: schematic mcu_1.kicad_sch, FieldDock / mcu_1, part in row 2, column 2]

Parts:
C1: 4.7u 10V X7R; C_0805_2012Metric
C2: 100n 10V X7R; C_0603_1608Metric
C3: 1u 10V X7R; C_0603_1608Metric
C4: 10n 10V X7R; C_0603_1608Metric
C5: 100n RESET; C_0603_1608Metric
C6: 100n USB supply; C_0603_1608Metric
C8: 10u 10V X7R; C_0805_2012Metric
R1: 0R analog feed; R_0603_1608Metric
R2: 10k BOOT pulldown; R_0603_1608Metric
R8, R9: 4.7k; R_0603_1608Metric
R10, R11, R12, R13: 47k; R_0603_1608Metric
R14: 10k; R_0603_1608Metric
TP1: V3V3; TestPoint_Pad_D1.0mm
TP2: GND; TestPoint_Pad_D1.0mm
TP3: SWDIO; TestPoint_Pad_D1.0mm
U1: STM32WB5MMGH6TR; ST-SiP-LGA-86-11x7.3mm

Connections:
AUX_BUDGET_OK: U1.27 (PA15); also elsewhere on the board
AUX_CAPTURE: U1.1 (PA2); also elsewhere on the board
AUX_PROBE_BUDGET_OK: U1.64 (PE1); also elsewhere on the board
BEEP_PWM: U1.48 (PB2); also elsewhere on the board
BOOT0: R2.1, U1.13 (PH3-BOOT0); also elsewhere on the board
CONFIRM_N: U1.68 (PD2); also elsewhere on the board
CSI_IRQ: U1.63 (PD14); also elsewhere on the board
CSI_REQUEST: U1.65 (PD13); also elsewhere on the board
CSI_RX: U1.12 (PC0); also elsewhere on the board
CSI_TX: U1.9 (PC1); also elsewhere on the board
EXT_GOOD: U1.74 (PD9); also elsewhere on the board
EXT_REQUEST: U1.75 (PD8); also elsewhere on the board
GND: C1.2, C2.2, C3.2, C4.2, C5.2, C6.2, C8.2, R2.2, TP2.1, U1.5 (VSS), U1.16 (VSS), U1.31 (VSS), U1.57 (VSS), U1.58 (ANT_IN), U1.59 (RF_OUT), U1.60 (VSS), U1.84 (VSS), U1.86 (VSS); also elsewhere on the board
HARD_ALLOW: U1.76 (PD15); also elsewhere on the board
IBTN_DRIVE: U1.24 (PC12); also elsewhere on the board
IBTN_EDGE: U1.21 (PB3); also elsewhere on the board
IR_CARRIER: U1.11 (PB9); also elsewhere on the board
IR_EDGE: U1.14 (PB8); also elsewhere on the board
LF_ANALOG: U1.2 (PA1); also elsewhere on the board
LF_CARRIER: U1.50 (PA8); also elsewhere on the board
LF_EDGE: U1.56 (PA3); also elsewhere on the board
LF_LOAD: U1.8 (PC2); also elsewhere on the board
LF_REQUEST: U1.7 (PC3); also elsewhere on the board
MGMT_IRQ_N: U1.22 (PC10); also elsewhere on the board
MGMT_SCL: R8.2, U1.39 (PB6); also elsewhere on the board
MGMT_SDA: R9.2, U1.18 (PB7); also elsewhere on the board
NFC_CS_N: R11.2, U1.49 (PC4); also elsewhere on the board
NFC_IRQ: U1.42 (PE4); also elsewhere on the board
NRST: C5.1, U1.10 (NRST); also elsewhere on the board
PHONE_ATTACHED: U1.33 (PD0); also elsewhere on the board
PHONE_BUDGET_OK: U1.81 (PD6); also elsewhere on the board
SD_BUS_DISABLE: U1.80 (PD5); also elsewhere on the board
SD_CS_N: R12.2, U1.41 (PB12); also elsewhere on the board
SD_DETECT_N: R14.2, U1.40 (PC13); also elsewhere on the board
SD_POWER_EN: U1.69 (PC9); also elsewhere on the board
STATUS_LED: U1.73 (PD4); also elsewhere on the board
STOP_N: U1.70 (PD3); also elsewhere on the board
SUB_CS_N: R10.2, U1.55 (PA4); also elsewhere on the board
SUB_GDO0: U1.3 (PA0); also elsewhere on the board
SUB_RF_SELECT: U1.34 (PD1); also elsewhere on the board
SWCLK: U1.26 (PA14); also elsewhere on the board
SWDIO: TP3.1, U1.25 (PA13)
TARGET_CS_N: U1.66 (PD12); also elsewhere on the board
TARGET_IO0: U1.77 (PD10); also elsewhere on the board
TARGET_IO1: U1.82 (PD11); also elsewhere on the board
TARGET_IO2: U1.36 (PC6); also elsewhere on the board
TARGET_IO3: U1.71 (PC7); also elsewhere on the board
TARGET_IO4: U1.83 (PC8); also elsewhere on the board
TARGET_MISO: U1.37 (PB14); also elsewhere on the board
TARGET_MOSI: U1.38 (PB15); also elsewhere on the board
TARGET_RX: U1.28 (PA10); also elsewhere on the board
TARGET_SCK: U1.35 (PB13); also elsewhere on the board
TARGET_SCL: U1.52 (PA7); also elsewhere on the board
TARGET_SDA: U1.20 (PB4); also elsewhere on the board
TARGET_TX: U1.51 (PA9); also elsewhere on the board
TOOLS_ARM: U1.67 (PD7); also elsewhere on the board
TOOLS_IO_ARM: U1.72 (PE3); also elsewhere on the board
TOOL_MISO: R13.2, U1.53 (PA6); also elsewhere on the board
TOOL_MOSI: U1.19 (PB5); also elsewhere on the board
TOOL_SCK: U1.54 (PA5); also elsewhere on the board
USB_DM: U1.30 (PA11); also elsewhere on the board
USB_DP: U1.29 (PA12); also elsewhere on the board
V3V3: C1.1, C2.1, C6.1, C8.1, R1.1, R8.1, R9.1, R10.1, R11.1, R12.1, R13.1, R14.1, TP1.1, U1.15 (VBAT), U1.17 (VDD), U1.32 (VDDUSB); also elsewhere on the board
V3V3_A: C3.1, C4.1, R1.2, U1.4 (VREF+), U1.6 (VDDA)
VIBRO_EN: U1.23 (PC11); also elsewhere on the board

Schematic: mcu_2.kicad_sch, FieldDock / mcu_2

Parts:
TP4: SWCLK; TestPoint_Pad_D1.0mm
TP5: NRST; TestPoint_Pad_D1.0mm
TP6: CORE5; TestPoint_Pad_D1.0mm
TP7: EXT5; TestPoint_Pad_D1.0mm
TP8: PHONE5; TestPoint_Pad_D1.0mm

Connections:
CORE5: TP6.1; also elsewhere on the board
EXT5: TP7.1; also elsewhere on the board
NRST: TP5.1; also elsewhere on the board
PHONE5: TP8.1; also elsewhere on the board
SWCLK: TP4.1; also elsewhere on the board

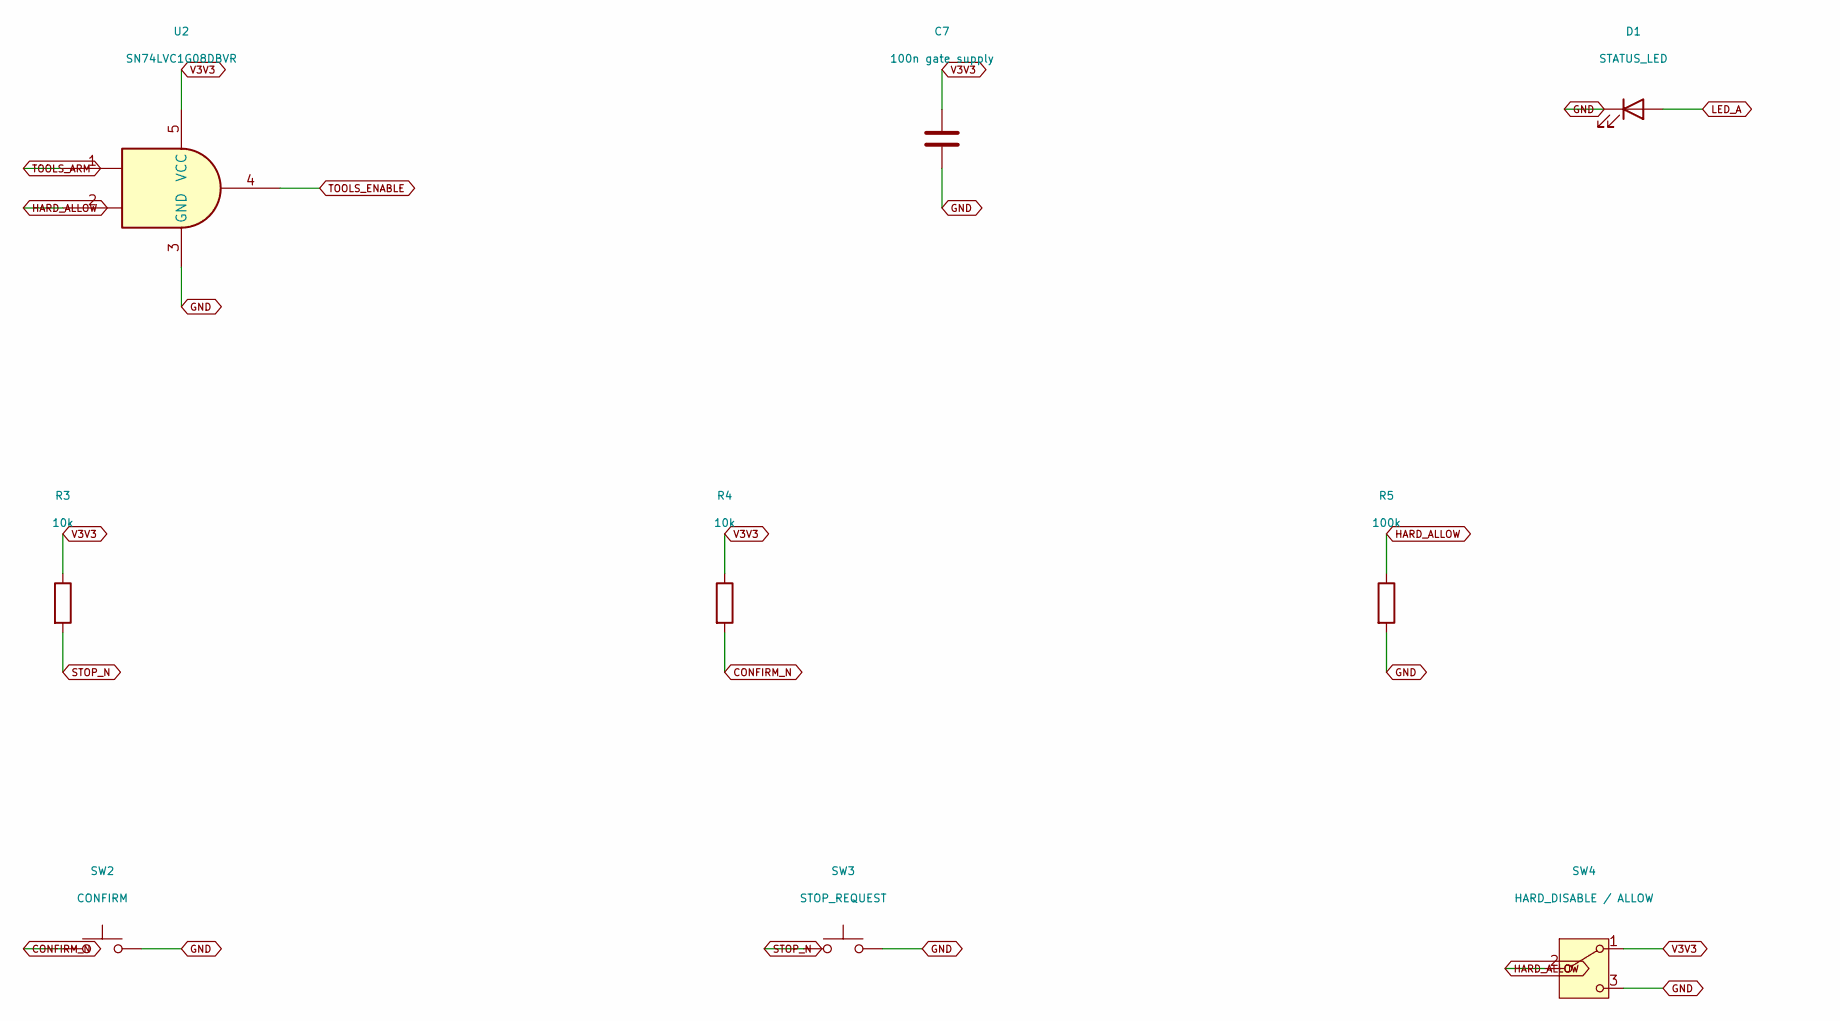
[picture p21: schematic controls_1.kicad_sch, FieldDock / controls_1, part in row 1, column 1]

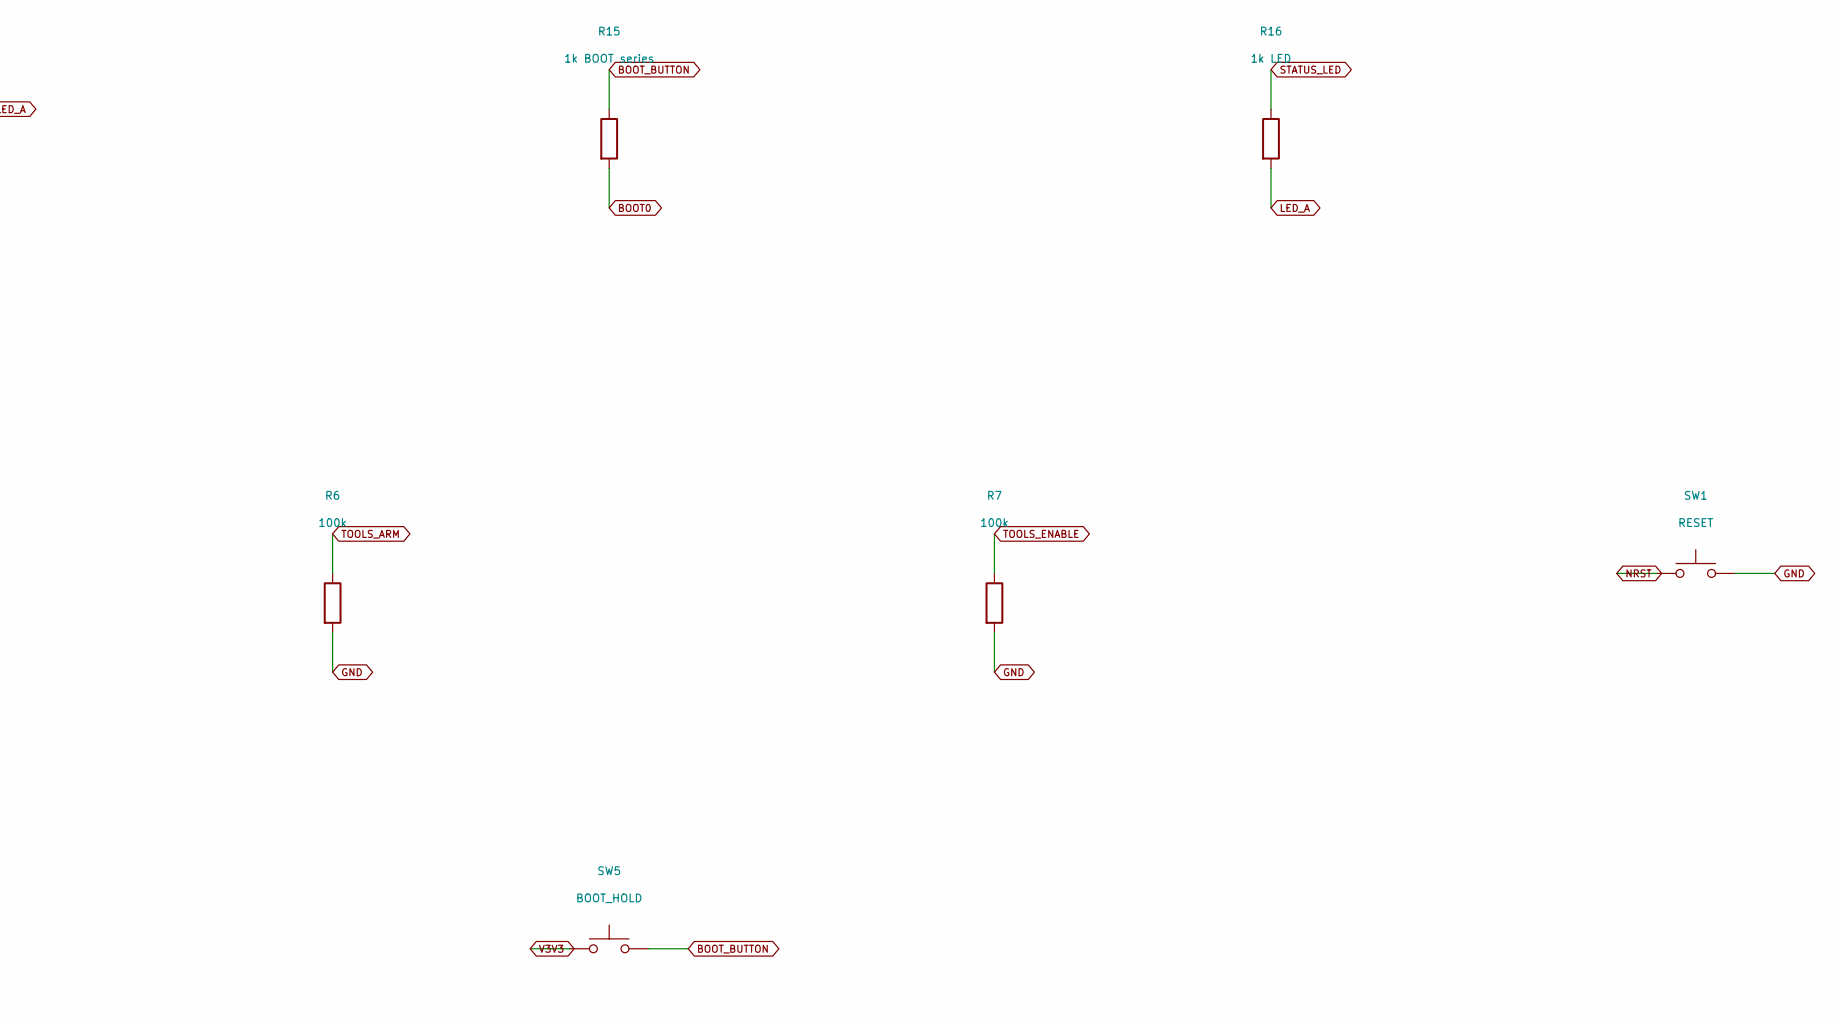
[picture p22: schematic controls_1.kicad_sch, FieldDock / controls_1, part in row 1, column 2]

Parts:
C7: 100n gate supply; C_0603_1608Metric
D1: STATUS_LED; LED_0603_1608Metric
R3, R4: 10k; R_0603_1608Metric
R5, R6, R7: 100k; R_0603_1608Metric
R15: 1k BOOT series; R_0603_1608Metric
R16: 1k LED; R_0603_1608Metric
SW1: RESET; SW_SPST_TL3342
SW2: CONFIRM; SW_SPST_TL3342
SW3: STOP_REQUEST; SW_SPST_TL3342
SW4: HARD_DISABLE / ALLOW; SW_SPDT_CK_JS102011SAQN
SW5: BOOT_HOLD; SW_SPST_TL3342
U2: SN74LVC1G08DBVR; SOT-23-5

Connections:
BOOT0: R15.2; also elsewhere on the board
BOOT_BUTTON: R15.1, SW5.2
CONFIRM_N: R4.2, SW2.1; also elsewhere on the board
GND: C7.2, D1.1 (K), R5.2, R6.2, R7.2, SW1.2, SW2.2, SW3.2, SW4.3 (C), U2.3 (GND); also elsewhere on the board
HARD_ALLOW: R5.1, SW4.2 (B), U2.2; also elsewhere on the board
LED_A: D1.2 (A), R16.2
NRST: SW1.1; also elsewhere on the board
STATUS_LED: R16.1; also elsewhere on the board
STOP_N: R3.2, SW3.1; also elsewhere on the board
TOOLS_ARM: R6.1, U2.1; also elsewhere on the board
TOOLS_ENABLE: R7.1, U2.4; also elsewhere on the board
V3V3: C7.1, R3.1, R4.1, SW4.1 (A), SW5.1, U2.5 (VCC); also elsewhere on the board

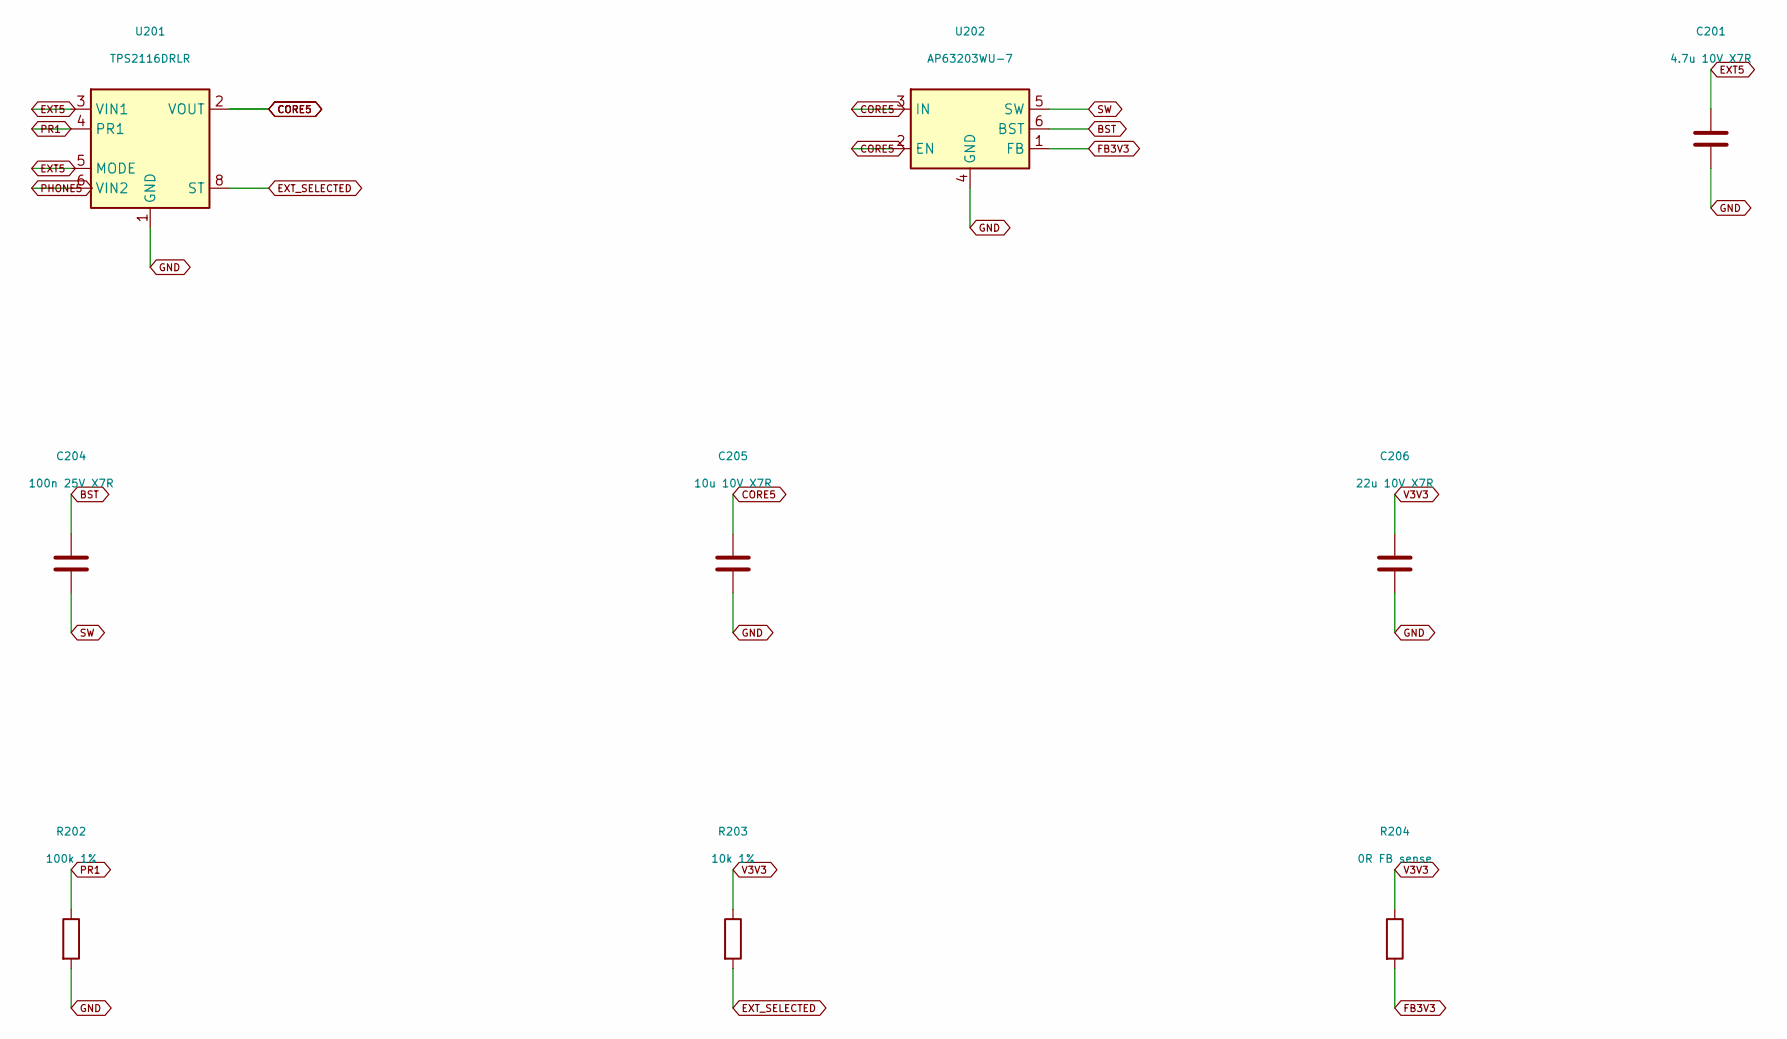
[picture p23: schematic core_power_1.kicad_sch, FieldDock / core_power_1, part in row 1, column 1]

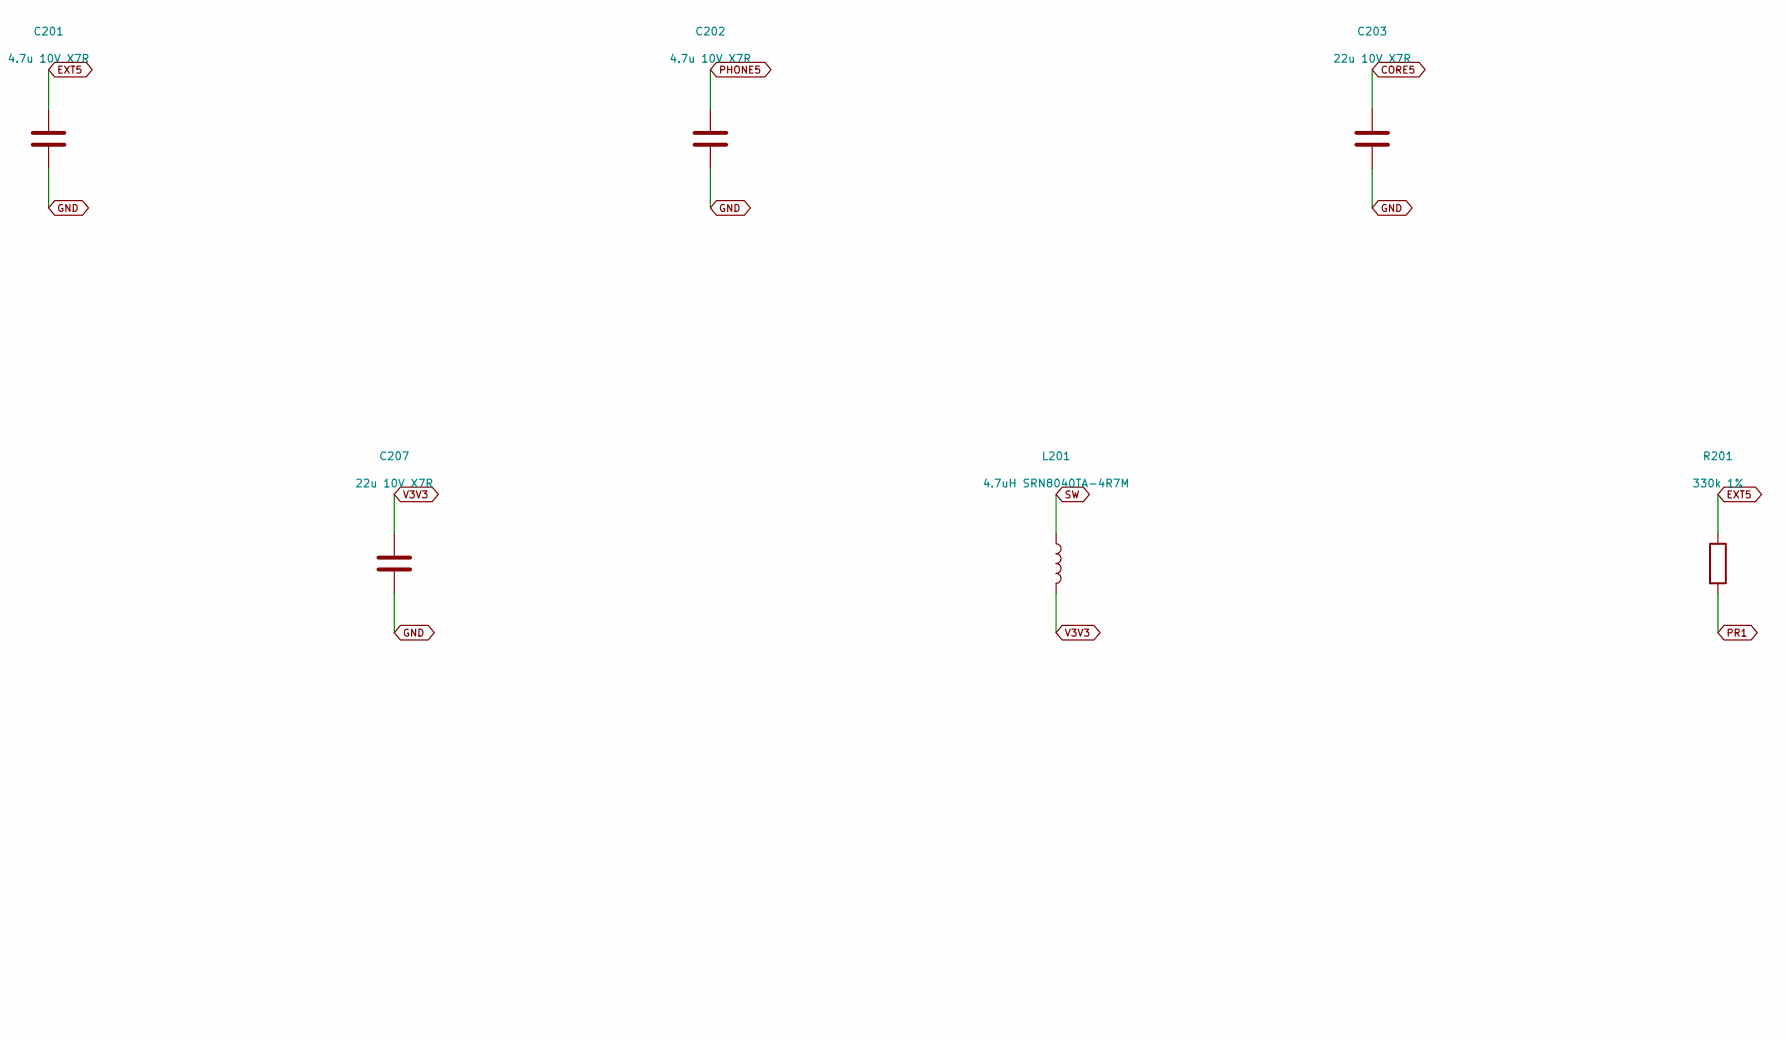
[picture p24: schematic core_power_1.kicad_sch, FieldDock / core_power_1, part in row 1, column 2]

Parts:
C201, C202: 4.7u 10V X7R; C_0805_2012Metric
C203, C206, C207: 22u 10V X7R; C_1206_3216Metric
C204: 100n 25V X7R; C_0402_1005Metric
C205: 10u 10V X7R; C_0805_2012Metric
L201: 4.7uH SRN8040TA-4R7M; L_Bourns_SRN8040TA
R201: 330k 1%; R_0603_1608Metric
R202: 100k 1%; R_0603_1608Metric
R203: 10k 1%; R_0603_1608Metric
R204: 0R FB sense; R_0603_1608Metric
U201: TPS2116DRLR; SOT-583-8
U202: AP63203WU-7; TSOT-23-6

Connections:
BST: C204.1, U202.6 (BST)
CORE5: C203.1, C205.1, U201.2 (VOUT), U201.7 (VOUT), U202.2 (EN), U202.3 (IN); also elsewhere on the board
EXT5: C201.1, R201.1, U201.3 (VIN1), U201.5 (MODE); also elsewhere on the board
EXT_SELECTED: R203.2, U201.8 (ST)
FB3V3: R204.2, U202.1 (FB)
GND: C201.2, C202.2, C203.2, C205.2, C206.2, C207.2, R202.2, U201.1 (GND), U202.4 (GND); also elsewhere on the board
PHONE5: C202.1, U201.6 (VIN2); also elsewhere on the board
PR1: R201.2, R202.1, U201.4 (PR1)
SW: C204.2, L201.1, U202.5 (SW)
V3V3: C206.1, C207.1, L201.2, R203.1, R204.1; also elsewhere on the board

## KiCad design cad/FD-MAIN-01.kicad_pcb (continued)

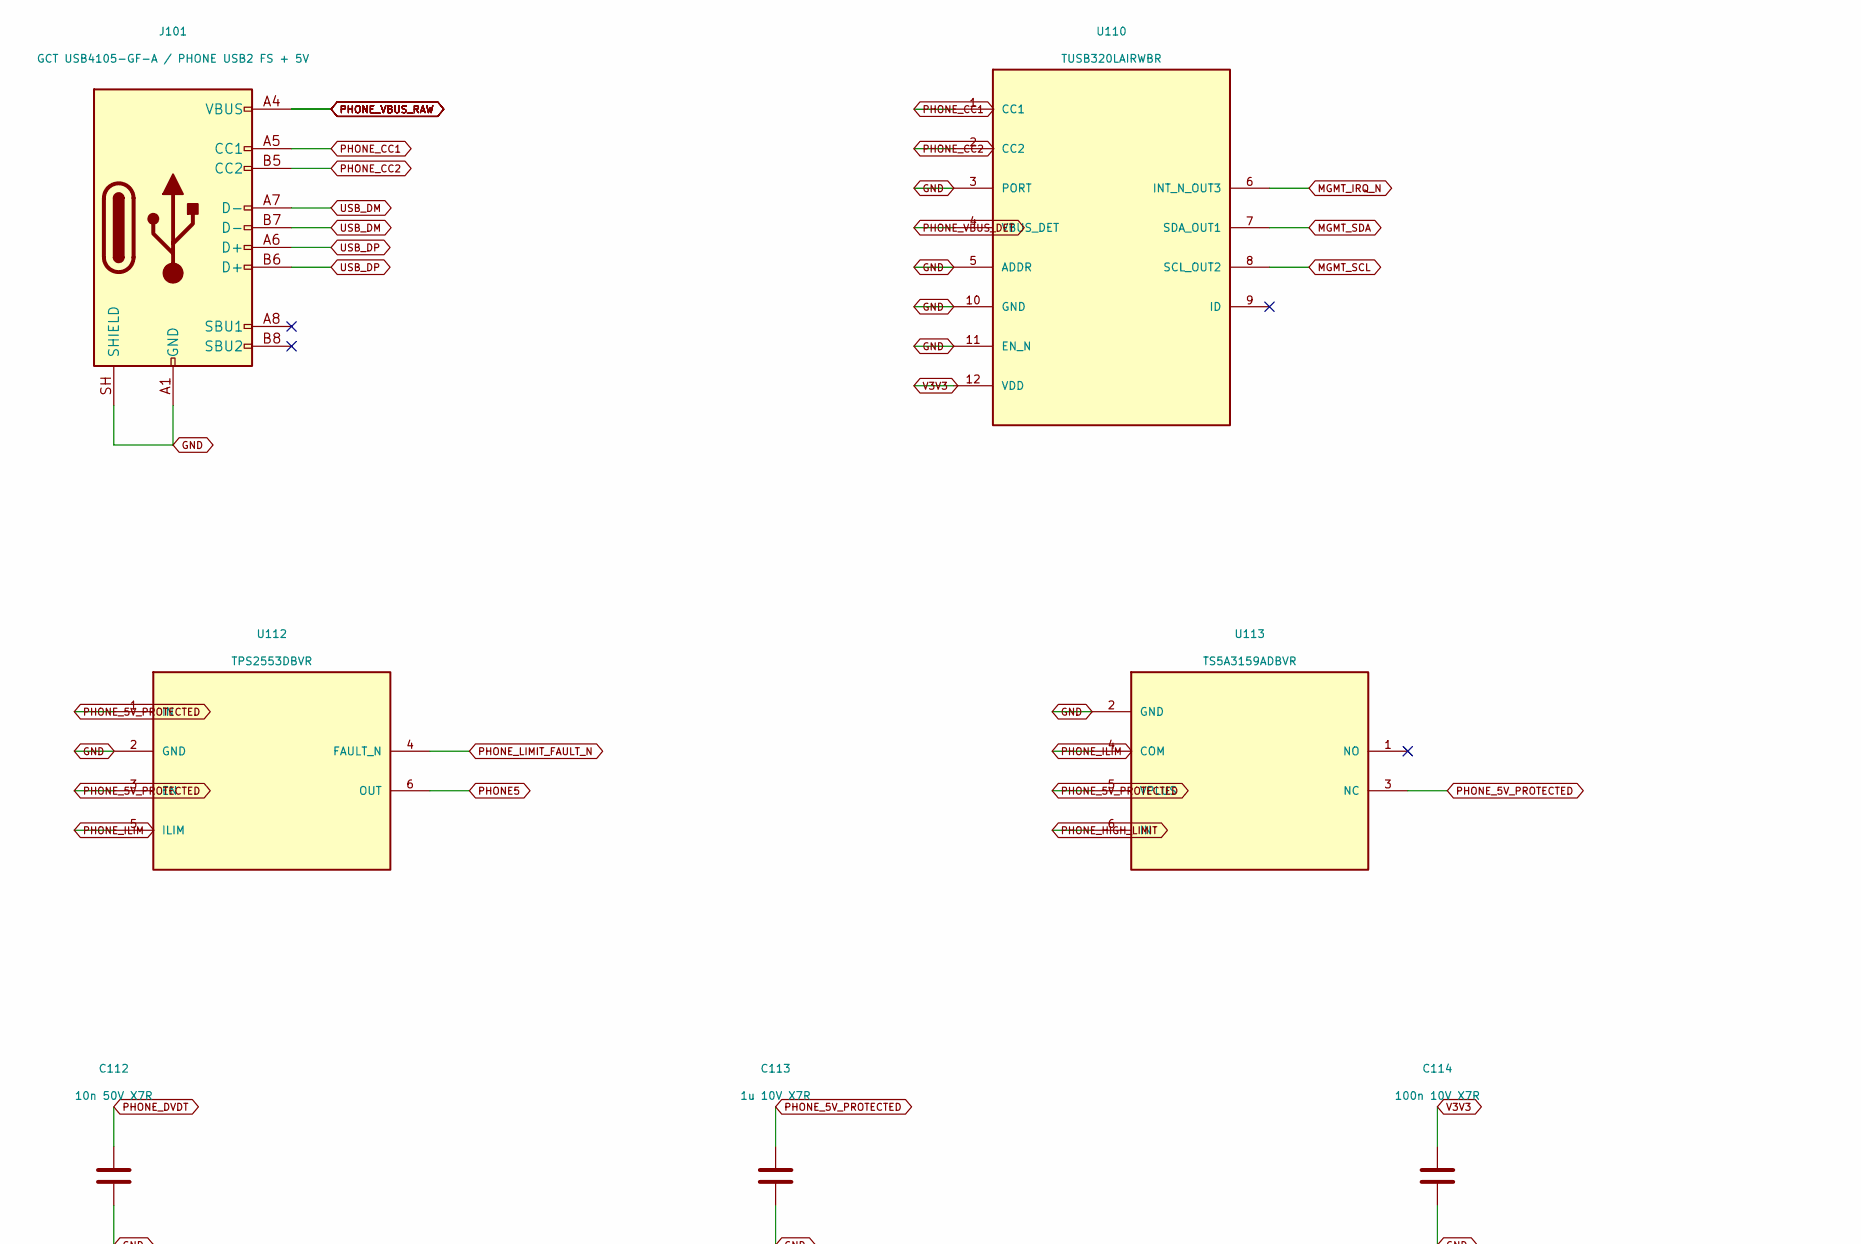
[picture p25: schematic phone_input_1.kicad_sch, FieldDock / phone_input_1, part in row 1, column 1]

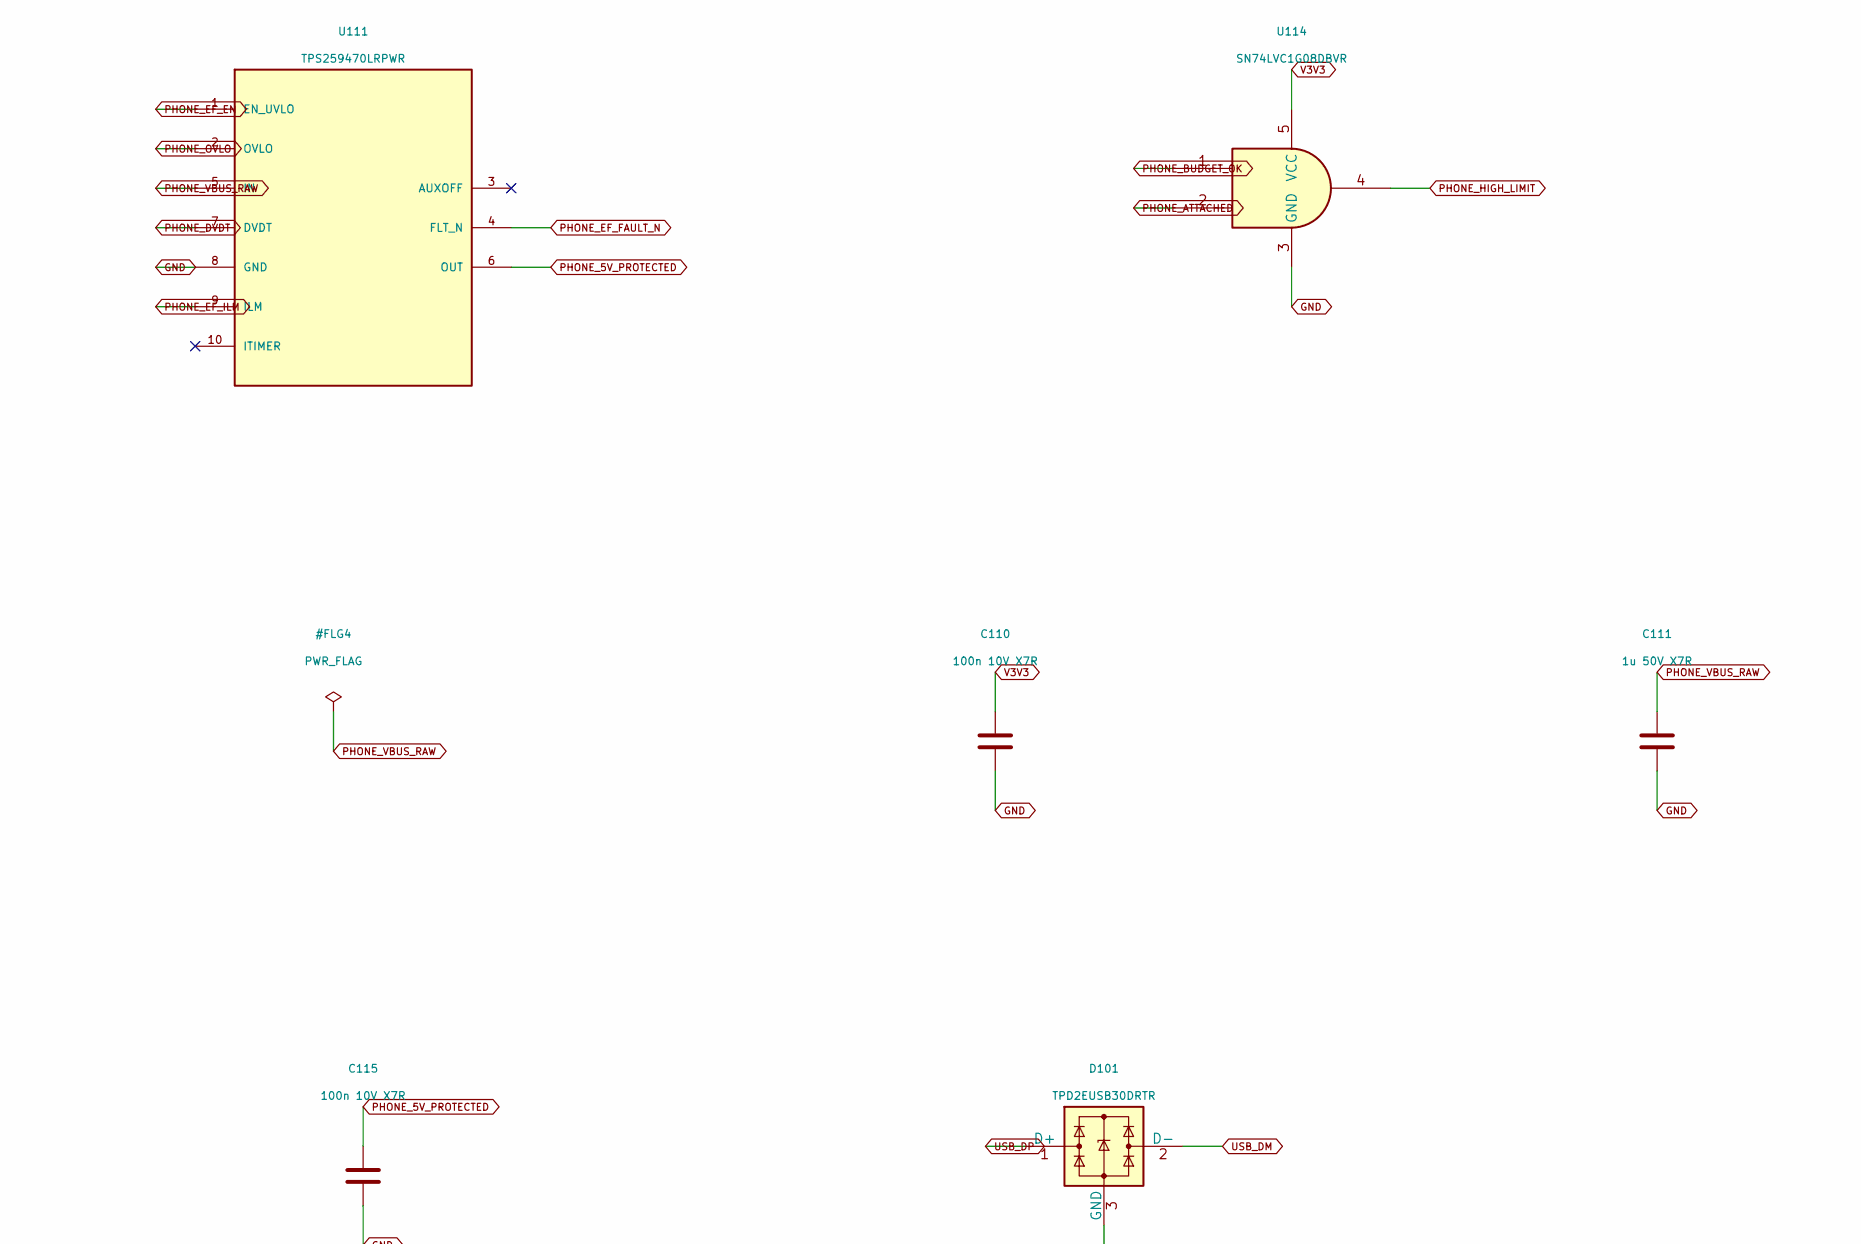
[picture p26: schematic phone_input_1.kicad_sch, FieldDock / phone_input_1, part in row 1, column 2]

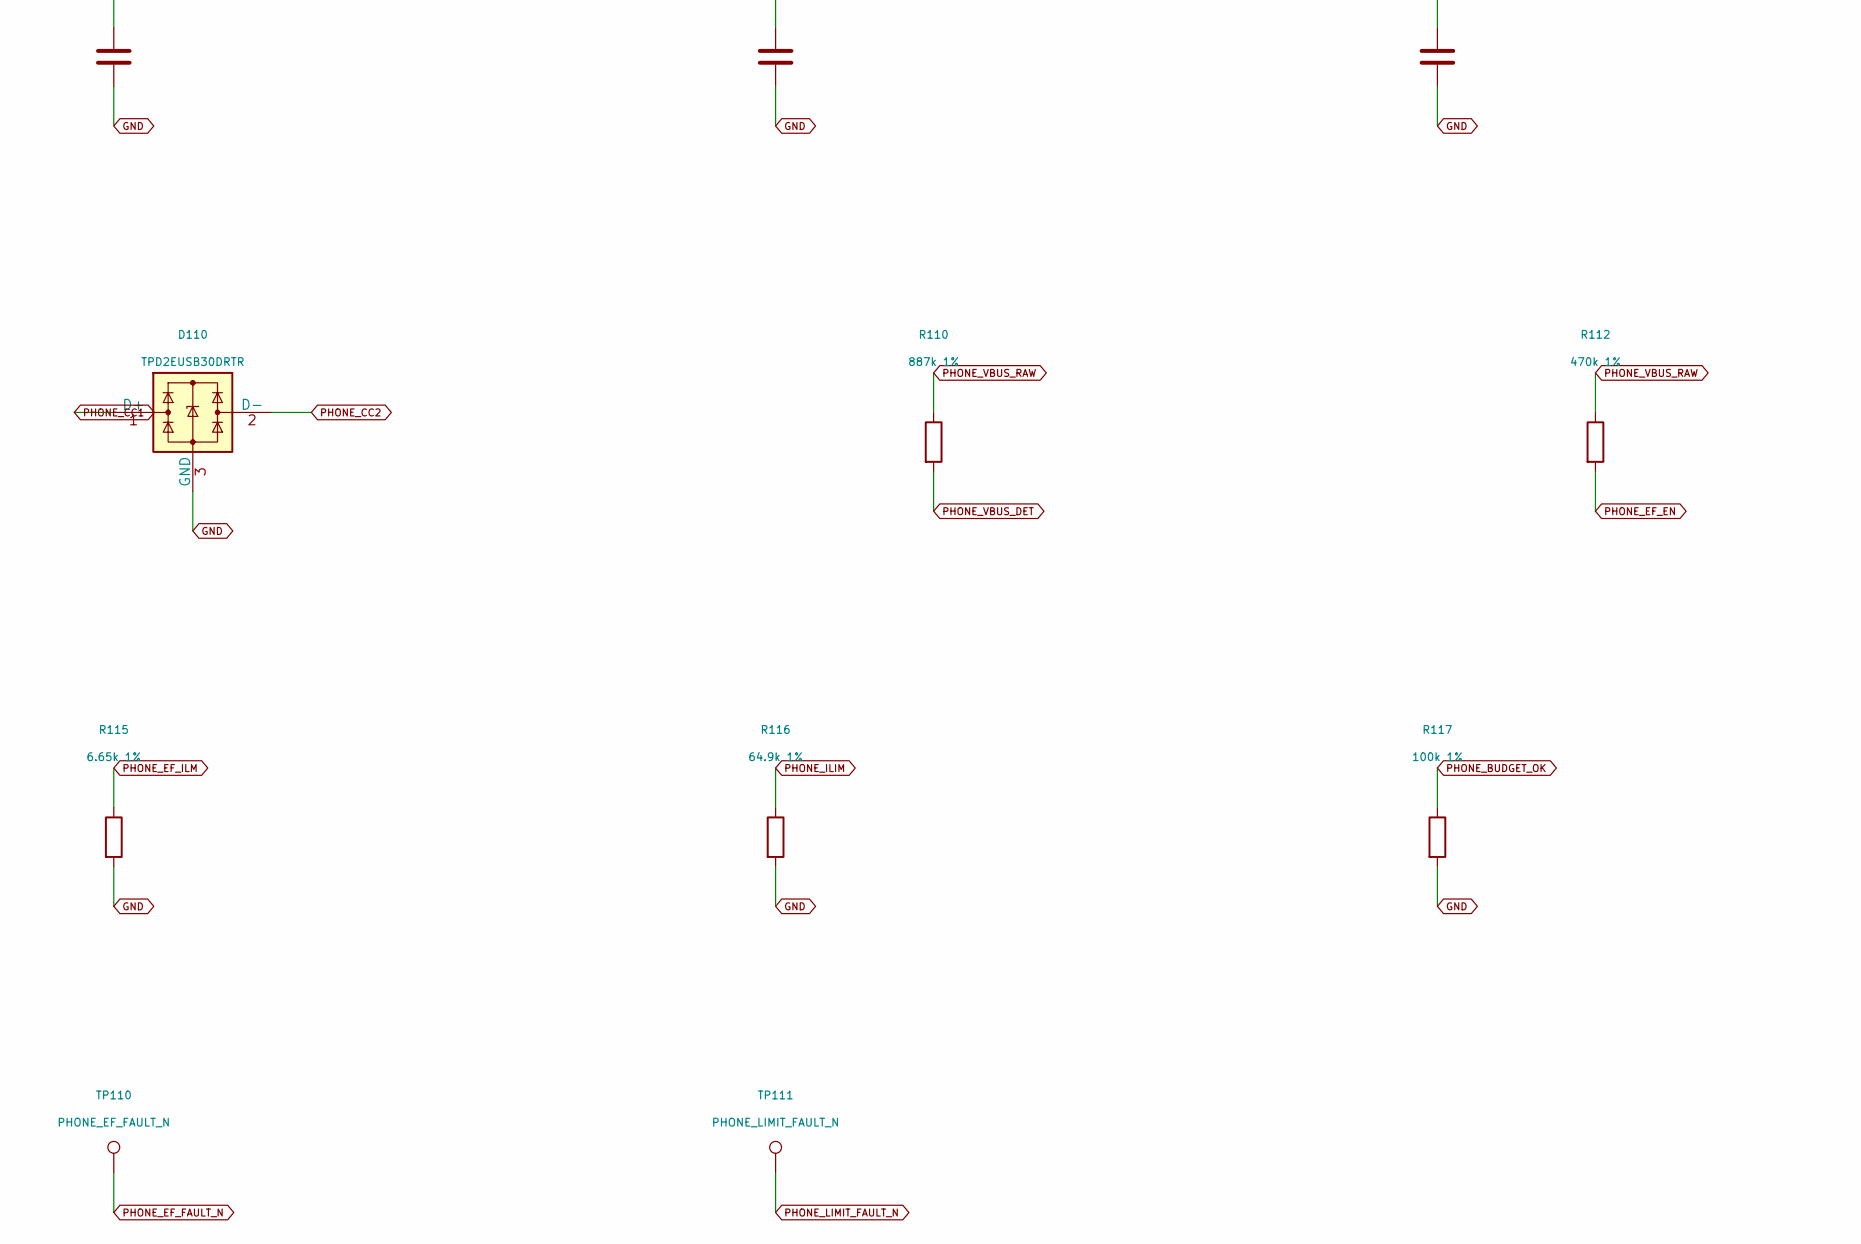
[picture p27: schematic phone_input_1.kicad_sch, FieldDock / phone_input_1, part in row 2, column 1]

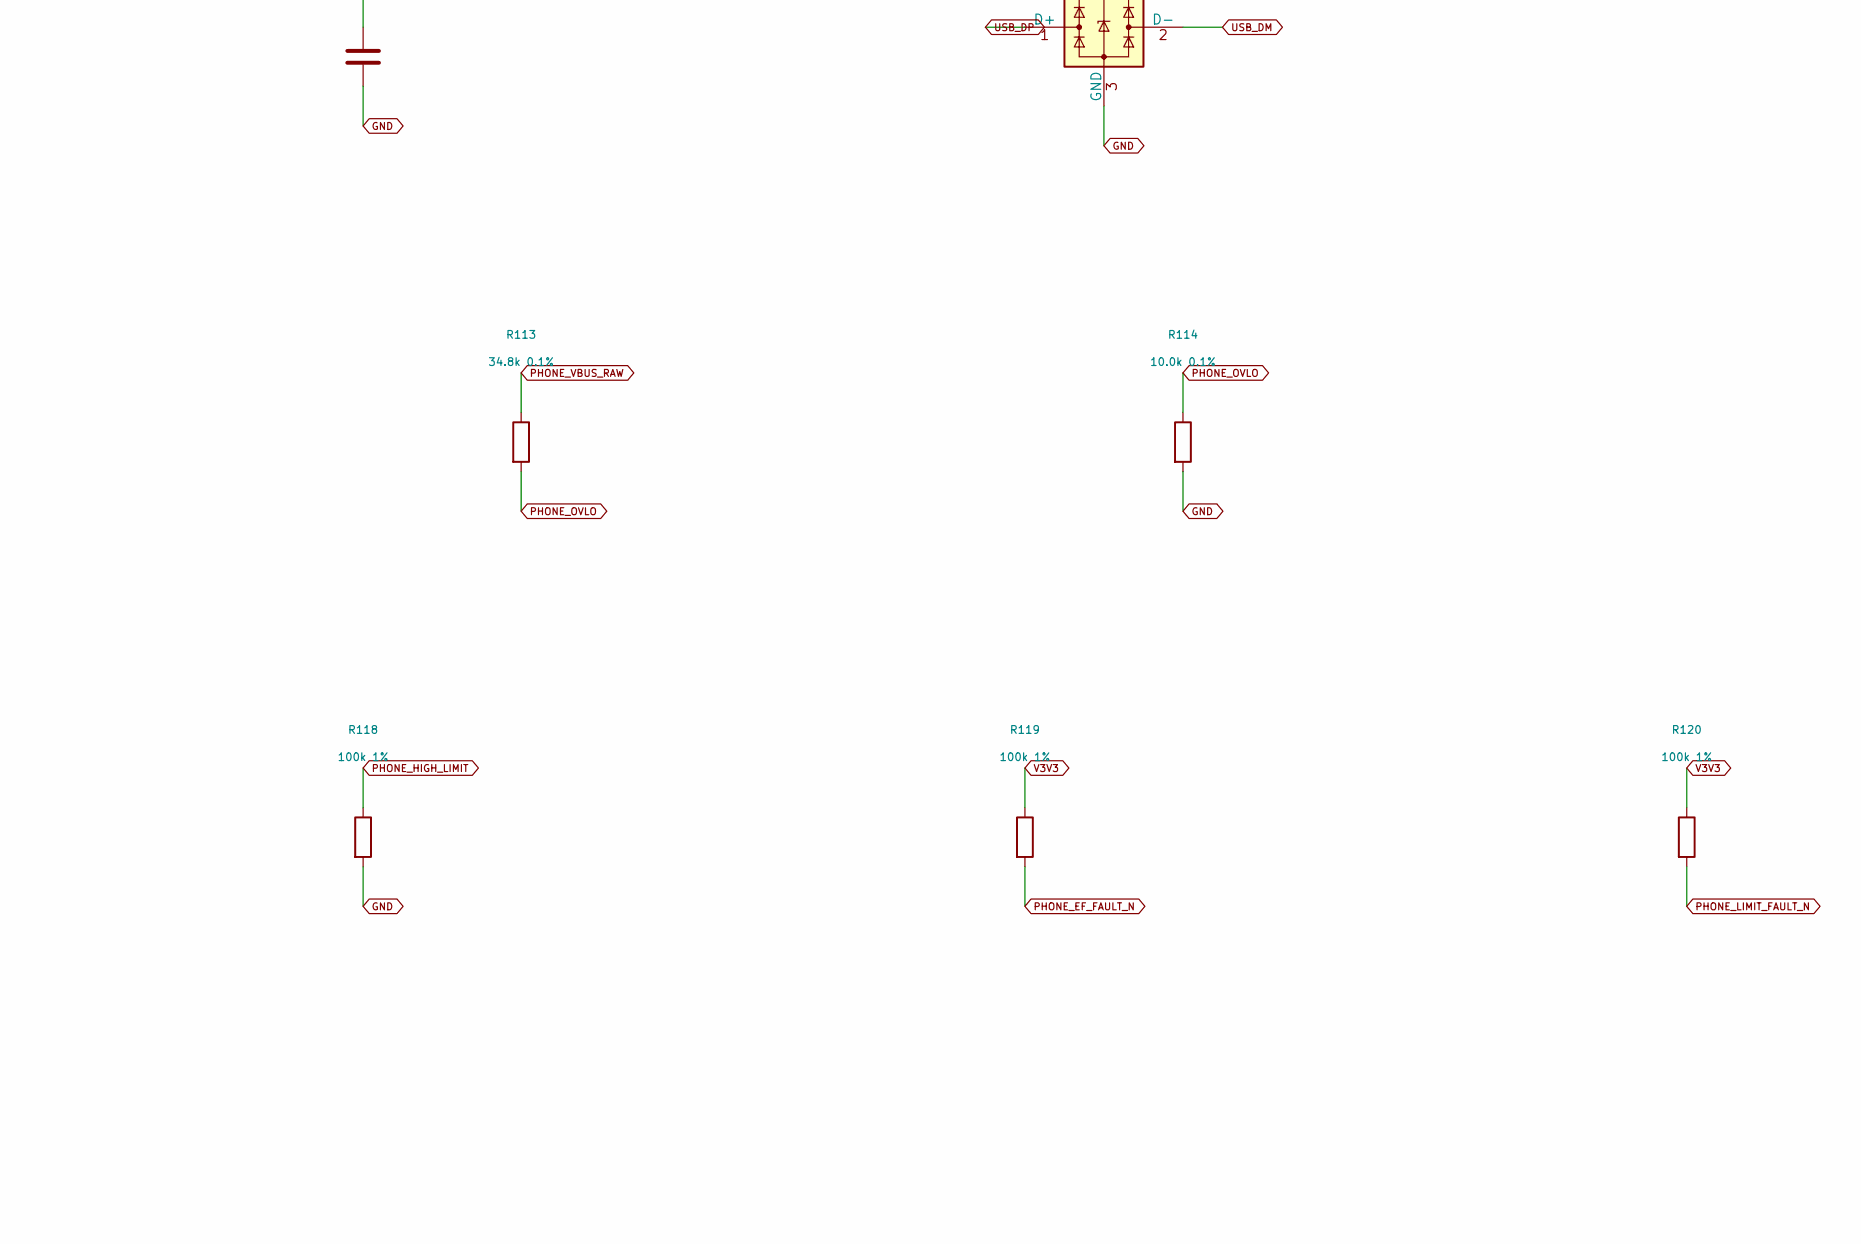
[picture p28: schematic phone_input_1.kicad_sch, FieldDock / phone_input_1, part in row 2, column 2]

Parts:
C110, C114, C115: 100n 10V X7R; C_0603_1608Metric
C111: 1u 50V X7R; C_0805_2012Metric
C112: 10n 50V X7R; C_0603_1608Metric
C113: 1u 10V X7R; C_0603_1608Metric
D101, D110: TPD2EUSB30DRTR; Texas_DRT-3
J101: GCT USB4105-GF-A / PHONE USB2 FS + 5V; USB_C_Receptacle_GCT_USB4105-xx-A_16P_TopMnt_Horizontal
R110: 887k 1%; R_0402_1005Metric
R112: 470k 1%; R_0402_1005Metric
R113: 34.8k 0.1%; R_0402_1005Metric
R114: 10.0k 0.1%; R_0402_1005Metric
R115: 6.65k 1%; R_0402_1005Metric
R116: 64.9k 1%; R_0402_1005Metric
R117, R118, R119, R120: 100k 1%; R_0402_1005Metric
TP110: PHONE_EF_FAULT_N; TestPoint_Pad_D1.0mm
TP111: PHONE_LIMIT_FAULT_N; TestPoint_Pad_D1.0mm
U110: TUSB320LAIRWBR; Texas_X2QFN-12_1.6x1.6mm_P0.4mm
U111: TPS259470LRPWR; Texas_RPW0010A
U112: TPS2553DBVR; SOT-23-6
U113: TS5A3159ADBVR; SOT-23-6
U114: SN74LVC1G08DBVR; SOT-23-5

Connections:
GND: C110.2, C111.2, C112.2, C113.2, C114.2, C115.2, D101.3 (GND), D110.3 (GND), J101.A1 (GND), J101.A12 (GND), J101.B1 (GND), J101.B12 (GND), J101.SH (SHIELD), R114.2, R115.2, R116.2, R117.2, R118.2, U110.3 (PORT), U110.5 (ADDR), U110.10 (GND), U110.11 (EN_N), U111.8 (GND), U112.2 (GND), U113.2 (GND), U114.3 (GND); also elsewhere on the board
MGMT_IRQ_N: U110.6 (INT_N_OUT3); also elsewhere on the board
MGMT_SCL: U110.8 (SCL_OUT2); also elsewhere on the board
MGMT_SDA: U110.7 (SDA_OUT1); also elsewhere on the board
PHONE5: U112.6 (OUT); also elsewhere on the board
PHONE_5V_PROTECTED: C113.1, C115.1, U111.6 (OUT), U112.1 (IN), U112.3 (EN), U113.3 (NC), U113.5 (VPLUS)
PHONE_ATTACHED: U114.2; also elsewhere on the board
PHONE_BUDGET_OK: R117.1, U114.1; also elsewhere on the board
PHONE_CC1: D110.1 (D+), J101.A5 (CC1), U110.1 (CC1)
PHONE_CC2: D110.2 (D-), J101.B5 (CC2), U110.2 (CC2)
PHONE_DVDT: C112.1, U111.7 (DVDT)
PHONE_EF_EN: R112.2, U111.1 (EN_UVLO)
PHONE_EF_FAULT_N: R119.2, TP110.1, U111.4 (FLT_N)
PHONE_EF_ILM: R115.1, U111.9 (ILM)
PHONE_HIGH_LIMIT: R118.1, U113.6 (IN), U114.4
PHONE_ILIM: R116.1, U112.5 (ILIM), U113.4 (COM)
PHONE_LIMIT_FAULT_N: R120.2, TP111.1, U112.4 (FAULT_N)
PHONE_OVLO: R113.2, R114.1, U111.2 (OVLO)
PHONE_VBUS_DET: R110.2, U110.4 (VBUS_DET)
PHONE_VBUS_RAW: C111.1, J101.A4 (VBUS), J101.A9 (VBUS), J101.B4 (VBUS), J101.B9 (VBUS), R110.1, R112.1, R113.1, U111.5 (IN); also elsewhere on the board
USB_DM: D101.2 (D-), J101.A7 (D-), J101.B7 (D-); also elsewhere on the board
USB_DP: D101.1 (D+), J101.A6 (D+), J101.B6 (D+); also elsewhere on the board
V3V3: C110.1, C114.1, R119.1, R120.1, U110.12 (VDD), U114.5 (VCC); also elsewhere on the board





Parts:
C150, C154, C155: 100n 10V X7R; C_0603_1608Metric
C151: 1u 50V X7R; C_0805_2012Metric
C152: 10n 50V X7R; C_0603_1608Metric
C153: 1u 10V X7R; C_0603_1608Metric
D150: TPD2EUSB30DRTR; Texas_DRT-3
J102: GCT USB4105-GF-A / AUX 5V input only; USB_C_Receptacle_GCT_USB4105-xx-A_16P_TopMnt_Horizontal
R150: 887k 1%; R_0402_1005Metric
R151: 4.7k 1%; R_0402_1005Metric
R152: 470k 1%; R_0402_1005Metric
R153: 34.8k 0.1%; R_0402_1005Metric
R154: 10.0k 0.1%; R_0402_1005Metric
R155: 1.65k 1%; R_0402_1005Metric
R156: 34.0k 1%; R_0402_1005Metric
R157, R158, R159, R160: 100k 1%; R_0402_1005Metric
TP150: AUX_EF_FAULT_N; TestPoint_Pad_D1.0mm
TP151: AUX_LIMIT_FAULT_N; TestPoint_Pad_D1.0mm
U150: TUSB320LAIRWBR; Texas_X2QFN-12_1.6x1.6mm_P0.4mm
U151: TPS259470LRPWR; Texas_RPW0010A
U152: TPS2553DBVR; SOT-23-6
U153: TS5A3159ADBVR; SOT-23-6
U154: SN74LVC1G08DBVR; SOT-23-5

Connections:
AUX_5V_PROTECTED: C153.1, C155.1, U151.6 (OUT), U152.1 (IN), U152.3 (EN), U153.3 (NC), U153.5 (VPLUS); also elsewhere on the board
AUX_BUDGET_OK: R157.1, U154.1; also elsewhere on the board
AUX_CC1: D150.1 (D+), J102.A5 (CC1), U150.1 (CC1)
AUX_CC2: D150.2 (D-), J102.B5 (CC2), U150.2 (CC2)
AUX_CC_ADDR: R151.2, U150.5 (ADDR)
AUX_DVDT: C152.1, U151.7 (DVDT)
AUX_EF_EN: R152.2, U151.1 (EN_UVLO)
AUX_EF_FAULT_N: R159.2, TP150.1, U151.4 (FLT_N)
AUX_EF_ILM: R155.1, U151.9 (ILM)
AUX_HIGH_LIMIT: R158.1, U153.6 (IN), U154.4
AUX_ILIM: R156.1, U152.5 (ILIM), U153.4 (COM)
AUX_LIMIT_FAULT_N: R160.2, TP151.1, U152.4 (FAULT_N)
AUX_OVLO: R153.2, R154.1, U151.2 (OVLO)
AUX_VBUS_DET: R150.2, U150.4 (VBUS_DET)
AUX_VBUS_RAW: C151.1, J102.A4 (VBUS), J102.A9 (VBUS), J102.B4 (VBUS), J102.B9 (VBUS), R150.1, R152.1, R153.1, U151.5 (IN); also elsewhere on the board
EXT5: U152.6 (OUT); also elsewhere on the board
EXT_GOOD: U154.2; also elsewhere on the board
GND: C150.2, C151.2, C152.2, C153.2, C154.2, C155.2, D150.3 (GND), J102.A1 (GND), J102.A12 (GND), J102.B1 (GND), J102.B12 (GND), J102.SH (SHIELD), R154.2, R155.2, R156.2, R157.2, R158.2, U150.3 (PORT), U150.10 (GND), U150.11 (EN_N), U151.8 (GND), U152.2 (GND), U153.2 (GND), U154.3 (GND); also elsewhere on the board
MGMT_IRQ_N: U150.6 (INT_N_OUT3); also elsewhere on the board
MGMT_SCL: U150.8 (SCL_OUT2); also elsewhere on the board
MGMT_SDA: U150.7 (SDA_OUT1); also elsewhere on the board
V3V3: C150.1, C154.1, R151.1, R159.1, R160.1, U150.12 (VDD), U154.5 (VCC); also elsewhere on the board

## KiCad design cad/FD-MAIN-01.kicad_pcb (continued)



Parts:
C301: 1u 10V X7R; C_0603_1608Metric
C302: 10u 10V X7R; C_0805_2012Metric
C303, C304, C305: 100n 10V X7R; C_0603_1608Metric
C306: 10n detect filter; C_0603_1608Metric
D301, D302, D303: TPD2EUSB30DRTR; Texas_DRT-3
J301: DM3AT-SF-PEJM5; microSD_HC_Hirose_DM3AT-SF-PEJM5
R301: 100R QOD; R_0603_1608Metric
R302, R314: 100k; R_0603_1608Metric
R303: 22R clock damping; R_0603_1608Metric
R304: 22R command damping; R_0603_1608Metric
R305: 22R MISO damping; R_0603_1608Metric
R306: 10k default isolated; R_0603_1608Metric
R307, R308, R309, R310, R311, R312: 47k; R_0603_1608Metric
R313: 1k detect series; R_0603_1608Metric
U301: TPS22919DCKR; SOT-363_SC-70-6
U302: 74LVC125APW,118 Nexperia; TSSOP-14_4.4x5mm_P0.65mm
U303: SN74LVC1G32DBVR; SOT-23-5

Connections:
GND: C301.2, C302.2, C303.2, C304.2, C305.2, C306.2, D301.3 (GND), D302.3 (GND), D303.3 (GND), J301.6 (VSS), J301.10 (DET_A), J301.SH (SHIELD), R302.2, R312.2, R314.2, U301.2 (GND), U302.7 (GND), U303.3 (GND); also elsewhere on the board
SD_BUS_DISABLE: R306.2, U302.1 (1OE_N), U302.4 (2OE_N), U302.10 (3OE_N), U303.2; also elsewhere on the board
SD_CLK: D301.1 (D+), J301.5 (CLK), R303.2, R312.1
SD_CLK_DRV: R303.1, U302.3 (1Y_SCK)
SD_CMD: D301.2 (D-), J301.3 (CMD), R304.2, R308.2
SD_CMD_DRV: R304.1, U302.6 (2Y_MOSI)
SD_CS_CARD_N: D302.1 (D+), J301.2 (DAT3/CD), R307.2, U302.8 (3Y_CS)
SD_CS_N: U302.9 (3A_CS), U303.1; also elsewhere on the board
SD_DAT0: D302.2 (D-), J301.7 (DAT0), R309.2, U302.12 (4A_CARD_DO)
SD_DAT1: D303.1 (D+), J301.8 (DAT1), R310.2
SD_DAT2: D303.2 (D-), J301.1 (DAT2), R311.2
SD_DETECT_N: C306.1, R313.2; also elsewhere on the board
SD_DETECT_RAW_N: J301.9 (DET_B), R313.1
SD_MISO_DISABLE: U302.13 (4OE_N), U303.4; also elsewhere on the board
SD_MISO_DRV: R305.1, U302.11 (4Y_BUS_MISO)
SD_POWER_EN: R302.1, U301.3 (ON); also elsewhere on the board
SD_QOD: R301.2, U301.5 (QOD)
SD_VDD: C302.1, C303.1, C304.1, J301.4 (VDD), R301.1, R307.1, R308.1, R309.1, R310.1, R311.1, U301.6 (OUT), U302.14 (VCC)
TOOL_MISO: R305.2; also elsewhere on the board
TOOL_MOSI: U302.5 (2A_MOSI); also elsewhere on the board
TOOL_SCK: R314.1, U302.2 (1A_SCK); also elsewhere on the board
V3V3: C301.1, C305.1, R306.1, U301.1 (IN), U303.5 (VCC); also elsewhere on the board


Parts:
R315: 100k; R_0603_1608Metric
R316: 10k; R_0603_1608Metric

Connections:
GND: R315.2; also elsewhere on the board
SD_MISO_DISABLE: R316.2; also elsewhere on the board
TOOL_MOSI: R315.1; also elsewhere on the board
V3V3: R316.1; also elsewhere on the board

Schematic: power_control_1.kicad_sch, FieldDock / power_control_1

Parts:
C180: 1u 10V X7R; C_0603_1608Metric
C181: 10u 10V X7R; C_0805_2012Metric
C190, C194: 1n 50V C0G; C_0603_1608Metric
C191, C192, C195, C196, C197: 100n 10V X7R; C_0603_1608Metric
R180: 34.0k 1%; R_0402_1005Metric
R181, R197, R198, R199: 100k 1%; R_0402_1005Metric
R182: 1k 1%; R_0402_1005Metric
R190, R194: 324k 1%; R_0402_1005Metric
R191, R195: 33.2k 1%; R_0402_1005Metric
R192, R193, R196: 10k 1%; R_0402_1005Metric
U190: TPS3700DDCR; SOT-23-6
U191: SN74LVC1G04DBVR; SOT-23-5
U192, U193, U194: SN74LVC1G08DBVR; SOT-23-5
U195: TPS2553DBVR; SOT-23-6

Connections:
AUX_5V_PROTECTED: C180.1, U195.1 (IN); also elsewhere on the board
AUX_PROBE_ALLOWED: U192.4, U194.1
AUX_PROBE_BUDGET_OK: R197.1, U192.2; also elsewhere on the board
AUX_VBUS_RAW: R194.1; also elsewhere on the board
AUX_VGOOD_N: R193.2, U190.6 (OUTB), U191.2
AUX_VSENSE: C194.1, R194.2, R195.1, U190.4 (INB_N)
EXT_FAULT_N: R181.2, U195.4 (FAULT_N)
EXT_GOOD: U191.4, U192.1; also elsewhere on the board
EXT_ILIM: R180.1, U195.5 (ILIM)
EXT_LOAD_ENABLE: R199.1, U194.4, U195.3 (EN); also elsewhere on the board
EXT_PROBE5: C181.1, R182.1, U195.6 (OUT); also elsewhere on the board
EXT_REQUEST: R198.1, U193.2; also elsewhere on the board
GND: C180.2, C181.2, C190.2, C191.2, C192.2, C194.2, C195.2, C196.2, C197.2, R180.2, R182.2, R191.2, R195.2, R197.2, R198.2, R199.2, U190.2 (GND), U191.3 (GND), U192.3 (GND), U193.3 (GND), U194.3 (GND), U195.2 (GND); also elsewhere on the board
MGMT_IRQ_N: R196.2; also elsewhere on the board
PHONE_ATTACHED: R192.2, U190.1 (OUTA); also elsewhere on the board
PHONE_VBUS_RAW: R190.1; also elsewhere on the board
PHONE_VSENSE: C190.1, R190.2, R191.1, U190.3 (INA_P)
PROBE_REQUEST_ALLOWED: U193.4, U194.2
TOOLS_ENABLE: U193.1; also elsewhere on the board
V3V3: C191.1, C192.1, C195.1, C196.1, C197.1, R181.1, R192.1, R193.1, R196.1, U190.5 (VDD), U191.5 (VCC), U192.5 (VCC), U193.5 (VCC), U194.5 (VCC); also elsewhere on the board

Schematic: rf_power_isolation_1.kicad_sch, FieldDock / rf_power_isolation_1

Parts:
C400: 1u 10V X7R; C_0603_1608Metric
C401: 4.7u 10V X7R; C_0603_1608Metric
C402, C403, C404: 100n 10V X7R; C_0402_1005Metric
R400: 100R; R_0402_1005Metric
R401, R403, R406, R407, R408, R409, R410: 100k; R_0402_1005Metric
R402: 10k; R_0402_1005Metric
R404, R405: 47k; R_0402_1005Metric
U400: TPS22919DCKR; SOT-363_SC-70-6
U401: SN74LVC1G08DBVR; SOT-23-5
U402: SN74LVC1G04DBVR; SOT-23-5
U403: SN74CB3T3245PWR; TSSOP-20_4.4x6.5mm_P0.65mm

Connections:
GND: C400.2, C401.2, C402.2, C403.2, C404.2, R401.2, R403.2, R406.2, R407.2, R408.2, R409.2, R410.2, U400.2 (GND), U401.3 (GND), U402.3 (GND), U403.10 (GND); also elsewhere on the board
NFC_CS_N: U403.6 (A5); also elsewhere on the board
NFC_IRQ: R409.1, U403.8 (A7); also elsewhere on the board
RF_NFC_CS_N: R405.2, U403.14 (B5); also elsewhere on the board
RF_NFC_IRQ: U403.12 (B7); also elsewhere on the board
RF_QOD: R400.2, U400.5 (QOD)
RF_SUB_CS_N: R404.2, U403.15 (B4); also elsewhere on the board
RF_SUB_GDO0: U403.13 (B6); also elsewhere on the board
RF_SUB_RF_SELECT: R408.1, U403.11 (B8); also elsewhere on the board
RF_TOOL_MISO: U403.16 (B3); also elsewhere on the board
RF_TOOL_MOSI: R407.1, U403.17 (B2); also elsewhere on the board
RF_TOOL_SCK: R406.1, U403.18 (B1); also elsewhere on the board
SUB_CS_N: U403.5 (A4); also elsewhere on the board
SUB_GDO0: R410.1, U403.7 (A6); also elsewhere on the board
SUB_RF_SELECT: U403.9 (A8); also elsewhere on the board
TOOLS_BUS_DISABLE: R402.2, U402.4, U403.19 (OE_N); also elsewhere on the board
TOOLS_ENABLE: U400.3 (ON), U401.1; also elsewhere on the board
TOOLS_IO_ARM: R401.1, U401.2; also elsewhere on the board
TOOLS_IO_ENABLED: R403.1, U401.4, U402.2; also elsewhere on the board
TOOL_MISO: U403.4 (A3); also elsewhere on the board
TOOL_MOSI: U403.3 (A2); also elsewhere on the board
TOOL_SCK: U403.2 (A1); also elsewhere on the board
V3V3: C400.1, C402.1, C403.1, C404.1, R402.1, U400.1 (IN), U401.5 (VCC), U402.5 (VCC), U403.20 (VCC); also elsewhere on the board
V3V3_RF: C401.1, R400.1, R404.1, R405.1, U400.6 (OUT); also elsewhere on the board

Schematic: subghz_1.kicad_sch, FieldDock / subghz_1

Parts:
C430, C431: 9p C0G 50V initial CL trim; C_0402_1005Metric
C432, C433, C434, C435, C436, C437, C438: 100n 10V X7R; C_0402_1005Metric
C439: 2.2u 10V X7R; C_0603_1608Metric
C440, C441: 100p C0G 50V; C_0402_1005Metric
C442: 1.2p C0G 0.1p 50V; C_0402_1005Metric
C443, C444, C445: DNP C0G matching trim; C_0402_1005Metric
C446, C447: 10n 10V X7R; C_0402_1005Metric
C450, C451: 12p C0G 2% 50V; C_0402_1005Metric
C452, C453: 8.2p C0G 2% 50V; C_0402_1005Metric
C454, C455: 4.3p C0G 2% 50V; C_0402_1005Metric
J430: U.FL-R-SMT-1(10) / 50R antenna; U.FL_Hirose_U.FL-R-SMT-1_Vertical
U430: CC1101RGPT; Texas_RGP0020H_VQFN-20-1EP_4x4mm_P0.5mm_EP2.4x2.4mm
U431, U432: BGS13S4N9E6327XTSA1; Infineon_TSNP9_1.1x1.1_P0.4

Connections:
GND: C430.2, C431.2, C432.2, C433.2, C434.2, C435.2, C436.2, C437.2, C438.2, C439.2, C442.2, C443.2, C444.2, C445.2, C446.2, C447.2, C450.2, C451.2, C452.2, C453.2, C454.2, C455.2, J430.2 (Ext), U430.16 (GND1), U430.18 (DGUARD), U430.19 (GND2), U430.21 (EP_GND), U431.6 (DGND), U431.9 (GND), U432.6 (DGND), U432.9 (GND); also elsewhere on the board
RF_SUB_CS_N: U430.7 (CS_N); also elsewhere on the board
RF_SUB_GDO0: U430.6 (GDO0); also elsewhere on the board
RF_SUB_RF_SELECT: U431.1 (V1), U432.1 (V1); also elsewhere on the board
RF_TOOL_MISO: U430.2 (SO_GDO1); also elsewhere on the board
RF_TOOL_MOSI: U430.20 (SI); also elsewhere on the board
RF_TOOL_SCK: U430.1 (SCLK); also elsewhere on the board
SUB_ANT: J430.1 (In); also elsewhere on the board
SUB_BAL_A: C440.2; also elsewhere on the board
SUB_BAL_B: C441.2; also elsewhere on the board
SUB_DCOUPL: C432.1, U430.5 (DCOUPL)
SUB_FILTER_IN: C445.1, U431.4 (RFIN); also elsewhere on the board
SUB_FILTER_OUT: U432.4 (RFIN); also elsewhere on the board
SUB_F_IN_315: U431.3 (RF1); also elsewhere on the board
SUB_F_IN_433: U431.5 (RF2); also elsewhere on the board
SUB_F_IN_900: U431.2 (RF3); also elsewhere on the board
SUB_F_M1_315: C450.1; also elsewhere on the board
SUB_F_M1_433: C452.1; also elsewhere on the board
SUB_F_M1_900: C454.1; also elsewhere on the board
SUB_F_M2_315: C451.1; also elsewhere on the board
SUB_F_M2_433: C453.1; also elsewhere on the board
SUB_F_M2_900: C455.1; also elsewhere on the board
SUB_F_OUT_315: U432.3 (RF1); also elsewhere on the board
SUB_F_OUT_433: U432.5 (RF2); also elsewhere on the board
SUB_F_OUT_900: U432.2 (RF3); also elsewhere on the board
SUB_MATCH: C442.1; also elsewhere on the board
SUB_RBIAS: U430.17 (RBIAS); also elsewhere on the board
SUB_RFN: C440.1, C444.1, U430.13 (RF_N)
SUB_RFP: C441.1, C443.1, U430.12 (RF_P)
SUB_SWITCH_V2: U430.3 (GDO2), U431.8 (V2), U432.8 (V2); also elsewhere on the board
SUB_X1: C430.1, U430.8 (XOSC_Q1); also elsewhere on the board
SUB_X2: C431.1, U430.10 (XOSC_Q2); also elsewhere on the board
V3V3_RF: C433.1, C434.1, C435.1, C436.1, C437.1, C438.1, C439.1, C446.1, C447.1, U430.4 (DVDD), U430.9 (AVDD1), U430.11 (AVDD2), U430.14 (AVDD3), U430.15 (AVDD4), U431.7 (VDD), U432.7 (VDD); also elsewhere on the board

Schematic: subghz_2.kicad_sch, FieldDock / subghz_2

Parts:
L430: 3.3nH 0.2nH RF; L_0402_1005Metric
L431: 6.8nH 0.2nH RF; L_0402_1005Metric
L440, L442: 12nH 5% RF; L_0402_1005Metric
L441: 39nH 5% RF; L_0402_1005Metric
L443, L445: 8.2nH 5% RF; L_0402_1005Metric
L444: 27nH 5% RF; L_0402_1005Metric
L446, L448: 4.3nH 5% RF; L_0402_1005Metric
L447: 13nH 5% RF; L_0402_1005Metric
R430: 56k 1%; R_0402_1005Metric
R431: 100k; R_0402_1005Metric
R432: 0R antenna matching link; R_0402_1005Metric
T430: B0310J50100AHF; TTM_B0310J50100AHF
Y430: XRCGB26M000F3M00R0 26MHz CL6pF; Murata_XRCGB_2016

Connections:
GND: R430.2, R431.2, T430.2 (GND); also elsewhere on the board
SUB_ANT: R432.2; also elsewhere on the board
SUB_BAL_A: T430.3 (BAL_100R_A); also elsewhere on the board
SUB_BAL_B: T430.4 (BAL_100R_B); also elsewhere on the board
SUB_FILTER_IN: L431.2; also elsewhere on the board
SUB_FILTER_OUT: R432.1; also elsewhere on the board
SUB_F_IN_315: L440.1; also elsewhere on the board
SUB_F_IN_433: L443.1; also elsewhere on the board
SUB_F_IN_900: L446.1; also elsewhere on the board
SUB_F_M1_315: L440.2, L441.1; also elsewhere on the board
SUB_F_M1_433: L443.2, L444.1; also elsewhere on the board
SUB_F_M1_900: L446.2, L447.1; also elsewhere on the board
SUB_F_M2_315: L441.2, L442.1; also elsewhere on the board
SUB_F_M2_433: L444.2, L445.1; also elsewhere on the board
SUB_F_M2_900: L447.2, L448.1; also elsewhere on the board
SUB_F_OUT_315: L442.2; also elsewhere on the board
SUB_F_OUT_433: L445.2; also elsewhere on the board
SUB_F_OUT_900: L448.2; also elsewhere on the board
SUB_MATCH: L430.2, L431.1; also elsewhere on the board
SUB_RBIAS: R430.1; also elsewhere on the board
SUB_SWITCH_V2: R431.1; also elsewhere on the board
SUB_UNBAL: L430.1, T430.1 (UNBAL_50R)
SUB_X1: Y430.1 (XTAL_1); also elsewhere on the board
SUB_X2: Y430.3 (XTAL_3); also elsewhere on the board

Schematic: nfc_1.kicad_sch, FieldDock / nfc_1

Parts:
C500, C501: 6p C0G 50V; C_0402_1005Metric
C502, C504, C506, C508, C510, C513: 10n 10V X7R; C_0402_1005Metric
C503, C505, C507, C509, C511: 2.2u 10V X7R; C_0603_1608Metric
C512: 1u 10V X7R; C_0603_1608Metric
C520, C525: 680p C0G 50V; C_0603_1608Metric
C521, C526: 100p C0G 100V; C_0603_1608Metric
C522, C527: 62p C0G 100V; C_0603_1608Metric
C523, C528: 10p C0G 100V; C_0603_1608Metric
C524, C529: 100p C0G 50V; C_0603_1608Metric
C530, C531: DNP C0G trim; C_0603_1608Metric
J500: NFC antenna 1.37uH nominal / soldered twisted pair; Antenna_2Pad_2mm
L500: 270nH 5% RF wirewound; L_0603_1608Metric
U500: ST25R3916-AQWT; ST_VFQFPN32_5x5_EP3.5

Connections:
GND: C500.2, C501.2, C502.2, C503.2, C504.2, C505.2, C506.2, C507.2, C508.2, C509.2, C510.2, C511.2, C512.2, C513.2, C520.2, C522.2, C524.2, C525.2, C527.2, C529.2, U500.6 (GND_D), U500.12 (GND_DR1), U500.16 (GND_DR2), U500.20 (I2C_EN), U500.21 (VSS), U500.26 (GND_A), U500.33 (EP_GND); also elsewhere on the board
NFC_AGDC: C512.1, C513.1, U500.24 (AGDC)
NFC_ANT_N: C526.2, C527.1, C528.1, C531.2; also elsewhere on the board
NFC_ANT_P: C521.2, C522.1, C523.1, C530.2; also elsewhere on the board
NFC_COIL_N: J500.2; also elsewhere on the board
NFC_COIL_P: J500.1; also elsewhere on the board
NFC_FILTER_N: C525.1, C526.1, C531.1; also elsewhere on the board
NFC_FILTER_P: C520.1, C521.1, C530.1, L500.2
NFC_RFI1: C523.2, C524.1, U500.22 (RFI1)
NFC_RFI2: C528.2, C529.1, U500.23 (RFI2)
NFC_RFO1: L500.1, U500.13 (RFO1)
NFC_RFO2: U500.15 (RFO2); also elsewhere on the board
NFC_VDD_A: C506.1, C507.1, U500.7 (VDD_A)
NFC_VDD_AM: C510.1, C511.1, U500.11 (VDD_AM)
NFC_VDD_D: C504.1, C505.1, U500.3 (VDD_D)
NFC_VDD_RF: C508.1, C509.1, U500.9 (VDD_RF), U500.14 (VDD_DR)
NFC_XTI: C501.1, U500.5 (XTI); also elsewhere on the board
NFC_XTO: C500.1, U500.4 (XTO); also elsewhere on the board
RF_NFC_CS_N: U500.29 (BSS_N); also elsewhere on the board
RF_NFC_IRQ: U500.27 (IRQ); also elsewhere on the board
RF_TOOL_MISO: U500.32 (MISO); also elsewhere on the board
RF_TOOL_MOSI: U500.31 (MOSI); also elsewhere on the board
RF_TOOL_SCK: U500.30 (SCLK); also elsewhere on the board
V3V3_RF: C502.1, C503.1, U500.1 (VDD_IO), U500.8 (VDD), U500.10 (VDD_TX); also elsewhere on the board

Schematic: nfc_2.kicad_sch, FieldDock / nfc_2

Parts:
L501: 270nH 5% RF wirewound; L_0603_1608Metric
R500, R501: 0R antenna tuning link; R_0603_1608Metric
Y500: XRCGB27M120F3M00R0 27.12MHz CL6pF; Murata_XRCGB_2016

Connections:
NFC_ANT_N: R501.1; also elsewhere on the board
NFC_ANT_P: R500.1; also elsewhere on the board
NFC_COIL_N: R501.2; also elsewhere on the board
NFC_COIL_P: R500.2; also elsewhere on the board
NFC_FILTER_N: L501.2; also elsewhere on the board
NFC_RFO2: L501.1; also elsewhere on the board
NFC_XTI: Y500.3 (XTAL_3); also elsewhere on the board
NFC_XTO: Y500.1 (XTAL_1); also elsewhere on the board

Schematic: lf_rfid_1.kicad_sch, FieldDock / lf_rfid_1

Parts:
C600, C610, C611: 1u 10V X7R; C_0603_1608Metric
C601: 4.7u 10V X7R; C_0603_1608Metric
C602, C603, C609, C612, C613, C625: 100n 10V X7R; C_0402_1005Metric
C604: 3.3n C0G 100V; C_0805_2012Metric
C605: DNP C0G 100V trim; C_0805_2012Metric
C606: 10n X7R 100V; C_0603_1608Metric
C607: 1n C0G 100V; C_0603_1608Metric
C608: 220n X7R 100V; C_0805_2012Metric
C620, C622: 4.7n C0G 50V; C_0402_1005Metric
C621, C623, C624: 100p C0G 50V; C_0402_1005Metric
D600: 1N4148W-7-F; D_SOD-123
D601: MM3Z33VT1G 33V; D_SOD-323
D602: BAT54S,215; SOT-23
J600: LF coil ~500uH / soldered twisted pair; Antenna_2Pad_2mm
U600, U601, U603: SN74LVC1G08DBVR; SOT-23-5
U602: TPS22919DCKR; SOT-363_SC-70-6
U604, U605: LMV358AIDGKR; VSSOP-8_3x3mm_P0.65mm
U606: LMV331IDCKR; SOT-353_SC-70-5

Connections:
CORE5: C600.1, U602.1 (IN); also elsewhere on the board
GND: C600.2, C601.2, C602.2, C603.2, C604.2, C605.2, C606.2, C607.2, C609.2, C610.2, C611.2, C612.2, C613.2, C620.2, C622.2, C624.2, C625.2, D601.2 (A), D602.1 (A), U600.3 (GND), U601.3 (GND), U602.2 (GND), U603.3 (GND), U604.4 (GND), U605.4 (GND), U606.2 (GND), U606.3 (IN_N); also elsewhere on the board
LF5: C601.1, U602.6 (OUT); also elsewhere on the board
LF_AC: C608.2, D602.3 (COM), U604.3 (IN_A_P); also elsewhere on the board
LF_ANALOG: C624.1; also elsewhere on the board
LF_AR1: J600.1; also elsewhere on the board
LF_AR2: C604.1, C605.1, D600.2 (A), J600.2; also elsewhere on the board
LF_AVDD: C610.1, C612.1, C613.1, C625.1, D602.2 (K), U604.8 (VCC), U605.8 (VCC), U606.5 (VCC); also elsewhere on the board
LF_CARRIER: U601.1; also elsewhere on the board
LF_CARRIER_SENSE: U606.1 (IN_P); also elsewhere on the board
LF_DRIVE_GATED: U601.4; also elsewhere on the board
LF_EDGE: U606.4 (OUT); also elsewhere on the board
LF_ENV: C607.1, C608.1; also elsewhere on the board
LF_F1_NEG: C621.1, U605.2 (IN_A_N); also elsewhere on the board
LF_F1_NODE: C620.1; also elsewhere on the board
LF_F2_NEG: C623.1, U605.6 (IN_B_N); also elsewhere on the board
LF_F2_NODE: C622.1; also elsewhere on the board
LF_FB1: U604.2 (IN_A_N); also elsewhere on the board
LF_FILTER1: C621.2, U605.1 (OUT_A); also elsewhere on the board
LF_FILTER2: C623.2, U605.7 (OUT_B); also elsewhere on the board
LF_GAIN1: U604.1 (OUT_A); also elsewhere on the board
LF_LOAD: U603.1; also elsewhere on the board
LF_LOAD_GATED: U603.4; also elsewhere on the board
LF_MID: U604.6 (IN_B_N), U604.7 (OUT_B), U605.3 (IN_A_P), U605.5 (IN_B_P); also elsewhere on the board
LF_MID_DIV: C611.1, U604.5 (IN_B_P); also elsewhere on the board
LF_POWER_ON: U600.4, U601.2, U602.3 (ON); also elsewhere on the board
LF_QOD: U602.5 (QOD); also elsewhere on the board
LF_RECT: C606.1, D600.1 (K), D601.1 (K); also elsewhere on the board
LF_REQUEST: U600.2; also elsewhere on the board
TOOLS_IO_ENABLED: U600.1, U603.2; also elsewhere on the board
V3V3: C602.1, C603.1, C609.1, U600.5 (VCC), U601.5 (VCC), U603.5 (VCC); also elsewhere on the board

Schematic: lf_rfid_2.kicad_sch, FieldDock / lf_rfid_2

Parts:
D603: BAT54S,215; SOT-23
Q600: DMP2004K-7; SOT-23
Q601, Q602: DMN2004K-7; SOT-23
Q603: DMN5L06TK-7; SOT-523
R600: 100R; R_0402_1005Metric
R601, R602, R611: 100k; R_0402_1005Metric
R603, R604: 4.7R 1% 0.25W; R_0805_2012Metric
R605: 510R 1%; R_0402_1005Metric
R606: 51R; R_0402_1005Metric
R607, R629: 10k; R_0402_1005Metric
R608, R628: 330k 1%; R_0402_1005Metric
R609: 5.1k; R_0402_1005Metric
R610: 440R; R_0402_1005Metric
R612: 330R 0.25W; R_0805_2012Metric
R613: 10R; R_0402_1005Metric
R614, R615, R626: 33k 1%; R_0402_1005Metric
R616: 1M 1%; R_0402_1005Metric
R617, R620, R621, R623, R624: 1k 1%; R_0402_1005Metric
R618: 4.7k 1%; R_0402_1005Metric
R622, R625: 10k 1%; R_0402_1005Metric
R627: 20k 1%; R_0402_1005Metric

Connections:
GND: D603.1 (A), Q601.2 (S), Q602.2 (S), Q603.2 (S), R601.2, R602.2, R607.2, R608.2, R611.2, R615.2, R627.2; also elsewhere on the board
LF5: Q600.2 (S), R600.1, R605.1; also elsewhere on the board
LF_AC: R616.1; also elsewhere on the board
LF_ANALOG: R626.2, R627.1; also elsewhere on the board
LF_AR1: R603.2, R604.2; also elsewhere on the board
LF_AR2: R628.1; also elsewhere on the board
LF_AVDD: D603.2 (K), R613.2, R614.1; also elsewhere on the board
LF_CARRIER_SENSE: D603.3 (COM), R628.2; also elsewhere on the board
LF_DRIVER_GATE: Q600.1 (G), Q601.1 (G), Q602.3 (D), R605.2
LF_DRIVE_GATED: R606.1; also elsewhere on the board
LF_EDGE: R629.2; also elsewhere on the board
LF_ENV: R609.2; also elsewhere on the board
LF_F1_NEG: R621.2; also elsewhere on the board
LF_F1_NODE: R620.2, R621.1, R622.1; also elsewhere on the board
LF_F2_NEG: R624.2; also elsewhere on the board
LF_F2_NODE: R623.2, R624.1, R625.1; also elsewhere on the board
LF_FB1: R617.1, R618.1; also elsewhere on the board
LF_FILTER1: R622.2, R623.1; also elsewhere on the board
LF_FILTER2: R625.2, R626.1; also elsewhere on the board
LF_GAIN1: R618.2, R620.1; also elsewhere on the board
LF_LEVEL_GATE: Q602.1 (G), R606.2, R607.1
LF_LOAD_DRAIN: Q603.3 (D), R612.2
LF_LOAD_GATE: Q603.1 (G), R610.2, R611.1
LF_LOAD_GATED: R610.1; also elsewhere on the board
LF_MID: R616.2, R617.2; also elsewhere on the board
LF_MID_DIV: R614.2, R615.1; also elsewhere on the board
LF_N_DRAIN: Q601.3 (D), R604.1
LF_POWER_ON: R602.1; also elsewhere on the board
LF_P_DRAIN: Q600.3 (D), R603.1
LF_QOD: R600.2; also elsewhere on the board
LF_RECT: R608.1, R609.1, R612.1; also elsewhere on the board
LF_REQUEST: R601.1; also elsewhere on the board
V3V3: R629.1; also elsewhere on the board
V3V3_RF: R613.1; also elsewhere on the board

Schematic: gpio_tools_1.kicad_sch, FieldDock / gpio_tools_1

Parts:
C700, C701: 100n 10V X7R; C_0402_1005Metric
C702, C703: 1u 10V X7R; C_0603_1608Metric
D700, D701, D702, D703, D704, D705, D706: TPD2EUSB30DRTR; Texas_DRT-3
J700: 2x8 2.54mm GPIO 3.3V / 5V-tolerant inputs; PinHeader_2x08_P2.54mm_Vertical_SMD
R700, R701, R702, R703, R704, R705, R706, R707, R708, R709: 51R; R_0402_1005Metric
U700, U701: SN74CB3T3245PWR; TSSOP-20_4.4x6.5mm_P0.65mm
U702: TPS2553DBVR; SOT-23-6

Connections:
AUX_CAPTURE: U701.8 (A7); also elsewhere on the board
EXT_AUX_CAPTURE: U701.12 (B7); also elsewhere on the board
EXT_IBTN_EDGE: U701.13 (B6); also elsewhere on the board
EXT_IR_EDGE: U701.11 (B8); also elsewhere on the board
EXT_TARGET_CS_N: R703.1, U700.15 (B4)
EXT_TARGET_IO0: R708.1, U701.18 (B1)
EXT_TARGET_IO1: R709.1, U701.17 (B2)
EXT_TARGET_IO2: U701.16 (B3); also elsewhere on the board
EXT_TARGET_IO3: U701.15 (B4); also elsewhere on the board
EXT_TARGET_IO4: U701.14 (B5); also elsewhere on the board
EXT_TARGET_MISO: R701.1, U700.17 (B2)
EXT_TARGET_MOSI: R702.1, U700.16 (B3)
EXT_TARGET_RX: R705.1, U700.13 (B6)
EXT_TARGET_SCK: R700.1, U700.18 (B1)
EXT_TARGET_SCL: R706.1, U700.12 (B7)
EXT_TARGET_SDA: R707.1, U700.11 (B8)
EXT_TARGET_TX: R704.1, U700.14 (B5)
GND: C700.2, C701.2, C702.2, C703.2, D700.3 (GND), D701.3 (GND), D702.3 (GND), D703.3 (GND), D704.3 (GND), D705.3 (GND), D706.3 (GND), J700.1, J700.16, U700.10 (GND), U701.10 (GND), U702.2 (GND); also elsewhere on the board
HDR_GND_GUARD: D706.2 (D-); also elsewhere on the board
HDR_TARGET_CS_N: D701.2 (D-), J700.6, R703.2
HDR_TARGET_IO0: D704.1 (D+), J700.11, R708.2
HDR_TARGET_IO1: D704.2 (D-), J700.12, R709.2
HDR_TARGET_IO2: D705.1 (D+), J700.13; also elsewhere on the board
HDR_TARGET_IO3: D705.2 (D-), J700.14; also elsewhere on the board
HDR_TARGET_IO4: D706.1 (D+), J700.15; also elsewhere on the board
HDR_TARGET_MISO: D700.2 (D-), J700.4, R701.2
HDR_TARGET_MOSI: D701.1 (D+), J700.5, R702.2
HDR_TARGET_RX: D702.2 (D-), J700.8, R705.2
HDR_TARGET_SCK: D700.1 (D+), J700.3, R700.2
HDR_TARGET_SCL: D703.1 (D+), J700.9, R706.2; also elsewhere on the board
HDR_TARGET_SDA: D703.2 (D-), J700.10, R707.2; also elsewhere on the board
HDR_TARGET_TX: D702.1 (D+), J700.7, R704.2
IBTN_EDGE: U701.7 (A6); also elsewhere on the board
IR_EDGE: U701.9 (A8); also elsewhere on the board
TARGET_CS_N: U700.5 (A4); also elsewhere on the board
TARGET_ILIM: U702.5 (ILIM); also elsewhere on the board
TARGET_IO0: U701.2 (A1); also elsewhere on the board
TARGET_IO1: U701.3 (A2); also elsewhere on the board
TARGET_IO2: U701.4 (A3); also elsewhere on the board
TARGET_IO3: U701.5 (A4); also elsewhere on the board
TARGET_IO4: U701.6 (A5); also elsewhere on the board
TARGET_MISO: U700.3 (A2); also elsewhere on the board
TARGET_MOSI: U700.4 (A3); also elsewhere on the board
TARGET_POWER_FAULT_N: U702.4 (FAULT_N); also elsewhere on the board
TARGET_RX: U700.7 (A6); also elsewhere on the board
TARGET_SCK: U700.2 (A1); also elsewhere on the board
TARGET_SCL: U700.8 (A7); also elsewhere on the board
TARGET_SDA: U700.9 (A8); also elsewhere on the board
TARGET_TX: U700.6 (A5); also elsewhere on the board
TOOLS_BUS_DISABLE: U700.19 (OE_N), U701.19 (OE_N); also elsewhere on the board
TOOLS_IO_ENABLED: U702.3 (EN); also elsewhere on the board
V3V3: C700.1, C701.1, C702.1, U700.20 (VCC), U701.20 (VCC), U702.1 (IN); also elsewhere on the board
V3V3_TARGET: C703.1, J700.2, U702.6 (OUT); also elsewhere on the board

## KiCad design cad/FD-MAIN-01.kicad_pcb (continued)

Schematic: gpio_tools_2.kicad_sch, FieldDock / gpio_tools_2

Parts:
R710, R711, R712: 51R; R_0402_1005Metric
R713: 0R; R_0402_1005Metric
R714: 226k 1% / ~120mA limit; R_0402_1005Metric
R715: 10k; R_0402_1005Metric
R716: 10k output bleed; R_0402_1005Metric
R717, R718: DNP 4.7k I2C pullup; R_0402_1005Metric
TP700: TARGET_POWER_FAULT_N; TestPoint_Pad_D1.0mm

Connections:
EXT_TARGET_IO2: R710.1; also elsewhere on the board
EXT_TARGET_IO3: R711.1; also elsewhere on the board
EXT_TARGET_IO4: R712.1; also elsewhere on the board
GND: R713.2, R714.2, R716.2; also elsewhere on the board
HDR_GND_GUARD: R713.1; also elsewhere on the board
HDR_TARGET_IO2: R710.2; also elsewhere on the board
HDR_TARGET_IO3: R711.2; also elsewhere on the board
HDR_TARGET_IO4: R712.2; also elsewhere on the board
HDR_TARGET_SCL: R717.2; also elsewhere on the board
HDR_TARGET_SDA: R718.2; also elsewhere on the board
TARGET_ILIM: R714.1; also elsewhere on the board
TARGET_POWER_FAULT_N: R715.2, TP700.1; also elsewhere on the board
V3V3: R715.1; also elsewhere on the board
V3V3_TARGET: R716.1, R717.1, R718.1; also elsewhere on the board

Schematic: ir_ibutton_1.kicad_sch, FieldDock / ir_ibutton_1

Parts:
C710, C713: 1u 10V X7R; C_0603_1608Metric
C711: 4.7u 10V X7R; C_0603_1608Metric
C712: 100n 10V X7R; C_0402_1005Metric_FieldDock_NoSilk
C714: 100n 10V X7R; C_0402_1005Metric
D710, D711, D712: VSMY14940 940nm; Vishay_VSMY14940
D713: BAT54WS-7-F; D_SOD-323
D714: TPD2EUSB30DRTR; Texas_DRT-3
J710: iButton contact probe / DATA GND; Antenna_2Pad_2mm
Q710: DMN2058UW-7; SOT-323_SC-70
Q711: DMN2004K-7; SOT-23
R719, R724, R726, R729, R7100: 100R; R_0402_1005Metric
R720, R725, R727, R730: 100k; R_0402_1005Metric
R721, R722, R723: 82R 1% 0.25W; R_0805_2012Metric
R728: 4.7k; R_0402_1005Metric
U710: TPS22919DCKR; SOT-363_SC-70-6
U711, U713: SN74LVC1G08DBVR; SOT-23-5
U712: TSOP75338TR; Vishay_TSOP753_TR

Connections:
CORE5: C710.1, U710.1 (IN); also elsewhere on the board
EXT_IBTN_EDGE: R729.2; also elsewhere on the board
EXT_IR_EDGE: U712.3 (OUT_N); also elsewhere on the board
GND: C710.2, C711.2, C712.2, C713.2, C714.2, D714.2 (D-), D714.3 (GND), J710.2, Q710.2 (S), Q711.2 (S), R720.2, R727.2, U710.2 (GND), U711.3 (GND), U712.1 (GND_1), U712.4 (GND_4), U713.3 (GND); also elsewhere on the board
IBTN_BUS: D714.1 (D+), J710.1, Q711.3 (D), R728.2, R729.1
IBTN_DRIVE: U713.1; also elsewhere on the board
IBTN_DRIVE_GATED: R726.1, U713.4
IBTN_EDGE: R730.1; also elsewhere on the board
IBTN_GATE: Q711.1 (G), R726.2, R727.1
IBTN_PULLUP_SOURCE: D713.1 (K), R728.1
IR_CARRIER: U711.1; also elsewhere on the board
IR_DRIVE_GATED: R719.1, U711.4
IR_EDGE: R725.1; also elsewhere on the board
IR_GATE: Q710.1 (G), R719.2, R720.1
IR_LED_A0: D710.2 (A), R721.2
IR_LED_A1: D711.2 (A), R722.2
IR_LED_A2: D712.2 (A), R723.2
IR_LED_K: D710.1 (K), D711.1 (K), D712.1 (K), Q710.3 (D)
IR_VS: C713.1, R724.2, U712.2 (VS)
TOOLS5: C711.1, D713.2 (A), R721.1, R722.1, R723.1, R7100.1, U710.6 (OUT)
TOOLS5_QOD: R7100.2, U710.5 (QOD)
TOOLS_IO_ENABLED: U710.3 (ON), U711.2, U713.2; also elsewhere on the board
V3V3: C712.1, C714.1, R725.2, R730.2, U711.5 (VCC), U713.5 (VCC); also elsewhere on the board
V3V3_RF: R724.1; also elsewhere on the board

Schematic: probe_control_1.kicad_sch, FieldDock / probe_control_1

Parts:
C730, C731, C732: 100n 10V X7R; C_0402_1005Metric
D730, D731, D732: TPD2EUSB30DRTR; Texas_DRT-3
J730: SM08B-GHS-TB(LF)(SN) AUX powered probe; JST_GH_SM08B-GHS-TB_1x08-1MP_P1.25mm_Horizontal
R731: 100k; R_0402_1005Metric
R732: 10k; R_0402_1005Metric
R733, R734, R735, R736, R737: 51R; R_0402_1005Metric
U730: SN74LVC1G08DBVR; SOT-23-5
U731: SN74LVC1G04DBVR; SOT-23-5
U732: SN74CB3T3245PWR; TSSOP-20_4.4x6.5mm_P0.65mm

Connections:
CSI_IRQ: U732.4 (A3); also elsewhere on the board
CSI_REQUEST: R731.1, U730.2, U732.5 (A4); also elsewhere on the board
CSI_RX: U732.3 (A2); also elsewhere on the board
CSI_TX: U732.2 (A1); also elsewhere on the board
EXT_AUX_CAPTURE: R737.1; also elsewhere on the board
EXT_LOAD_ENABLE: U730.1; also elsewhere on the board
EXT_PROBE5: J730.1; also elsewhere on the board
GND: C730.2, C731.2, C732.2, D730.3 (GND), D731.3 (GND), D732.2 (D-), D732.3 (GND), J730.2, J730.8, R731.2, U730.3 (GND), U731.3 (GND), U732.10 (GND); also elsewhere on the board
PLUG_CAPTURE: D732.1 (D+), J730.6, R737.2
PLUG_CSI_IRQ: D731.1 (D+), J730.5, R735.2
PLUG_CSI_REQUEST: D731.2 (D-), J730.7, R736.2
PLUG_CSI_RX: D730.2 (D-), J730.4, R734.2
PLUG_CSI_TX: D730.1 (D+), J730.3, R733.2
PROBE_BUS_DISABLE: R732.2, U731.4, U732.19 (OE_N)
PROBE_CSI_IRQ: R735.1, U732.16 (B3)
PROBE_CSI_REQUEST: R736.1, U732.15 (B4)
PROBE_CSI_RX: R734.1, U732.17 (B2)
PROBE_CSI_TX: R733.1, U732.18 (B1)
PROBE_IO_ENABLED: U730.4, U731.2
V3V3: C730.1, C731.1, C732.1, R732.1, U730.5 (VCC), U731.5 (VCC), U732.20 (VCC); also elsewhere on the board

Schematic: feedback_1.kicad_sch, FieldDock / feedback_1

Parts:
BZ740: PKMCS0909E4000-R1; Murata_PKMCS0909
C740, C742: 100n 10V X7R; C_0402_1005Metric
C741: 100n 16V X7R series AC; C_0603_1608Metric
D740: 1N4148W-7-F flyback; D_SOD-123
J740: 3V 8x2mm coin motor / wire attach; Antenna_2Pad_2mm
Q740: DMN2058UW-7; SOT-323_SC-70
R740, R742: 100R; R_0402_1005Metric
R741, R743: 100k; R_0402_1005Metric
U740, U741: SN74LVC1G08DBVR; SOT-23-5

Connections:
BEEP_AC: C741.2, R740.1
BEEP_OUT: C741.1, U740.4
BEEP_P: BZ740.1 (+), R740.2, R741.1
BEEP_PWM: U740.1; also elsewhere on the board
GND: BZ740.2 (-), C740.2, C742.2, Q740.2 (S), R741.2, R743.2, U740.3 (GND), U741.3 (GND); also elsewhere on the board
TOOLS_ENABLE: U740.2, U741.2; also elsewhere on the board
V3V3: C740.1, C742.1, U740.5 (VCC), U741.5 (VCC); also elsewhere on the board
V3V3_RF: D740.1 (K), J740.1; also elsewhere on the board
VIBRO_EN: U741.1; also elsewhere on the board
VIBRO_GATE: Q740.1 (G), R742.2, R743.1
VIBRO_GATED: R742.1, U741.4
VIBRO_LOW: D740.2 (A), J740.2, Q740.3 (D)



Board: 8 copper layers, 40.0 x 94.0 mm, 424 parts (196 on the bottom side), 271 nets.

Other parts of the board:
H1, H2, H3, H4: M2; MountingHole_2.4mm_M2

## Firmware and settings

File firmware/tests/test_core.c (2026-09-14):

/* Copyright (c) 2026 fairank. SPDX-License-Identifier: LicenseRef-FieldDock-NC-1.0 */
#include "fd_core.h"
#include "fd_board_pins.h"
#include <assert.h>
#include <stdio.h>
typedef struct {bool owned,selected,powered,busy;int transactions,unlocks,fail_at;fd_result ready;} fake;
static bool lock_bus(void *p){fake*f=p;if(f->busy)return false;assert(!f->owned);f->owned=true;return true;}
static void unlock_bus(void *p){fake*f=p;assert(f->owned&&!f->selected);f->owned=false;f->unlocks++;}
static void select_bus(void *p,bool a){fake*f=p;assert(f->owned);f->selected=a;}
static fd_result ready_bus(void*p,uint32_t timeout){fake*f=p;assert(f->selected&&timeout==10u);return f->ready;}
static bool powered_bus(void*p){return ((fake*)p)->powered;}
static fd_result transfer_bus(void*p,const uint8_t*tx,uint8_t*rx,size_t n){fake*f=p;
 assert(f->owned&&f->selected&&n==2);f->transactions++;
 /* Check against vendor command bytes, including second status read requiring new CS. */
 assert(tx[0]==(f->transactions==1?0xf0:0xf1));
 if(f->fail_at==f->transactions)return FD_IO;
 rx[0]=0;rx[1]=f->transactions==1?0:0x14;return FD_OK;
}
static void spi_tests(void){fake f={0};fd_cc1101_id id={42,42};
 fd_spi_bus b={&f,lock_bus,unlock_bus,select_bus,ready_bus,transfer_bus,powered_bus};
 assert(fd_cc1101_read_id(&b,&id)==FD_POWER_OFF&&f.transactions==0&&f.unlocks==1);
 f=(fake){0};f.powered=true;f.ready=FD_TIMEOUT;
 assert(fd_cc1101_read_id(&b,&id)==FD_TIMEOUT&&!f.selected&&!f.owned&&id.part==42);
 f=(fake){0};f.powered=true;f.fail_at=2;
 assert(fd_cc1101_read_id(&b,&id)==FD_IO&&id.part==42&&id.version==42&&!f.owned);
 f=(fake){0};f.powered=true;
 assert(fd_cc1101_read_id(&b,&id)==FD_OK&&id.part==0&&id.version==0x14&&f.transactions==2);
 f.busy=true;assert(fd_cc1101_read_id(&b,&id)==FD_BUSY&&f.transactions==2);
 assert(fd_cc1101_read_id(NULL,&id)==FD_INVALID);
}
static fd_source source(fd_cc_current c){fd_source s={0};s.attached_sink=true;s.valid_vbus=true;s.current=c;return s;}
static void policy_tests(void){fd_power_inputs i={0};fd_power_outputs o;
 i.hardware_allow=true;i.tools_requested=true;i.requested_core_ma=400;
 i.phone=source(FD_CC_DEFAULT);o=fd_power_evaluate(&i);assert(!o.tools_permitted&&!o.phone_budget_ok);
 i.phone.usb_configured_500ma=true;o=fd_power_evaluate(&i);assert(o.tools_permitted&&o.selected_core_limit_ma==459);
 i.phone.usb_suspended=true;assert(!fd_power_evaluate(&i).tools_permitted);
 i.phone=source(FD_CC_1500);i.requested_core_ma=460;assert(!fd_power_evaluate(&i).tools_permitted);
 i.requested_core_ma=400;i.aux=source(FD_CC_DEFAULT);o=fd_power_evaluate(&i);assert(o.phone_budget_ok&&!o.tools_permitted&&o.selected_core_limit_ma==0);
 i.aux=source(FD_CC_1500);i.probe_requested=true;i.requested_probe_ma=500;
 o=fd_power_evaluate(&i);assert(o.tools_permitted&&!o.probe_permitted);
 i.aux.current=FD_CC_3000;assert(fd_power_evaluate(&i).probe_permitted);
 i.aux.age_ms=101;assert(!fd_power_evaluate(&i).probe_permitted&&!fd_power_evaluate(&i).tools_permitted);
 i.aux.age_ms=0;i.aux.fault=true;assert(!fd_power_evaluate(&i).tools_permitted);
 i.aux.fault=false;i.stop=true;assert(!fd_power_evaluate(&i).tools_permitted);
 i.stop=false;i.requested_probe_ma=849;assert(!fd_power_evaluate(&i).probe_permitted);
 i.requested_probe_ma=848;i.hardware_allow=false;assert(!fd_power_evaluate(&i).tools_permitted);
 assert(!fd_power_evaluate(NULL).tools_permitted);
}
int main(void){spi_tests();policy_tests();assert(FD_PIN_COUNT==60);puts("PASS: SPI timeout/bus cleanup/atomic ID; source budget/fault/stale/suspend/overload/stop policy; 60 GPIO mappings.");return 0;}

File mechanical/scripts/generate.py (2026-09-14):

# SPDX-License-Identifier: LicenseRef-FieldDock-NC-1.0
# -*- coding: utf-8 -*-
"""Compact FieldDock arrangement, mm. Geometry prototype, not manufacturing release.
Regenerate with Python + Gmsh/OpenCASCADE; never launches KiCad.
"""
from pathlib import Path
import sys,json,math,struct,collections,csv,itertools
import argparse
args=argparse.ArgumentParser()
args.add_argument('--placement',type=Path)
opt=args.parse_args()
O=Path(__file__).resolve().parents[2]
ROOT=O/'mechanical/K';ROOT.mkdir(parents=True,exist_ok=True)
import gmsh
P={"length":100.0,"width":46.0,"height":18.0,"radius":6.0,"wall":1.6,
   "lid_z":16.0,"pcb_width":40.0,"pcb_length":94.0,"pcb_z":5.7,"pcb_thickness":1.6,
   "coil_center_y":10.0,"port_spacing":25.0,"mount_positions":[[-17,-37],[17,-37],[-17,43],[17,43]],
   "status":"PLACEMENT_ENVELOPES_NOT_QUALIFIED_FOR_PRODUCTION"}
f=ROOT/'parameters.json'
if f.exists():P.update(json.loads(f.read_text(encoding='utf-8-sig')))
f.write_text(json.dumps(P,indent=2),encoding='utf-8')
for d in ['parts','preview','checks','layout']:(ROOT/d).mkdir(exist_ok=True)
gmsh.initialize();gmsh.option.setNumber('General.Terminal',0)
gmsh.option.setNumber('Geometry.OCCBoundsUseStl',0)
o=gmsh.model.occ;scene=[];reports=[]
def box(w,h,d,x=0,y=0,z=0):return o.addBox(x-w/2,y-h/2,z,w,h,d)
def cyl(r,h,x=0,y=0,z=0):return o.addCylinder(x,y,z,0,0,h,r)
def fuse(tags):
 if len(tags)==1:return tags[0]
 out,_=o.fuse([(3,tags[0])],[(3,t) for t in tags[1:]])
 assert len(out)==1, out
 return out[0][1]
def cut(a,bs):
 out,_=o.cut([(3,a)],[(3,b) for b in bs])
 assert len(out)==1,out
 return out[0][1]
def rr(w,h,d,r,x=0,y=0,z=0):
 return fuse([box(w-2*r,h,d,x,y,z),box(w,h-2*r,d,x,y,z)]+[cyl(r,d,x+sx*(w/2-r),y+sy*(h/2-r),z) for sx in [-1,1] for sy in [-1,1]])
def housing(w,h,d,r,wall):return cut(rr(w,h,d,r),[rr(w-2*wall,h-2*wall,d,r-wall,z=wall)])
def plate_holes(w,h,d,z=0):
 return cut(rr(w,h,d,3,z=z),[cyl(1.5,d+2,x,y,z-1) for x in [-w/2+4,w/2-4] for y in [-h/2+4,h/2-4]])

def part(name,title,make,color,category='fabricated',offset=(0,0,0),explode=0,notes=''):
 gmsh.model.add(name)
 gmsh.option.setNumber('Mesh.MeshSizeFromCurvature',36)
 gmsh.option.setNumber('Mesh.MinimumCirclePoints',36)
 gmsh.option.setNumber('Mesh.MeshSizeMin',0.15)
 gmsh.option.setNumber('Mesh.MeshSizeMax',4)
 tags=make(); tags=[tags] if isinstance(tags,int) else tags
 if any(offset):o.translate([(3,t) for t in tags],*offset)
 o.synchronize()
 for t in tags:gmsh.model.setEntityName(3,t,name)
 gmsh.write(str(ROOT/'parts'/f'{name}.step'))
 gmsh.model.mesh.generate(2)
 node_tags,xyz,_=gmsh.model.mesh.getNodes()
 nodes={int(n):[float(v) for v in xyz[i*3:i*3+3]] for i,n in enumerate(node_tags)}
 # Gmsh already orients these surface mesh elements for the volume. Do not apply boundary signs twice.
 tris=[]
 for t in tags:
  for dim,signed in gmsh.model.getBoundary([(3,t)],combined=False,oriented=True):
   if dim!=2:continue
   ty,el,conn=gmsh.model.mesh.getElements(2,abs(signed))
   for typ,ns in zip(ty,conn):
    assert int(typ)==2,('Expected linear triangle',typ)
    for i in range(0,len(ns),3):
     tri=[nodes[int(n)] for n in ns[i:i+3]]
     tris.append(tri)
 edges=collections.Counter()
 for tri in tris:
  pts=[tuple(round(v,6) for v in p) for p in tri]
  for i in range(3):edges[tuple(sorted((pts[i],pts[(i+1)%3])))]+=1
 bad=sum(n!=2 for n in edges.values())
 # Binary STL in assembly coordinates, with explicit mm declaration in README.
 with (ROOT/'parts'/f'{name}.stl').open('wb') as f:
  f.write(('FieldDock mm '+name).encode().ljust(80,b'\0'));f.write(struct.pack('<I',len(tris)))
  for a,b,c in tris:
   u=[b[i]-a[i] for i in range(3)];v=[c[i]-a[i] for i in range(3)]
   n=[u[1]*v[2]-u[2]*v[1],u[2]*v[0]-u[0]*v[2],u[0]*v[1]-u[1]*v[0]]
   l=math.sqrt(sum(k*k for k in n)) or 1
   f.write(struct.pack('<12fH',*[k/l for k in n],*a,*b,*c,0))
 bounds=[gmsh.model.getBoundingBox(3,t) for t in tags]
 bb=[min(b[i] for b in bounds) for i in range(3)]+[max(b[i] for b in bounds) for i in range(3,6)]
 volumes=[o.getMass(3,t) for t in tags]
 mesh_volume=sum((a[0]*(b[1]*c[2]-b[2]*c[1])+a[1]*(b[2]*c[0]-b[0]*c[2])+a[2]*(b[0]*c[1]-b[1]*c[0]))/6 for a,b,c in tris)
 mesh_volume_error=abs(mesh_volume-sum(volumes))/sum(volumes)
 assert mesh_volume>0 and mesh_volume_error<0.025,(name,'mesh orientation/volume',mesh_volume,sum(volumes))
 assert all(v>0 for v in volumes) and bad==0,(name,volumes,bad)
 rec=dict(id=name,title=title,color=color,category=category,offset=offset,explode=explode,notes=notes,
          bbox_mm=[round(v,4) for v in bb],volume_mm3=sum(volumes),solids=len(tags),triangles=len(tris),nonmanifold_edges=bad,mesh_signed_volume_mm3=mesh_volume,mesh_volume_relative_error=mesh_volume_error)
 reports.append(rec)
 # A coarser tessellation is used only by the lightweight preview, never the STL.
 gmsh.model.mesh.clear()
 gmsh.option.setNumber('Mesh.MeshSizeFromCurvature',12)
 gmsh.option.setNumber('Mesh.MinimumCirclePoints',12)
 gmsh.option.setNumber('Mesh.MeshSizeMin',0.8)
 gmsh.option.setNumber('Mesh.MeshSizeMax',7)
 gmsh.model.mesh.generate(2)
 ni,nx,_=gmsh.model.mesh.getNodes()
 nd={int(n):[float(v) for v in nx[i*3:i*3+3]] for i,n in enumerate(ni)}
 display=[]
 for t in tags:
  for dim,face in gmsh.model.getBoundary([(3,t)],combined=False,oriented=True):
   if dim!=2:continue
   ty,ee,con=gmsh.model.mesh.getElements(2,abs(face))
   for typ,ns in zip(ty,con):
    assert int(typ)==2
    for i in range(0,len(ns),3):display.append([nd[int(n)] for n in ns[i:i+3]])
 rec=dict(rec,display_triangles=len(display),mesh=[[[round(v,3) for v in p] for p in t] for t in display])
 scene.append(rec)
 print(name,len(tris),'triangles',flush=True)
 return rec
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

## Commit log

2026-09-14 Publish checked FieldDock K engineering prototype package
    Full PCB routing, native ERC/DRC, independently checked Gerber/drill exports, editable CAD, mechanical models and basic drivers. Bare-PCB prototype files only; assembled hardware remains untested. Or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
2026-09-14 Publish FieldDock hardware, mechanical CAD and verification evidence
    [BOM-review.csv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]
